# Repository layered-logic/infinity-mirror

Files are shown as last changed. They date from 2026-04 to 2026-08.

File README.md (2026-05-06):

---
title: Infinity Mirror — Project README
type: overview
status: active
tags: [readme, overview]
---

# Infinity Mirror

### A Human-Centered Design Engineering Venture by [Layered Logic](https://github.com/layered-logic)

---

> *Design a system, not just a gadget.*

An ESP32-powered infinity mirror built from the ground up — not just as a piece of hardware, but as a **complete product system**: interaction design, sustainable manufacturing, made-to-order operations, and a venture-ready business model.

This repository documents the full journey from prototype to pre-production, serving as both an engineering portfolio and a living product development case study.

---

## The Product

| | |
|---|---|
| **What** | App-connected LED infinity mirror with customizable patterns and colors |
| **How** | ESP32 microcontroller, WS2812B addressable LEDs, BLE/Wi-Fi, native mobile app |
| **Why** | Personalized ambient lighting that reflects the owner — standard designs or fully bespoke |

**Base model:** 6" x 6" — standard designs starting at $50
**Custom:** Bespoke shapes, sizes, patterns, and frame materials — designed with the customer

---

## What Makes This Different

This isn't just a build log. Every design decision is grounded in **human-centered design engineering**:

- **Stakeholder Mapping** — Understanding everyone who touches the product, from buyer to end-of-life
- **Sustainability Audit** — Full life cycle analysis. Replaceable LEDs. Recyclable frames. Documented environmental impact
- **Right-to-Repair** — A published repair guide so owners can maintain their own mirrors
- **Service Blueprint** — The complete user journey mapped from discovery to daily use to troubleshooting
- **User Research** — Real conversations with real people shaping every interface and business decision

---

## Project Structure

```
├── sprint_plan.md          # 11-week development sprint (Spring 2026), narrative
├── sprint_log.md           # Daily progress narrative
├── tasks.md                # Structured task registry (LL-NNN IDs, status, dates)
├── task_log.md             # Append-only event history
├── tools/                  # Internal business utilities
│   └── pricing/            # Streamlit COGS/pricing calculator dashboard
├── Firmware/               # ESP32 firmware (V1) + STM8 reference (Basic SKU)
├── App/                    # React Native mobile app (LLogic)
├── docs/                   # HCDE deliverables, business model, specs, case study
│   ├── task-format-v2.md   # Task ID scheme + registry format spec
│   ├── stakeholder-map
│   ├── sustainability-audit
│   ├── repair-index        # Sub-MOC for the repair docs
│   ├── service-blueprint
│   └── venture-readiness
├── Failure_Modes/          # 17 failure-mode files with user-repair paths
├── Assembly_docs/          # Production line operations
└── assets/                 # Product photography, brand identity, media
```

Tasks carry stable `LL-NNN` IDs (e.g., `LL-001`, `LL-035-2-1`). Sprint plan and log reference them inline as `[LL-NNN](tasks.md#LL-NNN)`; the registry is the structured source of truth, the narrative files are the human-readable story. Format spec at [docs/task-format-v2.md](docs/task-format-v2.md).

---

## Milestones

| Target | Milestone |
|---|---|
| Apr 18 | Business foundation — competitive analysis, pricing model, stakeholder map, sustainability goals |
| May 9 | Brand identity finalized, app UI designed, PCB hardware validated, supply chain mapped |
| May 30 | Go-to-market ready — service blueprint, repair manual, media assets, pre-production mirror built |
| Jun 12 | Portfolio case study complete. Venture readiness delivered. **Launch-ready.** |

---

## Tech Stack

| Layer | Technology |
|---|---|
| Microcontroller | ESP32 (Wi-Fi + BLE) |
| LEDs | WS2812B (Neopixel-compatible) addressable RGB |
| PCB Design | KiCad |
| Firmware | C/C++ (PlatformIO) |
| Mobile App | TBD — native (iOS/Android) |
| 3D Visualizer | React + Three.js (React Three Fiber) |
| Prototyping | Figma (app UX/UI) |

---

## Background

This project evolved from several earlier experiments:

- An **STM8 LED controller** with button-driven color cycling and animations
- A **React Three.js visualizer** for previewing mirror designs in 3D
- An **ESP32 strip tester** for validating LED configurations
- **Custom KiCad PCB designs** for a purpose-built infinity mirror controller

The independent study takes these building blocks and asks: *What would it take to turn this into a real, sellable, supportable product — and do it responsibly?*

---

## License

TBD

---

## Navigating This Repo

- [**index.md**](index.md) — Map of Content / home note (start here for any session)
- [Sprint Plan](sprint_plan.md) · [Sprint Log](sprint_log.md) — 11-week plan and daily narrative
- [Task Registry](tasks.md) · [Task Event Log](task_log.md) · [Format Spec](docs/task-format-v2.md) — structured task tracking
- [docs/](docs/) — HCDE artifacts, business, engineering, meeting logs
- [Assembly_docs/](Assembly_docs/) — production-line ops
- [assets/](assets/) — design assets (logo, color, type, photos, Figma exports)
- [tools/](tools/) — internal utilities (pricing calculator)

---

<p align="center"><em>Layered Logic — Spring 2026</em></p>

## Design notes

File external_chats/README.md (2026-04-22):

---
title: External Chats — Archive
type: asset-folder
status: active
tags: [external-chat, archive]
---

# External Chats — Archive

Exports of AI conversations (Gemini, Claude, etc.) that produced artifacts now living in `docs/` or `Assembly_docs/`. Kept for provenance and for future sessions that need to replay the reasoning.

## Convention

Each chat is stored as both the raw export (`.json` for Gemini exporter, `.md` for Claude sessions) **and** a companion `.md` file with:
- YAML frontmatter (`type: external-chat-log`, `source:`, `exported:`, `status:`, `tags:`)
- A `## Summary` section linking to the artifacts the conversation produced
- The full conversation body rendered as `### User` / `### Gemini` (or `### Claude`) headers

`status: superseded` on a chat means a later export of the same thread exists — prefer the superseding file.

## Files

| Chat | Date | Source | Produced |
|---|---|---|---|
| [Gemini-Market_Research.md](Gemini-Market_Research.md) | Apr 6 | Gemini | Stakeholder map + Market Analysis Report |
| [Gemini-Sharing GitHub Repos with Gemini.md](Gemini-Sharing%20GitHub%20Repos%20with%20Gemini.md) *(superseded)* | Apr 2 | Gemini | — earlier partial export of the same thread |
| [Gemini-Small Business Bank Account Recommendation.md](Gemini-Small%20Business%20Bank%20Account%20Recommendation.md) | Apr 9 | Gemini | Mercury/Chase/Relay evaluation → bank application |
| [LED_Mirror_Project_Brief.md](LED_Mirror_Project_Brief.md) | Apr 14 | Claude | Factory operations plan + Assembly_docs/ artifacts |

## Regenerating markdown from JSON

`convert_chats.py` in this folder converts Gemini JSON exports to markdown. Summaries are configured by hand inside the script (they require reading the thread) — add a new entry to the `configs` list before running it on a new export.

```bash
cd external_chats && python convert_chats.py
```

## Related

- [Sprint Log](../sprint_log.md) · [Sprint Plan](../sprint_plan.md)
- [docs/stakeholder-map.md](../docs/stakeholder-map.md) · [docs/Market Analysis Report.md](../docs/Market%20Analysis%20Report.md)

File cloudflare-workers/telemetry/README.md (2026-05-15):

---
title: Telemetry Worker — deploy + test
type: engineering
phase: 2
tags: [server, cloudflare, telemetry, LL-057-C]
---

# `ll-mirror-telemetry` Cloudflare Worker

Accepts opt-in telemetry beacons from Layered Logic mirrors on
`telemetry.layeredlogic.cc/v1/beacon`. Stores each beacon in a KV
namespace with a 90-day TTL plus a no-TTL "latest snapshot per device"
pointer. Firmware emission lives in [firmware-spec §4.10](../../docs/firmware-spec.md),
implementation tracked by [LL-057-C](../../tasks.md#LL-057-C).

## First-time setup

```powershell
cd cloudflare-workers/telemetry
npm install                                  # pull wrangler + workers-types
npx wrangler login                           # browser auth into Bill's CF account
npx wrangler kv namespace create LL_TELEMETRY_KV
# → copy the id into wrangler.toml's [[kv_namespaces]] block
npx wrangler deploy                          # first deploy publishes the worker
```

Then in the Cloudflare dashboard:
1. Add the route `telemetry.layeredlogic.cc/v1/*` → Worker `ll-mirror-telemetry`.
2. Add a DNS CNAME `telemetry` → `<workers-subdomain>.workers.dev` (or use Custom Domain).
3. Verify with the healthz endpoint:
   ```powershell
   curl https://telemetry.layeredlogic.cc/v1/healthz
   # → {"ok":true,"service":"ll-mirror-telemetry"}
   ```

## Beacon schema

```json
{
  "v": 1,
  "device_id": "b2332c",
  "fw_version": "651afe8-dirty",
  "uptime_s": 12345,
  "heap_free_min": 89000,
  "boot_reason": "POWERON_RESET",
  "rssi": -52,
  "led_count": 66,
  "panic": {
    "filename": "main.c",
    "line": 42,
    "task_name": "state_bus"
  }
}
```

- `device_id` is the firmware's `ll_device_id_get()` — lowercase 6-hex MAC suffix.
- `fw_version` matches `esp_app_get_description()->version`.
- `panic` is omitted when no panic happened since the last successful beacon.

The Worker validates shape strictly (rejects garbage with 400) but
tolerates extra fields silently for forward-compatibility.

## Endpoints

| Method | Path | Purpose |
|---|---|---|
| `POST` | `/v1/beacon` | Submit a beacon. Returns `{ok, stored_at}` or `{ok:false, error}`. |
| `GET` | `/v1/healthz` | Liveness probe. Always 200. |
| `GET` | `/v1/latest/<device_id>` | Return the latest beacon for one device. 404 if none yet. |

## Test with a mock beacon

```powershell
curl -X POST https://telemetry.layeredlogic.cc/v1/beacon `
  -H 'content-type: application/json' `
  --data '{"v":1,"device_id":"b2332c","fw_version":"mock-0.0.1","uptime_s":42,"heap_free_min":80000,"boot_reason":"POWERON_RESET","rssi":-55,"led_count":66}'

# Then:
curl https://telemetry.layeredlogic.cc/v1/latest/b2332c
```

## Local dev (no real KV writes)

```powershell
npx wrangler dev
# → http://127.0.0.1:8787
curl -X POST http://127.0.0.1:8787/v1/beacon -H 'content-type: application/json' --data '{...}'
```

Local KV is miniflare-backed and ephemeral. To reset: stop + restart `wrangler dev`.

## Storage model

| Key pattern | TTL | Purpose |
|---|---|---|
| `beacon:<device_id>:<unix_ms>` | 90 days | One entry per submitted beacon. Enables future "last N beacons" / time-series queries via `LL_TELEMETRY_KV.list({prefix:"beacon:<id>:"})`. |
| `latest:<device_id>` | none | Most recent beacon for O(1) "is device alive + what was its state?" lookups. |

## Privacy / data retention

- Beacons are **opt-in** via the app's Settings → Telemetry toggle (`set_state {telemetry_enabled: true/false}`).
- `device_id` is a pseudonymous 6-hex MAC suffix; not linked to user identity.
- No location data, no IP retention (CF logs hold IPs briefly but we don't persist).
- 90-day TTL on per-beacon entries; latest pointer retained until overwritten by a fresh beacon.

## Auth

None on `POST /v1/beacon` for V1. The worst an attacker with a known `device_id` can do is submit false metrics. Real authentication should land alongside [LL-057-D](../../tasks.md#LL-057-D) (paired-mode HMAC), at which point the beacon envelope can carry an HMAC computed against the device's shared secret. Until then, ship as open and trust the Cloudflare-level rate limiting.

## Not yet built (deferred)

- Dashboard UI to view recent beacons.
- Alerting on panic payloads.
- Aggregation queries (heap LWM trend across devices, etc.).
- Data export (R2 dump for long-term cold storage).

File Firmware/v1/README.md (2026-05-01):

---
title: Firmware v1 — Layered Logic Infinity Mirror
type: engineering
phase: 2
status: scaffold — blink-level only
tags: [firmware, esp32, esp-idf, scaffold]
---

# Firmware v1

Greenfield proprietary firmware for the Layered Logic Infinity Mirror. Built on ESP-IDF with C. Replaces the ESPHome YAML prototype in `../ESP32/prototype_ESPHome_Version.yaml`.

Currently **scaffold only** — directory tree + blink-level `main.c` per variant. Real implementation work begins week 5.

## Architecture

See the spec docs in [../../docs/](../../docs/):
- [firmware-architecture-scoping.md](../../docs/firmware-architecture-scoping.md) — locked decisions
- [firmware-spec.md](../../docs/firmware-spec.md) — component-level spec
- [firmware-security.md](../../docs/firmware-security.md) — signing, OTA, auth, telemetry
- [control-protocol-spec.md](../../docs/control-protocol-spec.md) — wire protocol
- [button-interface.md](../../docs/button-interface.md) — UX contract

## Layout

```
Firmware/v1/
  core/                    # 80%+ of codebase — shared across variants
    led_driver/            # WS2812 via RMT
    pattern_interp/        # pattern runtime + interpreter
    button/                # debounce, gesture state machine
    state_bus/             # unified state + pub/sub
    provisioning/          # wifi_prov_mgr wrapper (BLE + SoftAP)
    transport/             # WebSocket + HTTP + BLE
    mdns/                  # discovery
    ota/                   # signed OTA + A/B rollback
    nvs/                   # persistence
    auth/                  # HMAC envelope (paired mode)
    telemetry/             # opt-in beacon
  variants/
    standard/              # Pro — no Matter
    matter/                # Pro+ — adds esp-matter stack
  boards/                  # compile-time hardware abstraction
    board.h                # abstract interface
    c6_devkit.h            # ESP32-C6-DevKitC-1 (both demo units)
    c3_devkit.h            # ESP32-C3-DevKitM-1 (V0 reference)
    prod_v1_pro.h          # Pro shipping PCB (stub — TBD at layout)
    prod_v1_pro_plus.h     # Pro+ shipping PCB (stub — TBD at layout)
  webapp/                  # device-hosted browser UI (embedded at build)
  tests/                   # host-side unit tests for pure-C modules
```

## Build targets (planned)

- `standard-c6_devkit` — Pro firmware on C6 dev board (demo)
- `standard-c3_devkit` — Pro firmware on C3 dev board (legacy V0 hardware)
- `matter-c6_devkit` — Pro+ firmware on C6 dev board (demo)
- `standard-prod_v1_pro` — Pro shipping (pending PCB)
- `matter-prod_v1_pro_plus` — Pro+ shipping (pending PCB)

## Status

Every source file is currently a stub. This scaffold exists to:
- Lock the directory structure so spec docs have a concrete target
- Make `idf.py build` work from day one (even if all it does is print "hello")
- Let CI spin up per-variant build jobs as modules get real implementations

## Building

PowerShell only — see [reference_esp_idf_setup memory](../../.claude/projects/C--Users-bowhi-Desktop-Independent-Study/memory/reference_esp_idf_setup.md). git-bash isn't supported by the IDF Windows installer's wrapper scripts.

```powershell
$env:IDF_TOOLS_PATH = "C:\Espressif"
& "C:\Espressif\frameworks\esp-idf-v5.5.4\export.ps1"
cd Firmware\v1
```

**First build in a fresh worktree** — two prerequisites the build won't auto-handle:

```powershell
# 1. Webapp dist must exist before idf.py build runs (webapp_assets component
#    embeds the gzipped output). Skip this and CMake fails with
#    "Webapp asset missing: webapp/dist/index.html.gz".
cd webapp
npm install
npm run build
cd ..

# 2. Pick the board + chip target. CMakeLists defaults to c6_devkit / esp32c6.
#    The XIAO ESP32-C3 prototype needs c3_devkit / esp32c3 instead — and
#    set-target must be passed BOTH the board flag and the chip target;
#    skipping it means the build silently uses the previous target from
#    the local sdkconfig. Verify before assuming:
idf.py -DLL_BOARD=c3_devkit set-target esp32c3
Select-String "^CONFIG_IDF_TARGET=" sdkconfig    # should print esp32c3

# 3. Build. Pass PROJECT_VER explicitly when iterating over OTA — esp_https_ota
#    rejects images whose version string equals the running version
#    (ESP_ERR_INVALID_VERSION), and `git describe --dirty` produces the same
#    suffix when only uncommitted changes differ between iterations.
idf.py -DLL_BOARD=c3_devkit -DPROJECT_VER="iter-$(Get-Date -Format yyMMdd-HHmm)" build
```

**Subsequent builds** in the same worktree — just `idf.py build`. The board + target persist in the (gitignored) sdkconfig.

**Switching chip targets** (e.g. C3 ↔ C6) — must `Remove-Item sdkconfig` first; `set-target` doesn't reliably overwrite a sdkconfig from a previous chip.

## Flashing

USB: `idf.py -p COM<n> flash monitor`

OTA: see [docs/ota-dev-runbook.md](../../docs/ota-dev-runbook.md) — host the bin via `python -m http.server 8000` in `build/`, send `start_ota` from the app or wscat.

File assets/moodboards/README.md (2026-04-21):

---
title: Moodboards — Brand References
type: asset-folder
status: active
tags: [brand, moodboard, references, research]
---

# Moodboards — Brand References

Five external references provided by Bill (Apr 20, 2026) that informed the locked brand direction. This file is the **link + one-line summary index**; full per-reference analysis (palette, type, layout, signature devices, pulls, anti-moves) lives in [docs/brand-research-notes.md](../../docs/brand-research-notes.md).

Image captures of each reference should be added to this folder as `reference-{n}-{slug}.png` for offline reference — useful if a case-study URL changes or goes dead.

---

## The five references

### 1. Paris Electronic Week 2022 — Diplomatie Studios
[the-brandidentity.com](https://the-brandidentity.com/project/diplomatie-studios-identity-for-paris-electronic-week-2022-is-a-kaleidoscopic-collision-of-colour)

Kaleidoscopic CMYK collisions (electric magenta, acid yellow, cyan) pinned by rigid typographic frames. **Pull:** the "light bleed pinned under a hard type lockup" move. **Avoid:** multi-hue rainbow — would dilute the indigo anchor.

### 2. SPRING Performing Arts Festival — LAVA
[lava.nl](https://lava.nl/progress/spring-performing-arts-festivals-new-identity/)

Soft photographic gradient blobs ("spring bloom") used as a recurring container, paired with crisp editorial typography. **Pull:** the soft color-field shape as a recurring container (signature device #4 in the brand system). **Avoid:** pastel warmth and book-like whitespace.

### 3. Adam Ho — Personal site + Archetype interview
[adamho.com](https://www.adamho.com/) · [archetype.fund interview](https://www.archetype.fund/media/in-conversation-with-adam-ho)

Bill's reference for a disciplined solo-founder personal-brand voice. Relevant as a model for the Layered Logic parent-brand posture while the venture is still solo.

### 4. Intrinsic — Pentagram identity + Felix Faire generative system
[pentagram.com](https://www.pentagram.com/work/intrinsic) · [felixfaire.com](https://felixfaire.com/work/intrinsic)

**The primary "gradients + hard outlines" reference.** Volumetric soft gradients (fog, light fields) sitting *behind* razor-thin wireframe geometry — two layers that never blend. **Pull:** the visual logic of wireframe-over-bloom (signature device #3). **Avoid:** the heavy 3D rendering workload — adopt the grammar, don't out-render a CG studio.

### 5. IBM Quantum — Field.io brand visuals
[field.io](https://field.io/work/ibm-quantum-brand-visuals)

Scientific-instrument framing — flowing ribbon gradients "annotated" with mono labels and tick marks at the edges. The "annotated sublime." **Pull:** the annotation layer — mono labels, tick marks, thin rules (signature device #2, the mono tick-mark frame). **Avoid:** IBM blue — the anchor here is indigo (cooler, more saturated).

---

## Shared grammar extracted from these five

From [brand-research-notes.md §Synthesis](../../docs/brand-research-notes.md):

> Soft volumetric color (gradient, fog, bloom, light field) treated as the *subject*, pinned and measured by a hard, precise typographic/geometric overlay. The soft thing is ambient and emotional; the hard thing is technical and first-person. **Tension between the two is the brand.**

The five references converge on: dark-mode ground, one saturated anchor color (for this brand, Indigo Reference `#4A25FF`), disciplined grotesque + mono type pairing, and hard 1px rules framing soft gradient bloom.

---

## To add

- [ ] `reference-1-paris-electronic-week.png` — screenshot capture of case study
- [ ] `reference-2-spring-lava.png` — screenshot of festival identity
- [ ] `reference-3-adam-ho.png` — personal site hero + interview capture
- [ ] `reference-4-intrinsic-pentagram.png` + `reference-4-intrinsic-felix-faire.png` — identity + motion captures
- [ ] `reference-5-ibm-quantum.png` — Field.io case study capture

Keep captures at reasonable resolution (~1920px wide); these are for offline reference and brand-narrative documents, not production imagery.

---

## Related

- [docs/brand-research-notes.md](../../docs/brand-research-notes.md) — full per-reference analysis and five signature visual devices
- [docs/brand-positioning.md §5](../../docs/brand-positioning.md) — decisions informed by these references
- [assets/README.md](../README.md) — folder conventions across all design assets

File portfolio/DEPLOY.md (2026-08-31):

# Portfolio — "Process" (LL-061) · deploy & embed

Self-contained static page (`index.html` + `assets/`). Hosted on **Cloudflare Pages**.

- **Project:** `layered-logic-process` (account: bowhite9317@gmail.com)
- **Production URL:** https://layered-logic-process.pages.dev/
- **Intended custom domain:** `process.layeredlogic.cc` (see below)

## Redeploy (after editing the page)

From the repo root, with wrangler authenticated (`npx wrangler whoami`):

```bash
npx wrangler pages deploy portfolio --project-name=layered-logic-process --branch=main --commit-dirty=true
```

Only the `portfolio/` folder is uploaded — nothing else from the repo. Each run prints a unique
preview URL; the production URL above always serves the latest `main` deploy.

## Custom domain (process.layeredlogic.cc)

DNS for layeredlogic.cc is on Cloudflare, so this is one step:
Dashboard → Workers & Pages → `layered-logic-process` → Custom domains → **Set up a domain** →
`process.layeredlogic.cc` → Cloudflare auto-creates the CNAME and provisions the cert.

## Embed in Framer (auto-resizing)

Framer → Assets → Code → New Component. The page broadcasts its height via `postMessage`
(`{type:"ll-process-height", height}`) on load, resize, image load, and every node expand/collapse,
so the frame grows with the content (including when a visitor opens a node).

```tsx
import { useState, useEffect } from "react"

export default function ProcessEmbed() {
    const [height, setHeight] = useState(4000)
    useEffect(() => {
        function onMsg(e: MessageEvent) {
            if (e.data?.type === "ll-process-height" && typeof e.data.height === "number") {
                setHeight(e.data.height)
            }
        }
        window.addEventListener("message", onMsg)
        return () => window.removeEventListener("message", onMsg)
    }, [])
    return (
        <iframe
            src="https://layered-logic-process.pages.dev/"
            style={{ width: "100%", height, border: 0, display: "block" }}
            title="Layered Logic — Process"
            scrolling="no"
        />
    )
}
```

Set the component to full-width on the Framer page. Swap `src` to the custom domain once it's live.

### Note on sticky headers
With auto-height (frame grows to full content, parent page scrolls), the page's sticky lane/phase
headers won't pin — they scroll by like normal content. That's the right feel for an embedded story.
If you'd rather keep them pinned, give the iframe a fixed height (e.g. `height: "90vh"`) so it
scrolls internally instead.

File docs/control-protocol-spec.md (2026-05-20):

---
title: Control Protocol Spec — App ↔ Device
type: engineering
phase: 2
week: 4
date: 2026-04-22
status: draft — initial lock from firmware-architecture-scoping §5.5 decision
tags: [engineering, firmware, protocol, websocket, ble, http]
---

# Control Protocol Spec — App ↔ Device

**Prepared by:** William White
**Date:** April 22, 2026
**Status:** First draft — defines the shared wire protocol used by mobile app, webapp, and any third-party controller

---

## 1. Purpose

This spec defines the **wire protocol** between controllers (LL mobile app, webapp, HA custom integration, third-party clients) and the mirror firmware.

It is transport-agnostic: the same message envelope rides over WebSocket, HTTP, and BLE. Client implementations should target this spec — not the transports directly — so that fallback between transports (Wi-Fi → BLE) doesn't require protocol rework.

Implements [firmware-architecture-scoping §5.5](firmware-architecture-scoping.md#55-app--device-protocol). Auth model detailed in [firmware-security.md §5](firmware-security.md#5-local-authentication).

---

## 2. Transports

Three transports, same envelope across all.

| Transport | When | Endpoint | Notes |
|---|---|---|---|
| **WebSocket** | Primary runtime; controller on same LAN as device | `ws://<host>/ws` on port 80 | Bidirectional, state broadcasts to all connected clients |
| **HTTP REST** | One-shot ops; scripts, shortcuts, webapp boot | `http://<host>/api/*` on port 80 | No persistent connection; device responds synchronously |
| **BLE GATT** | Fallback when no Wi-Fi or during pairing | Custom service UUID (TBD) | Same message envelope wrapped in BLE notify/write |

### 2.1 Discovery order

Client should try in sequence:
1. **Cached last-known IP** from NVS or app storage (instant, stale-tolerant)
2. **mDNS query** for `_layeredlogic._tcp.local.` on local network
3. **BLE scan** for the device's advertised service UUID (only finds the device if it's in pairing mode OR running its BLE fallback mode due to Wi-Fi being down)

No manual IP entry in V1. If all three fail: UI surfaces a diagnostic ("device unreachable — check Wi-Fi or hold reset button to re-pair").

### 2.2 mDNS record

Published by device when Wi-Fi connected:
- Service: `_layeredlogic._tcp.local.`
- Hostname: `layered-logic-mirror-<device_id_short>.local`
- TXT record: `variant=standard|matter`, `version=<fw_version>`, `id=<device_id_short>`, `auth=open|paired`

Clients filter on service type + optional `id` to find a specific device among multiple.

---

## 3. Message Envelope

All messages — request and response, WebSocket and HTTP and BLE — use the same envelope.

### 3.1 Request envelope

```json
{
  "op": "set_state",
  "req_id": "7b3c...",
  "ts": 1745280000,
  "payload": { ... },
  "hmac": "<hex>"
}
```

| Field | Type | Required | Description |
|---|---|---|---|
| `op` | string | yes | Operation name — see §4 |
| `req_id` | string (UUIDv4) | yes | Client-generated. Device echoes in response for correlation. |
| `ts` | int | yes | Monotonic counter; epoch seconds recommended. In paired mode the device rejects a frame whose `ts` is below the highest already accepted on that connection (`stale_ts`). No absolute-time check — the device has no wall clock. See [firmware-security §5.4](firmware-security.md#54-hmac-envelope). |
| `payload` | object | varies | Op-specific data — see §4 |
| `hmac` | string (hex) | only in paired mode | HMAC-SHA256 over the frame text preceding the `,"hmac":` token (`hmac` is always the last key), keyed on the shared secret. Required in paired mode; ignored in open mode. |

### 3.2 Response envelope

```json
{
  "op": "set_state",
  "req_id": "7b3c...",
  "ok": true,
  "result": { ... },
  "error": null
}
```

| Field | Type | Description |
|---|---|---|
| `op` | string | Echoes the request op |
| `req_id` | string | Echoes the request req_id |
| `ok` | bool | Success flag |
| `result` | object \| null | Op-specific result on success |
| `error` | object \| null | `{ code, message }` on failure |

### 3.3 State broadcast envelope

When device state changes (from any controller input including physical button), device broadcasts to **all connected WebSocket clients**:

```json
{
  "op": "state",
  "ts": 1745280000,
  "state": { ... current full state ... }
}
```

No `req_id` (unsolicited). No `hmac` on broadcasts (broadcasts are authoritative device state, not commands — HMAC is for authenticating commands, not facts).

---

## 4. Operations

### 4.1 Core operations (required on all transports)

| Op | Description | Request payload | Response result |
|---|---|---|---|
| `ping` | Liveness check | `{}` | `{ "fw_version": "...", "uptime_s": 12345 }` |
| `get_state` | Fetch current full state | `{}` | State object — see §5 |
| `set_state` | Partial state update | Partial state object | Updated state object |
| `get_info` | Device metadata | `{}` | `{ device_id, variant, hw_board, fw_version, led_count, auth_mode }` |

### 4.2 Pattern operations

| Op | Description | Request payload | Response result |
|---|---|---|---|
| `list_patterns` | List stored patterns | `{}` | `{ "patterns": [{ id, name, builtin }] }` |
| `get_pattern` | Fetch one pattern definition | `{ "id": "..." }` | Pattern definition — see §6 |
| `upload_pattern` | Add or replace a pattern | Pattern definition | `{ "id": "..." }` |
| `delete_pattern` | Remove a user pattern | `{ "id": "..." }` | `{}` |

### 4.3 Auth operations

| Op | Description | Request payload | Response result |
|---|---|---|---|
| `set_auth_mode` | Change between open + paired | `{ "mode": "open"\|"paired", "secret": "..." }` | `{ "mode": "..." }` |
| `rotate_secret` | Change shared secret (paired mode only) | `{ "old_secret": "...", "new_secret": "..." }` | `{}` |

### 4.4 OTA operations

| Op | Description | Request payload | Response result |
|---|---|---|---|
| `get_update_status` | Is there an update? | `{}` | `{ available: bool, version: "...", changelog: "..." }` |
| `apply_update` | User-triggered update now | `{}` | `{}` — device reboots into new version |

### 4.5 Telemetry operations

| Op | Description | Request payload | Response result |
|---|---|---|---|
| `set_telemetry` | Enable / disable | `{ "enabled": bool }` | `{ "enabled": bool }` |
| `peek_telemetry` | View pending beacon | `{}` | The exact bytes that would be sent next |

---

## 5. State Object

The canonical state object returned by `get_state` and broadcast on change:

```json
{
  "on": true,
  "pattern_id": "color_wipe",
  "base_color": "#3214FF",
  "brightness": 80,
  "led_count": 32,
  "auth_mode": "open",
  "telemetry_enabled": false,
  "id": "b2332d",
  "name": "Living Room"
}
```

| Field | Type | Description |
|---|---|---|
| `on` | bool | Power state |
| `pattern_id` | string | Currently-running pattern ID |
| `base_color` | string | Hex `#RRGGBB` — the single-press advance color (see [button-interface §4.3](button-interface.md#43-base-color-cycle-single-press-semantics)) |
| `brightness` | int (0–100) | One of the 4 discrete steps: 25 / 50 / 75 / 100 |
| `led_count` | int | Read-only (set at provisioning or from board header) |
| `auth_mode` | string | `"open"` or `"paired"` |
| `telemetry_enabled` | bool | User opt-in status |
| `id` | string | Read-only. Lowercase 6-hex MAC suffix — same suffix the mDNS hostname and SoftAP SSID expose. Stable across factory resets. |
| `name` | string | User-set device name; empty when unnamed. Settable via `set_state`. Clients display `name` if non-empty, else fall back to `id`. |

Partial updates via `set_state` — send only the fields changing. Device broadcasts full state after every change.

`id` is read-only and cannot be set via `set_state`; setting `name` is the user-rename surface.

---

## 6. Pattern Definition Format

### 6.1 V1 — built-in patterns only

V1 ships with 7 hardcoded patterns, fully defined in [pattern-dictionary.md](pattern-dictionary.md). Their IDs (wire format):

`solid`, `rainbow`, `scanner`, `spinner`, `random`, `breathing`, `twinkle`

`list_patterns` returns these with `builtin: true`. `upload_pattern` and `delete_pattern` return `error: "unsupported_in_v1"` until V2.

### 6.2 V2 — declarative user-uploaded patterns (deferred)

Shape (illustrative, not final):

```json
{
  "id": "my_pattern",
  "name": "My Pattern",
  "uses_base_color": true,
  "frames": [
    { "duration_ms": 100, "leds": [["base", 0, 1, 2], ["off", 3, 4, 5]] },
    { "duration_ms": 100, "leds": [["off", 0, 1, 2], ["base", 3, 4, 5]] }
  ],
  "loop": true
}
```

Full grammar gets its own spec doc when the app's pattern-editor UI is designed. Deferred because no V1 client produces these — app doesn't exist yet.

**Upload size limit (when V2 ships):** 16KB per pattern (NVS budget). Larger patterns rejected with `error: "pattern_too_large"`.

---

## 7. Transport-Specific Details

### 7.1 WebSocket

- Endpoint: `ws://<host>/ws`
- Max concurrent clients: **8**. Ninth connection refused with close code 1013 ("try again later").
- Per-IP rate limit: 10 messages/sec. Exceeding results in close code 1008.
- Ping/pong: device sends ping every 30s, closes connection if no pong within 60s.
- On state change (from any source): device broadcasts `{"op":"state", ...}` to all connected clients.

### 7.2 HTTP REST

Convenience wrapper over ops. Every op reachable via HTTP for curl-friendliness:

| Method + path | Op |
|---|---|
| `GET /api/state` | `get_state` |
| `POST /api/state` | `set_state` (body = payload) |
| `GET /api/info` | `get_info` (V1: tiny discovery payload — see below) |
| `POST /api/ping` | `ping` |
| `GET /api/patterns` | `list_patterns` |
| `POST /api/patterns` | `upload_pattern` |
| `DELETE /api/patterns/:id` | `delete_pattern` |

**V1 `GET /api/info` (implemented):** lightweight HTTP-only sentinel + identity payload, used by the LL app's subnet-scan discovery to (a) confirm an IP is a Layered Logic mirror and (b) read its `id` + `name` for the multi-mirror picker without opening a WebSocket. Response shape:

```json
{ "product": "layered-logic-mirror", "id": "b2332d", "name": "Living Room", "fw_version": "1b86d5e" }
```

Returned with `Content-Type: application/json` and `Access-Control-Allow-Origin: *` (no secrets — same identity already advertised over mDNS). The full V2 `get_info` op (board variant, hardware revision, etc.) extends this shape additively.

Envelope fields (`req_id`, `ts`, `hmac` when paired) sent as HTTP headers:
- `X-LL-Req-Id: <uuid>`
- `X-LL-Ts: <epoch>`
- `X-LL-Hmac: <hex>` (paired mode only)

HTTP responses return the bare `result` object with HTTP status (200 ok, 400 bad op, 401 bad hmac, 403 rate limit, etc.).

### 7.3 BLE GATT

Minimal surface. Only used during provisioning or as fallback when Wi-Fi is unavailable.

- Service UUID: TBD (assign from 128-bit private range)
- Characteristic: `cmd` (write + notify) — client writes request envelope as JSON bytes, device notifies response on the same characteristic.
- MTU: request 185 bytes; if negotiated lower, client must chunk and send with continuation flag in `req_id`.
- No state broadcasts over BLE (would thrash battery) — client must poll `get_state` if using BLE as runtime transport.

---

## 8. Error Codes

| Code | Meaning |
|---|---|
| `unknown_op` | Op not recognized by this firmware version |
| `bad_payload` | Missing or malformed field in payload |
| `auth_required` | Paired mode enabled, no HMAC provided |
| `bad_hmac` | HMAC did not verify |
| `stale_ts` | Frame rejected by the paired-mode replay guard: `ts` below the last accepted on the connection, or a duplicate `req_id` |
| `rate_limit` | Per-IP message rate exceeded |
| `pattern_too_large` | Pattern exceeds 16KB |
| `nvs_full` | Pattern storage full |
| `unsupported_variant` | Op requires Matter variant but device is standard |
| `internal` | Unhandled firmware error (should be rare; log + telemetry if opt-in) |

---

## 9. Versioning

- Protocol version surfaced via `get_info` as `proto_version`.
- V1 is `"1.0"`.
- Breaking changes bump major; additive changes (new ops, new fields) bump minor.
- Clients must tolerate unknown fields in responses (forward compatibility).

---

## 10. Out Of Scope

- Pattern grammar (separate spec, written alongside firmware pattern interpreter)
- Matter protocol messages (handled by `esp-matter` stack, not this protocol)
- OTA binary format (see [firmware-security.md §3](firmware-security.md#3-ota-security))
- Remote-access tunneling (V2)

---

## Related

- [Firmware Architecture Scoping §5.5](firmware-architecture-scoping.md#55-app--device-protocol) — source decision
- [Firmware Security Model §5](firmware-security.md#5-local-authentication) — auth envelope details
- [Firmware Spec](firmware-spec.md) — device-side implementation
- [Pattern Dictionary](pattern-dictionary.md) — V1 pattern definitions (shared across firmwares)
- [App Spec](app-spec.md) — mobile client implementation
- [Webapp Spec](webapp-spec.md) — browser client implementation

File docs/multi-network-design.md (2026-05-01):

---
title: Multi-Network Wi-Fi Design
type: engineering
phase: 2
week: 6
date: 2026-05-01
status: spec — implementation-ready, decisions locked May 1
tags: [engineering, firmware, protocol, wifi, provisioning, app]
---

# Multi-Network Wi-Fi Design

**Prepared by:** William White
**Date:** May 1, 2026
**Status:** Locked. All §10 questions answered May 1; ready for step-1 NVS layer implementation.

---

## 1. Purpose

Today the mirror remembers exactly **one** Wi-Fi network. Re-provisioning to a new SSID erases the old one. Customers who move the mirror between locations (home ↔ office, take it to a friend's, bring it on a trip) have to re-run setup every time.

This doc specifies a multi-network design: the mirror remembers up to N saved Wi-Fi networks and joins whichever one is in range on boot or after disconnect.

Implements a feature gap discovered during [project_app_stack.md] usability work in week 5.

---

## 2. Non-Goals

- **Network roaming** (handing off between two BSSIDs of the *same* SSID): out of scope. ESP-IDF has separate APIs for that; we don't need it for the customer story.
- **Enterprise / 802.1X**: out of scope. WPA2-PSK and open networks only — same as today.
- **Hidden SSIDs**: out of scope for V1. Adds a probe-by-name code path that's annoying to test and unnecessary for the target customer.
- **Per-network preferences** (e.g. dim by default at the office): out of scope. Networks are just connection profiles, not user-config keys.

---

## 3. Current State (what we're replacing)

| Layer | Today |
|---|---|
| **Firmware storage** | One `wifi_config_t` written to `esp_wifi`'s NVS namespace via `esp_wifi_set_config(WIFI_IF_STA)` ([provisioning.c:329-355](Firmware/v1/core/provisioning/provisioning.c)). Overwrites on every `set_wifi_creds`. |
| **Boot behavior** | If `esp_wifi` reports a saved cred → start STA → connect. Otherwise stay dark, wait for provisioning. |
| **Reconnect** | Retry the *same* SSID on disconnect. After `LL_APPLY_FALLBACK_US` (15s) of failure during cred-apply, wipe and fall back to SoftAP. |
| **Wire protocol** | `set_wifi_creds {ssid, password}` — single network at a time. |
| **App UX** | One SSID/password form in setup; "Reconfigure Wi-Fi" replaces the saved network. |

---

## 4. Target UX

### 4.1 Provisioning (first run, unchanged)

User joins SoftAP, opens the app, enters one network's creds. Mirror joins that network. **No change** — the multi-network feature is about *adding* networks after the first one, not changing first-run setup.

### 4.2 Adding a second network (new flow)

From Settings → Wi-Fi:

```
Networks
┌──────────────────────────────────┐
│ ✓ HomeWiFi          (connected)  │
│   OfficeWiFi                     │
│ + Add a network                  │
└──────────────────────────────────┘
```

Tapping "Add a network" surfaces an SSID/password form. On submit, the mirror:
1. Saves the new entry to its own NVS list (does **not** overwrite the active connection).
2. Stays on the currently-connected network — adding doesn't trigger a switch.

### 4.3 Removing a network

Swipe-to-delete or row-detail "Forget" button.

If the network being removed is **not** currently connected: forget silently, no prompt.

If the network being removed **is** currently connected: surface a confirm dialog ("Forget HomeWiFi? The mirror will disconnect from this network.") before any action. On confirm, the mirror proactively disconnects and falls into the SCANNING flow. This is a deliberate departure from iOS/macOS's passive behavior — if the user says forget, we respect that immediately rather than letting them wonder why nothing happened.

### 4.4 Boot / reconnect behavior (no UI)

On boot or after STA disconnect, the mirror:
1. Runs a passive scan (2-4s).
2. Picks the highest-priority saved network whose SSID appears in scan results.
3. Connects.
4. If connect fails, marks that entry as "recently failed" (in-RAM only, cleared on reboot) and tries the next match.
5. If no saved networks are visible, retries scan with backoff (5s, 15s, 60s, 60s…) until one appears. **The mirror does not auto-fall-back to SoftAP** — the user must put it into pairing mode by holding the recessed button (existing flow). Rationale: avoid polluting the space with unnecessary RF advertisements when the device is just out of range or the user doesn't intend to use it on a new network.

---

## 5. Storage Layout

### 5.1 NVS

New namespace `ll_wifi` (separate from `ll_settings` to keep concerns isolated; separate from `esp_wifi`'s namespace because that one is owned by the IDF's prov_mgr and we shouldn't share it).

```
ll_wifi/
  count       u8        — number of valid entries (0..N_MAX)
  entry_0     blob      — packed wifi_entry_t
  entry_1     blob      — packed wifi_entry_t
  ...
  active_idx  u8        — index of last-successfully-connected entry (0xFF = none)
```

```c
typedef struct __attribute__((packed)) {
    char     ssid[33];      // 32 + null
    char     password[65];  // 64 + null; empty = open network
    int64_t  last_used_us;  // esp_timer_get_time() at last successful connect
} wifi_entry_t;
```

Storing entries as separate blobs (vs. one big blob) means add/remove only rewrites one key, not the whole list — friendlier to flash wear and to partial-write recovery.

### 5.2 Capacity

`N_MAX = 4`. Rationale: realistic personal-use ceiling (home, work, parents, one travel hotspot). Each entry is ~106 bytes packed; 4 entries = ~424 B + small NVS overhead.

If a 5th add comes in, response is `wifi_list_full` error — let the user decide what to evict rather than picking for them. Easy to bump later if real usage proves the cap is too tight; hard to lower without forcing a migration.

### 5.3 Migration from current single-cred state

On first boot of multi-network firmware, if `ll_wifi` is empty AND `esp_wifi` has a saved STA cred, copy it into `ll_wifi[0]`. Don't delete the `esp_wifi` copy — the runtime still uses `esp_wifi_set_config` to connect; `ll_wifi` is the "remembered list", and `esp_wifi`'s slot is just the *currently-loaded* cred. (See §6.2 for how these stay in sync.)

---

## 6. Firmware: Connection State Machine

### 6.1 States

```
        ┌──────────────────┐
   ┌───▶│   SCANNING       │
   │    └────────┬─────────┘
   │             │ scan complete
   │             ▼
   │    ┌──────────────────┐
   │    │   PICKING        │  pick highest-priority
   │    └────────┬─────────┘  visible saved entry
   │             │
   │       ┌─────┴──────┐
   │       │            │
   │       ▼            ▼
   │  no match     match found
   │       │            │
   │       │            ▼
   │       │    ┌──────────────────┐
   │       │    │   CONNECTING     │
   │       │    └────────┬─────────┘
   │       │             │
   │       │       ┌─────┴──────┐
   │       │       │            │
   │       │       ▼            ▼
   │       │   success      timeout/fail
   │       │       │            │
   │       │       ▼            │
   │       │  ┌──────────┐      │
   │       │  │ ONLINE   │◀─────┴── (mark entry recently_failed, try next match)
   │       │  └────┬─────┘
   │       │       │ STA disconnect
   │       │       │
   │       └───────┴────────────┐
   │                            │
   │                            ▼
   │              ┌──────────────────────┐
   │              │   BACKOFF            │  5s → 15s → 60s
   └──────────────┤   (then re-scan)     │
                  └──────────────────────┘
```

Provisioning (SoftAP) is a separate top-level mode triggered **only** by recessed-button hold. BACKOFF stays in BACKOFF indefinitely — no auto-SoftAP fallback (see §10 Q3).

### 6.2 Connection-attempt mechanics

For each candidate entry:
1. `esp_wifi_set_config(WIFI_IF_STA, …)` with that entry's ssid/password.
2. `esp_wifi_connect()`.
3. Wait up to 8s (configurable) for `IP_EVENT_STA_GOT_IP`.
4. On success: write `last_used_us = now`, `active_idx = i`, post `LL_EV_WIFI_CONNECTED`.
5. On timeout/fail: mark `recently_failed[i] = true` in RAM, return to PICKING.

The "recently failed" flag is cleared on reboot and on successful connect to *any* network — so a one-off auth blip doesn't permanently shadow a network.

### 6.3 Priority

**Last-used wins.** Pick the visible saved entry with the highest `last_used_us`. Simple, matches what every consumer device does, no UI for ordering. (If §10 Q1 lands the other way, swap to explicit user-set order — the storage layout already supports it via insertion-position semantics.)

---

## 7. Wire Protocol Changes

Net-new ops, plus a soft-deprecation of `set_wifi_creds`.

### 7.1 New: `list_wifi_networks`

Request: no payload.

Response:
```json
{
  "networks": [
    { "ssid": "HomeWiFi",   "is_active": true,  "last_used": 1745280000 },
    { "ssid": "OfficeWiFi", "is_active": false, "last_used": 1745190000 }
  ]
}
```

Passwords never leave the device. Order is by `last_used` desc.

### 7.2 New: `add_wifi_network`

Request payload: `{ ssid, password }`.

Behavior:
- If SSID already exists in the list → update the password in-place (same key replaces). Returns `ok`.
- If SSID is new and `count < N_MAX` → append. Returns `ok`.
- If `count == N_MAX` → returns `ok=false, error="wifi_list_full"`.

**Does not switch the active connection.** Adding ≠ joining. (For the provisioning-time first-network case, the existing code path that switches to STA stays in place — we just write to `ll_wifi[0]` in addition to `esp_wifi`.)

### 7.3 New: `remove_wifi_network`

Request payload: `{ ssid }`.

Behavior:
- Removes the entry. If the removed entry was the active connection, the mirror **proactively disconnects** (`esp_wifi_disconnect()`) and falls into the SCANNING flow. The app surfaces a confirmation dialog before sending this op when it knows the target is the active network — see §4.3.
- Returns `ok=false, error="not_found"` if the SSID isn't in the list.

### 7.4 Existing: `set_wifi_creds` (deprecated, kept working)

Behavior change: now equivalent to `add_wifi_network` followed by an immediate switch (the old SoftAP→STA handoff in [provisioning.c:300-375](Firmware/v1/core/provisioning/provisioning.c)). Stays on the protocol so older app builds keep working through the transition.

Mark it `deprecated: true` in the protocol spec; remove in V2.

### 7.5 `DeviceState` additions

```diff
 interface DeviceState {
   ...
-  wifi_ssid?: string | null;     // currently connected SSID
+  wifi_ssid?: string | null;     // currently connected SSID (unchanged)
+  wifi_saved_count?: number;     // entries in ll_wifi
 }
```

Full list lives behind `list_wifi_networks` to keep state broadcasts small — most clients don't need it.

---

## 8. App Changes (App/v1)

### 8.1 Settings page

Replace the single "Network: HomeWiFi  /  Reconfigure Wi-Fi" block with a list rendered from `list_wifi_networks` plus an "Add a network" button. Active row gets a checkmark.

Add/remove flows reuse the existing SSID/password form component — just wire it to the new ops.

### 8.2 First-run setup (unchanged)

Setup screen still calls `set_wifi_creds` for backward compatibility. Behind the scenes the firmware writes to `ll_wifi[0]` *and* loads it into `esp_wifi`, so the first network is automatically a saved network.

### 8.3 No mDNS dependency

Multi-network is independent of the deferred mDNS work. The Find-mirror subnet scan still works on whatever network the phone is currently on.

---

## 9. Implementation Order

Sized in rough day-units. Assumes the firmware feedback loop from `feedback_verify_each_change.md` (build → flash → boot capture → sprint_log) per step.

| Step | Scope | Days |
|---|---|---|
| 1 | NVS layer: `ll_wifi.{c,h}` with add/remove/list/get-by-ssid + the migration shim from §5.3 | 1 |
| 2 | Refactor `provisioning.c` to drive STA from `ll_wifi` instead of `esp_wifi`'s saved cred | 1.5 |
| 3 | Implement SCANNING / PICKING / BACKOFF state machine | 1.5 |
| 4 | Protocol ops: `list/add/remove_wifi_network` in `transport.c`; rewrite `set_wifi_creds` as a thin wrapper | 0.5 |
| 5 | App: Settings page list UI + add/remove flow | 1 |
| 6 | End-to-end testing across 2-3 real networks (home + phone hotspot) | 0.5 |

**Total: ~6 days.** Front-loaded firmware (steps 1-3 are the risky parts).

---

## 10. Locked Decisions (May 1)

All five questions answered. Recorded here for posterity so future readers can see what was considered, not just what was chosen.

| # | Question | Decision | Why |
|---|---|---|---|
| Q1 | Priority model | **Last-used wins** | Simplest. Matches consumer-device norms. Storage layout still supports explicit ordering if we want to revisit later. |
| Q2 | Capacity (N_MAX) | **4** | Realistic personal-use ceiling per Bill (home, work, parents, travel hotspot). ~424 B in NVS. Easy to bump if real usage proves it tight. |
| Q3 | No-network-visible behavior at boot | **Stay in BACKOFF indefinitely** — no auto-SoftAP. User must trigger pairing mode via recessed-button hold. | Avoid polluting the space with unnecessary RF when the device is just out of range or the user doesn't intend to re-provision. Aligns with the product's broader "less RF noise unless asked" stance. |
| Q4 | Removing the currently-active network | **Proactive disconnect**, gated by a confirm dialog in the app. | If the user says forget, respect it immediately rather than the iOS-style "stay connected until natural disconnect" pattern, which can read as a bug. The dialog covers the "I didn't mean to disconnect" case. |
| Q5 | `set_wifi_creds` deprecation timeline | **Remove with the next firmware major** (V2). App keeps it as the first-network setup path until then. | Lets older app builds keep working through the rollout; clean break at the next NVS schema bump. |

---

## 11. References

- [control-protocol-spec.md](control-protocol-spec.md) — wire envelope this doc extends
- [firmware-spec.md](firmware-spec.md) — overall firmware module ownership
- [Firmware/v1/core/provisioning/provisioning.c](Firmware/v1/core/provisioning/provisioning.c) — current single-cred implementation
- [Firmware/v1/core/nvs/nvs.h](Firmware/v1/core/nvs/nvs.h) — namespace ownership boundary (this doc adds `ll_wifi`, leaves `ll_settings` alone)
- [App/v1/App.tsx:566-577](App/v1/App.tsx) — current single-network Settings UI being replaced

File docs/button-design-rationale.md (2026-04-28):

---
title: Button Design Rationale
type: hcde
phase: 2
week: 5
status: draft
tags: [hcde, ux, button, interface, portfolio, design-rationale]
---

# Button Design Rationale

**Author:** William White
**Date:** April 28, 2026
**Status:** Draft — pre-user-research. Will be revised once Week 5 interviews land.

This is the HCDE portfolio companion to [button-interface.md](button-interface.md). The spec doc *defines* the interface; this doc *explains* why it ended up that way — what alternatives were considered, what tensions had to be resolved, and what the choices commit me to.

---

## 1. The question I had to answer

The Layered Logic Infinity Mirror is two products at once:

- A piece of **lighting art** that lives on a wall and runs unattended for years
- A **configurable smart device** with patterns, colors, brightness, and (eventually) automations and custom designs

These two products want different control surfaces. Art wants to disappear — touch it once, then forget it. Smart devices want a screen, an app, a settings panel. The interface I ship has to serve both modes without making either feel compromised.

The question, narrowed: *what does a user touch on the device itself, and what lives in the app?*

---

## 2. Who the interface is designed for

From [brand-positioning §3](brand-positioning.md), the audience priority is:

1. **Interior Curator** — buys for fit and feel. Doesn't want to think about the device after install.
2. **Vibe-Seeker** — wants to set a mood, change with the season, occasionally tweak.
3. **Spec-Head** — wants every parameter exposed and addressable.

I weight design decisions by the priority order. Where a tradeoff favors Curator at the cost of Spec-Head ergonomics, Curator wins. Spec-Head can use the app — they will anyway. Curator may never open it.

This single ordering does most of the work in this doc.

---

## 3. The core tension

> **The mirror is a light first, a smart device second.**

The control interface has to make this true at the hardware level. If a buyer plugs in the mirror and the first thing it does is demand a Wi-Fi password, the brand promise is already broken.

Concretely, that means:

- The device must be **fully usable with no app, no account, and no network**. Every shipped pattern, every color, every brightness level — reachable with bare-hand interaction.
- Daily controls must be **readable without documentation**. If a guest visits and wants to dim the mirror, they should figure it out in under 30 seconds.
- Configuration that *changes the device's identity* (pairing, factory reset) must require **deliberate, non-accidental effort**. Someone bumping into the wall doesn't reset the firmware.

These three constraints set the shape of everything that follows.

---

## 4. The options I considered

### 4.1 App-only (no physical buttons beyond power)

The minimalist path. The mirror has a power cord and that's it; everything else lives in a phone app.

**Rejected.** Three problems:

1. **Setup friction** — to use the mirror at all, you have to install the app, create an account or pair, and connect the device to your network. That violates the "light first" principle. A user who never plugs in their phone can never use the product.
2. **Guest access** — a houseguest, roommate, or partner who doesn't have the app paired has no way to interact with the mirror. The device becomes single-user-locked, which is a strange thing for a piece of wall art to be.
3. **Long-tail control** — five years from now the app may not run on whatever phones exist. The device should outlive its app.

### 4.2 Single button (V0 prototype's model)

The V0 prototype used a single exposed button with a four-gesture grammar (single / double / triple / hold). Inherited from the STM8 Basic SKU and proven in the field.

**Kept for daily use, supplemented for rare ops.** The single-button grammar handles the daily control surface beautifully — it's tactile, requires no documentation, and the gesture mapping (single = next color, double = next pattern, triple = brightness, hold = off) is learnable in a few minutes.

The reason it's not enough on its own: the smart-device side of the product needs *occasional* destructive operations — pairing, factory reset, recovery. Putting those on the same button as daily controls means either:

- Adding a fifth or sixth gesture (long-long-hold, quadruple-press) that no one will discover, OR
- Having daily gestures accidentally enter destructive modes

Neither is acceptable. So the single-button grammar stays for daily, and a second control surface owns the rare stuff.

### 4.3 Capacitive touch (TTP223 evaluation)

The BOM analysis (Apr 9) flagged a TTP223 capacitive touch sensor as a $0.10 add-on that senses through 1–2mm PETG. Initially attractive: invisible button, no mechanical wear, fits the brand language of "tech disappears."

**Deferred, not rejected.** Two concerns held it back:

1. **No tactile feedback.** The V0 button gives a satisfying click that doubles as an "input received" signal. Capacitive needs a separate confirmation channel (LED feedback) to feel responsive — extra firmware work, and on some patterns the LED feedback could be ambiguous.
2. **Holds are awkward on capacitive.** Holding your finger against a smooth panel for 600ms+ is fine; doing it for 10 seconds (factory reset) is uncomfortable. Hold-based gestures are ergonomically tied to mechanical buttons.

I want to revisit this in v2 once the interaction grammar has been validated by real users. For v1, mechanical wins because it's known.

### 4.4 Knob / encoder

Considered briefly — a rotary encoder for brightness with a press-to-toggle would feel premium and physical.

**Rejected on cost and assembly time.** A through-hole encoder adds $1–2 to BOM and a soldering operation; the click-only switch is a single SMT placement. For a $65 retail product, the math doesn't work.

### 4.5 Two buttons (chosen)

One **exposed** primary button for daily UI; one **recessed pinhole** button for rare/destructive operations.

The recessed button is the load-bearing decision in this design. It comes from a specific precedent.

---

## 5. The Eero precedent

The Eero router (and AirPort, and most modern network gear) uses a recessed pinhole reset button — accessible only with a paperclip. It's a convention strong enough to be universally recognized: "this is the dangerous button."

That convention does three things at once:

1. **It gates destructive actions behind a physical barrier.** You can't bump into a paperclip-only button. You can't sit on it.
2. **It signals consequence to the user before the press.** Nobody finds a pinhole and casually pokes it — finding the paperclip is itself a deliberate decision.
3. **It separates daily UI from configuration UI** so the daily UI can stay clean. The exposed button doesn't have to grow a fifth gesture for "factory reset"; that role is offloaded entirely.

I lean on this precedent intentionally. Users — even non-technical ones — already know what a pinhole button means, because they've reset their router or their phone's SIM tray or a pair of headphones. Inheriting that mental model means I don't have to teach it.

---

## 6. Why I preserved V0's gesture grammar

The primary button uses the same gesture mapping as the V0 prototype's single-button STM8 firmware:

- **Single press** — toggle on (when off) or advance base color (when on)
- **Double press** — change pattern
- **Triple press** — advance brightness
- **Hold** — turn off

Three reasons:

1. **It works.** V0 has been in the field on the prototype unit for months. The grammar is intuitive after a few minutes; once learned, it's muscle memory.
2. **Continuity across SKUs.** The Basic STM8 product (already in production) and the Pro/Pro+ ESP32 product share an interaction grammar. A user who upgrades from Basic to Pro doesn't have to relearn the device.
3. **Cost of redesign is unjustified.** I considered alternatives — adding a long-press for pattern, separating "next color" from "previous color" with double-press direction, etc. None of them were obviously better. Changing for the sake of changing isn't a design decision, it's churn.

The one place I pushed back on continuity: the parked clarification in [button-interface §6](button-interface.md#parked-clarification) about self-palette patterns swallowing single-press feedback. This is the kind of edge case user testing is meant to surface. Documented but not solved — Week 5 interviews are the test.

---

## 7. What I gave up

Honest accounting of the trade-offs this design accepts:

- **Spec-Head users get a sparse hardware UI.** Want to reorder patterns? Set a brightness ceiling? Bind a custom gesture? Use the app. Hardware is for daily essentials only.
- **No multi-button combos.** I'm not adding "press primary while holding recessed = enter dev mode." Combos are unguessable, undocumented, and create accidental triggers. Whatever a power user wants, the app handles it.
- **Discoverability is bounded by the grammar.** A user who never tries triple-press won't find brightness control on the device. The unboxing card has to teach the gestures explicitly. (See: packaging QR code concept — laser-etched into cardboard, gestures listed alongside.)
- **Five-year app survival is a real risk.** If I rely on the app for any non-trivial functionality and the app stops working, that functionality is gone. Mitigation: keep the device's standalone capability honest, don't put basic features behind app-only flows. (See: [right-to-repair §3](right-to-repair-philosophy.md#3-what-i-commit-to) — every device-level feature must be reachable without an app.)

---

## 8. What I want to learn from user research

This rationale is principle-driven. The Week 5 interviews ([user-interview-outline.md](user-interview-outline.md)) are the first chance to pressure-test the assumptions.

Specifically, I want to know:

| Hypothesis | Question that tests it |
|---|---|
| Curators don't open apps for wall art | "When was the last time you opened an app for a piece of decor?" |
| Single-press color advance is intuitive | Watch them try it. Don't pre-explain. |
| Hold-to-off is intuitive | Same — watch the first attempt. |
| Recessed button is recognized as "the reset" | Show photos of the back; ask what they'd assume the pinhole does. |
| Brightness needs more than 4 steps | Ask if 4 brightness levels feels like enough. |
| App-vs-button preference correlates with audience type | Compare answers across interview subjects. |

If the interviews refute any of the strong claims here, this doc gets revised. The point of writing it before user research is to make the hypothesis legible — so the research can falsify it cleanly, rather than just confirming what I already wanted to hear.

---

## 9. Open questions and parked items

Pulled forward from [button-interface.md](button-interface.md) and the firmware architecture work:

- **Recessed button discoverability.** A first-time user shouldn't *need* the recessed button — out-of-box the device runs without it. But they need to find it when something goes wrong. The unboxing flow and Repair Guide both have to surface it.
- **Self-palette pattern feedback.** Single-press on Rainbow advances base color in firmware state but produces no visual change. Possible refinement: ~200ms acknowledgement flash. Defer until user testing.
- **Capacitive touch revisit for v2.** Once the gesture grammar is validated and the visible-button interaction model is locked, capacitive becomes interesting again as a "tech disappears" upgrade.
- **Matter commissioning gesture.** If the Pro+ SKU ships, the recessed button needs a third gesture (tentative: 6s hold) for Matter commissioning. Doesn't affect Pro or Basic.

---

## 10. The one-sentence summary

> *Two buttons because the mirror is a light first and a smart device second — and the difference between those two roles deserves a physical seam.*

---

## Related

- [Button Interface Design](button-interface.md) — the spec this rationale explains
- [Firmware Architecture Scoping §4](firmware-architecture-scoping.md#4-design-principles-locked-apr-20) — the design principles this inherits
- [Brand Positioning §3](brand-positioning.md) — audience priority that drives the trade-offs
- [Right-to-Repair Philosophy §3](right-to-repair-philosophy.md#3-what-i-commit-to) — the standalone-capability commitment
- [User Interview Outlines](user-interview-outline.md) — Week 5 research that will pressure-test this
- [Pattern Dictionary](pattern-dictionary.md) — the visual contract the gestures advance through

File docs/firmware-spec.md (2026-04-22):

---
title: Firmware Spec — ESP32 Infinity Mirror
type: engineering
phase: 2
week: 4
date: 2026-04-22
status: draft — initial component spec after Apr 22 architecture lock
tags: [engineering, firmware, esp32, spec]
---

# Firmware Spec — ESP32 Infinity Mirror

**Prepared by:** William White
**Date:** April 22, 2026
**Status:** First draft — authoritative component-level spec for the two firmware variants

---

## 1. Purpose

Defines what the ESP32 firmware *is* at the component level: what modules exist, what they own, how they communicate, what ESP-IDF components they depend on.

Pairs with:
- [Firmware Architecture Scoping](firmware-architecture-scoping.md) — the decisions this spec implements
- [Firmware Security Model](firmware-security.md) — signing, OTA, auth details
- [Control Protocol Spec](control-protocol-spec.md) — wire protocol this firmware serves
- [Button Interface Design](button-interface.md) — UX this firmware implements

Out of scope: line-level implementation, test strategy, CI. Those follow the repo scaffold.

---

## 2. Top-Level Architecture

```
            ┌───────────────────────────────────────────────┐
            │                  variants/                    │
            │   ┌───────────────┐      ┌───────────────┐    │
            │   │  standard/    │      │   matter/     │    │
            │   │   main.c      │      │   main.c      │    │
            │   │               │      │   matter_     │    │
            │   │               │      │   bridge.c    │    │
            │   └───────┬───────┘      └───────┬───────┘    │
            └───────────┼──────────────────────┼────────────┘
                        │                      │
                        ▼                      ▼
            ┌───────────────────────────────────────────────┐
            │                    core/                      │
            │                                               │
            │    ┌─────────────────────────────────────┐    │
            │    │            state_bus                │    │
            │    │  (single source of truth, pub/sub)  │    │
            │    └────┬────────────────────────────┬───┘    │
            │         │                            │        │
            │    ┌────▼─────┐  ┌────────┐   ┌──────▼─────┐  │
            │    │ button   │  │  ota   │   │ transport  │  │
            │    │ handler  │  │ client │   │ (WS/HTTP/  │  │
            │    │          │  │        │   │   BLE)     │  │
            │    └────┬─────┘  └────────┘   └──────┬─────┘  │
            │         │                            │        │
            │         ▼                            │        │
            │    ┌─────────────────────┐           │        │
            │    │ pattern_interp      │◄──────────┘        │
            │    │ (runs current       │                    │
            │    │  pattern at frame   │                    │
            │    │  rate)              │                    │
            │    └────┬────────────────┘                    │
            │         ▼                                     │
            │    ┌──────────────┐     ┌──────────────┐      │
            │    │ led_driver   │     │ provisioning │      │
            │    │ (RMT→WS2812) │     │ (wifi_prov)  │      │
            │    └──────────────┘     └──────────────┘      │
            │                                               │
            │    ┌──────────────┐     ┌──────────────┐      │
            │    │ nvs          │     │ mdns + auth  │      │
            │    └──────────────┘     └──────────────┘      │
            └───────────────────────────────────────────────┘
                        │                      │
                        ▼                      ▼
            ┌───────────────────────────────────────────────┐
            │                   boards/                     │
            │  c6_devkit.h  c3_devkit.h  prod_v1_pro.h ...  │
            └───────────────────────────────────────────────┘
```

Variant-specific code (Matter bridge, standard main) is thin. All behavior lives in `core/`.

---

## 3. State Bus

The one thing every module touches. Single in-memory struct representing current device state:

```c
typedef struct {
    bool on;
    char pattern_id[32];
    uint32_t base_color_rgb;       // 0xRRGGBB
    uint8_t brightness;            // 0-100, actual values: 25/50/75/100
    uint16_t led_count;
    ll_auth_mode_t auth_mode;      // OPEN / PAIRED
    bool telemetry_enabled;
} ll_state_t;
```

### 3.1 Access rules

- **Single writer pattern via event-loop task.** Any module that wants to change state posts an event to the state-bus event loop (ESP-IDF `esp_event`).
- The state-bus task applies the change, then notifies subscribers.
- No module mutates `ll_state_t` directly.

### 3.2 Subscribers

Who listens for state changes:
- `pattern_interp` — re-selects pattern, picks up new base color / brightness
- `transport` — broadcasts the new state to all connected WebSocket clients
- `nvs` — persists changed fields (debounced — commits at most once per 500ms)
- `matter_bridge` (Pro+ only) — updates Matter attributes + triggers fabric subscription notifications

### 3.3 Event types

| Event | Emitted by | Payload |
|---|---|---|
| `LL_EV_POWER_TOGGLE` | button, transport, matter | `{ on: bool }` |
| `LL_EV_BASE_COLOR` | button, transport, matter | `{ rgb: uint32 }` |
| `LL_EV_PATTERN_CHANGE` | button, transport | `{ id: const char* }` |
| `LL_EV_BRIGHTNESS` | button, transport, matter | `{ value: uint8 }` |
| `LL_EV_AUTH_MODE` | transport | `{ mode: ll_auth_mode_t, secret?: const char* }` |
| `LL_EV_TELEMETRY` | transport | `{ enabled: bool }` |
| `LL_EV_PROVISION_START` | button (recessed 3s) | — |
| `LL_EV_FACTORY_RESET` | button (recessed 10s), transport | — |

---

## 4. Core Modules

### 4.1 `led_driver/`

- **Responsibility:** drive WS2812B LEDs via ESP32 RMT peripheral.
- **Inputs:** frame buffer (RGB8 array of length `led_count`), write call.
- **Outputs:** GPIO signal out `LL_PIN_LED_DATA`.
- **Dependencies:** `driver/rmt_tx` (ESP-IDF).
- **Frame rate:** target 60 fps. Actual cap = min(60, RMT bandwidth / led_count).
- **Brightness application:** uniform multiply applied here, not at pattern layer. Patterns produce 0–255 RGB; driver scales by `brightness/100` before RMT encode.

### 4.2 `pattern_interp/`

- **Responsibility:** execute the currently-selected pattern, produce a frame buffer per tick.
- **Tick rate:** 20 Hz logical pattern state (see [pattern-dictionary §2.4](pattern-dictionary.md#24-tick-rate)). LED redraw may run higher.
- **Pattern table:** 7 hardcoded C functions for V1, keyed by `pattern_id`. User-uploaded declarative patterns deferred to V2.
- **Base color integration:** patterns reference `base_color_rgb` from state bus. Single-press advances this value; self-palette patterns ignore it visually but state still updates.
- **Built-in patterns (V1):** see [pattern-dictionary §3](pattern-dictionary.md#3-patterns) — `solid`, `rainbow`, `scanner`, `spinner`, `random`, `breathing`, `twinkle`. Port 1:1 from [stm8_150mm.ino](../Firmware/STM8/stm8_150mm.ino).
- **Internal-only patterns (not user-selectable):** `indigo_pulse` (pairing mode cue), `red_flash` (factory-reset cue). See [button-interface §7](button-interface.md#7-led-feedback-conventions).
- **White-dimming rule:** apply WHITE_DIM_FACTOR = 217/255 when pattern=solid AND base color = white. See [pattern-dictionary §2.2](pattern-dictionary.md#22-white-only-dimming-rule).

### 4.3 `button/`

- **Responsibility:** debounce + gesture recognition for both buttons.
- **Inputs:** GPIO interrupts on `LL_PIN_BUTTON_PRIMARY` and `LL_PIN_BUTTON_RESET`.
- **Outputs:** state-bus events.
- **Gestures (primary):** single, double, triple, hold (600ms). Window for multi-press: 200ms after release. Debounce: 20ms. Values inherited from the canonical STM8 implementation ([stm8_150mm.ino:18-21](../Firmware/STM8/stm8_150mm.ino)) — proven on shipping units, don't change without user testing.
- **Gestures (recessed):** short-hold (3s) → `LL_EV_PROVISION_START`; long-hold (10s) → `LL_EV_FACTORY_RESET`. Release between thresholds fires the shorter action.
- **LED feedback during recessed hold:** pattern_interp shifts to a "threshold cue" pattern (color shift at 3s mark, red flash at 10s) — see [button-interface §7](button-interface.md#7-led-feedback-conventions).

### 4.4 `provisioning/`

- **Responsibility:** handle Wi-Fi provisioning via `wifi_prov_mgr`.
- **State machine:**
  - On boot: check NVS for creds. Present → connect Wi-Fi. Absent → do nothing, radios dark.
  - On `LL_EV_PROVISION_START`: start `wifi_prov_mgr` with BLE + SoftAP transports. Advertise for 5 minutes. On success: save creds, reboot into provisioned state. On timeout: stop advertising, return to previous state.
- **Dependencies:** `wifi_provisioning` (ESP-IDF component).

### 4.5 `transport/`

Subdivided into three transport submodules that share one dispatcher.

#### 4.5.1 `transport/ws/`
- WebSocket server on port 80, path `/ws`.
- Max 8 concurrent clients.
- Subscribes to state-bus events → broadcasts JSON state to all clients on change.
- Dependencies: `esp_http_server` (supports WS via extension).

#### 4.5.2 `transport/http/`
- REST handlers for `/api/*`. Same `esp_http_server` instance as WS.
- Maps HTTP requests to state-bus events or direct state reads.

#### 4.5.3 `transport/ble/`
- GATT service with a single `cmd` characteristic.
- Used during `wifi_prov_mgr` pairing and as fallback when Wi-Fi down.
- Not active during normal operation.

#### 4.5.4 Shared dispatcher
- Parses message envelope (JSON, see [control-protocol §3](control-protocol-spec.md#3-message-envelope))
- Verifies HMAC if device is in paired mode
- Validates `op`, dispatches to handler
- Handlers either read state, or post a state-bus event

### 4.6 `mdns/`

- Advertises `_layeredlogic._tcp.local.` on Wi-Fi connect.
- Hostname: `layered-logic-mirror-<device_id_short>.local`.
- TXT records include variant, version, auth mode (kept fresh by subscribing to state-bus).

### 4.7 `ota/`

Full behavior in [firmware-security §3](firmware-security.md#3-ota-security). Module responsibilities:
- Polls `ota.layeredlogic.cc/v1/check` on jittered schedule.
- Downloads signed binary to standby partition.
- Verifies signature + version counter before marking boot candidate.
- On boot of new version: validate critical services (Wi-Fi, LEDs, WebSocket) within 60s window, then `esp_ota_mark_app_valid_cancel_rollback()`.

### 4.8 `nvs/`

- Wrapper over `nvs_flash` for structured state persistence.
- Namespaces: `ll_state` (power, pattern, color, brightness, auth_mode, telemetry_enabled), `ll_auth` (shared_secret), `ll_patterns` (uploaded patterns, indexed by ID), `wifi_creds` (owned by `wifi_prov_mgr`).
- Debounced writes: state-bus triggers NVS commit at most once per 500ms.

### 4.9 `auth/`

- HMAC-SHA256 over message envelope (less the `hmac` field).
- Invoked by transport dispatcher when device is in paired mode.
- Dependency: `mbedtls/md.h`.

### 4.10 `telemetry/`

- Builds beacon payload from runtime metrics (heap low-watermark, boot reason, uptime, RSSI).
- POST to `telemetry.layeredlogic.cc/v1/beacon` on jittered 24h schedule — only if user opted in.
- On panic: captures `filename:line:task_name` to NVS, flushed on next successful beacon.

---

## 5. Variant-Specific Modules

### 5.1 `variants/standard/main.c`

- Minimal. Initializes core modules, sets up board via `board.h`, enters idle loop.
- Does not reference Matter at all.

### 5.2 `variants/matter/main.c` + `matter_bridge.c`

- Initializes core modules (same as standard).
- Additionally initializes `esp-matter` stack (Matter-over-Wi-Fi; Thread on C6 optional).
- Registers Matter On/Off + Level Control + Color Control clusters.
- `matter_bridge.c` translates Matter cluster callbacks → `ll_state_t` events on the state bus.
- Matter commissioning uses test VID `0xFFF1` + a Layered Logic test PID (see [firmware-security §6](firmware-security.md#6-secrets--keys-inventory)).
- Matter commissioning gesture: recessed button 6s hold (between `LL_EV_PROVISION_START` and `LL_EV_FACTORY_RESET` thresholds). Final timing confirmed when variant is built.

---

## 6. Board Headers

See [firmware-architecture-scoping §7](firmware-architecture-scoping.md#7-board-parameterization) for the full interface.

Each board header defines the hardware constants the core uses:
- Pin assignments
- Radio capability flags
- Flash layout selector
- Default LED count

Picked at compile time via `idf.py set-target esp32c6 -D LL_BOARD=c6_devkit` (approximate CMake passthrough).

---

## 7. ESP-IDF Components Required

### 7.1 Always required (both variants)

- `nvs_flash`
- `driver` (for RMT)
- `esp_wifi`
- `esp_event`
- `esp_timer`
- `esp_http_server`
- `wifi_provisioning`
- `mdns`
- `app_update` (OTA)
- `esp_https_ota`
- `bootloader_support`
- `mbedtls`
- `bt` (for BLE GATT + Unified Provisioning BLE transport)
- `nvs_sec_provider` (for encrypted NVS — optional, evaluated V2)

### 7.2 Additional on Pro+ (matter variant)

- `esp-matter` (external component)
- `connectedhomeip` (brought in by esp-matter)
- `openthread` (C6 only, for Thread)
- `ieee802154` (C6 only)

Matter component brings a large transitive closure; flash budget reserved for this is why Pro+ uses 8MB C6.

---

## 8. Boot Sequence

1. Bootloader verifies app signature (from §3.2 of firmware-security).
2. App starts. Initializes NVS, loads `ll_state_t` from `ll_state` namespace.
3. Initialize `state_bus` (event loop task pinned to core 0).
4. Initialize `led_driver`, `pattern_interp`. Render first frame (default color if hard-off, restored state if soft-off per [button-interface §4.1](button-interface.md#41-persistence)).
5. Initialize `button` module. Buttons live.
6. Check Wi-Fi credentials in NVS.
   - Present → connect Wi-Fi. On connect: start `mdns`, `transport/ws`, `transport/http`, `ota` (jittered check scheduled).
   - Absent → stay dark on radios. Device is fully usable offline.
7. (Matter variant only) Initialize `esp-matter` stack. Check for saved Matter fabric; if present, rejoin.
8. Enter idle loop. All work runs in tasks (button task, state-bus task, pattern tick timer, HTTP server task, OTA task).
9. ~30s after Wi-Fi connect + every 24h thereafter: OTA check.
10. ~60s after new-version boot: validation window runs `esp_ota_mark_app_valid_cancel_rollback()` if everything is healthy.

---

## 9. Flash + Memory Budget

| Resource | Pro (C3, 4MB) | Pro+ (C6, 8MB) |
|---|---|---|
| Application size (each slot) | ≤ 1.2MB | ≤ 3.0MB |
| NVS partition | 64KB | 128KB |
| Pattern storage (subset of NVS) | ~48KB (3 slots × 16KB) | ~96KB |
| Free heap target (min) | ≥ 80KB | ≥ 120KB |
| Matter fabric data | n/a | ~40KB |

Build budget is tracked in CI per commit. Going over triggers build fail.

---

## 10. Open Questions

| Question | Answer by |
|---|---|
| Final GPIO for recessed button on dev boards | First hardware bring-up |
| Final Matter commissioning gesture timing | When matter variant gets implemented |
| Whether encrypted NVS is worth the eFuse cost | V2 if a concrete threat emerges |
| Pattern grammar full spec | When pattern_interp implementation starts |

---

## Related

- [Firmware Architecture Scoping](firmware-architecture-scoping.md) — parent
- [Firmware Security Model](firmware-security.md) — security-facing internals
- [Control Protocol Spec](control-protocol-spec.md) — wire protocol this firmware serves
- [Button Interface Design](button-interface.md) — UX contract
- [App Spec](app-spec.md) — primary client
- [Webapp Spec](webapp-spec.md) — secondary client (device-hosted in V1)

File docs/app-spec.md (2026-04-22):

---
title: App Spec — Layered Logic Mobile App
type: engineering
phase: 2
week: 4
date: 2026-04-22
status: draft — initial spec drafted alongside firmware/webapp for gap detection
tags: [engineering, app, mobile, ios, android, ux]
---

# App Spec — Layered Logic Mobile App

**Prepared by:** William White
**Date:** April 22, 2026
**Status:** First draft — scopes what the LL mobile app is responsible for. UI wireframing is Week 5 (distinct task).

---

## 1. Purpose

The LL app is the **primary user interface** for the Layered Logic infinity mirror. It is where users:

- Pair a new mirror with their Wi-Fi
- Create and edit custom patterns
- Adjust color / brightness / on-off in real-time
- Manage multiple mirrors in one household
- Approve and monitor firmware updates
- Choose their security + privacy posture (open vs paired auth, telemetry opt-in)

It is **not**:
- Required for basic operation (see [firmware-architecture-scoping §4.1](firmware-architecture-scoping.md#4-design-principles-locked-apr-20) "standalone out-of-box")
- An account or social layer — no login, no cloud profile
- A remote-access tool in V1 — controls the mirror only when app + mirror are on the same network

Pairs with:
- [Firmware Spec](firmware-spec.md) — the device side
- [Control Protocol Spec](control-protocol-spec.md) — the wire protocol
- [Firmware Security Model](firmware-security.md) — auth modes the app surfaces to users
- [Webapp Spec](webapp-spec.md) — the alternate control surface

---

## 2. Principles

1. **Local-first.** No account. No cloud. App stores everything it needs on-device. Multiple phones with the LL app can each independently connect to the same mirror; state stays in sync via WebSocket broadcasts from the device.
2. **Fast to first light.** Unboxing → mirror lit with a user-selected color should take under 2 minutes. Provisioning screens prioritize speed over exhaustive options.
3. **The mirror is the authority.** App reads state from the device on connect. Never assumes local cache is correct after a round-trip gap. State broadcasts from the device overwrite app-local view.
4. **User-chosen security.** Expose the open-vs-paired decision clearly at provisioning; do not default to paired (see [firmware-security §5.1](firmware-security.md#51-two-modes-user-selected)).
5. **Transparency over clever.** Telemetry opt-in screen shows the exact fields collected, not a generic "help improve our product" toggle. Firmware updates show the changelog and the OTA check schedule. The user should always be able to know what their device is doing.

---

## 3. Platform + Stack

**Targets:** iOS 16+ (SE 3rd gen and newer), Android 12+.

**Stack decision: open question (to be resolved Week 5 wireframing block).**

| Option | Pros | Cons |
|---|---|---|
| **React Native + Expo** | Fast iteration, one codebase, good BLE libraries (`react-native-ble-plx`), Expo dev build handles native builds | BLE + ESPProvision SDK integration requires ejecting or custom modules |
| **Flutter** | Beautiful UI out of the box, strong BLE support (`flutter_blue_plus`), fast hot reload | Ecosystem smaller for ESP provisioning specifically |
| **Native (Swift + Kotlin)** | First-class ESPProvision SDK support (Espressif ships both), tightest BLE behavior | Two codebases to maintain solo |

**Leaning:** React Native + Expo for dev velocity, native if the ESPProvision SDK integration proves painful. Decision logged here; the architecture in this spec is stack-agnostic.

---

## 4. Architecture

```
┌───────────────────────────────────────────────┐
│                  UI Layer                     │
│  screens (pair, home, pattern editor, device  │
│  manager, settings, update, telemetry)        │
└──────────────────┬────────────────────────────┘
                   │
                   ▼
┌───────────────────────────────────────────────┐
│               State Layer                     │
│  - device list (local storage)                │
│  - active device connection state             │
│  - pattern library (local)                    │
└──────────┬────────────────────┬───────────────┘
           │                    │
           ▼                    ▼
┌────────────────────┐ ┌──────────────────────┐
│  Transport Layer   │ │  Local Storage       │
│  - BLE (provision) │ │  - known devices     │
│  - WebSocket       │ │  - user patterns     │
│  - HTTP REST       │ │  - prefs (telemetry, │
│  - mDNS discovery  │ │     theme, etc.)     │
└────────────────────┘ └──────────────────────┘
```

---

## 5. Key User Flows

### 5.1 First-run: pair a new mirror

1. User opens app. App shows "Add a mirror" CTA.
2. User taps it. App shows instruction: "Use a paperclip to press the recessed button on the back of your mirror for 3 seconds. The mirror will pulse indigo when it's ready."
3. User follows instruction; mirror enters pairing mode.
4. App starts BLE scan + SoftAP probe in parallel.
5. App finds mirror → shows "Found 'Layered Logic Mirror (abc123)'".
6. User taps to select. App shows Wi-Fi network list (scanned via ESPProvision).
7. User picks their Wi-Fi, enters password.
8. App sends creds via BLE to mirror. Mirror connects; app sees mirror on Wi-Fi via mDNS.
9. App prompts: **"How should your mirror be controlled?"**
   - **Open (default, recommended):** Anyone on your Wi-Fi can control this mirror
   - **Password-protected:** Only people with the password can control it
10. User picks mode. If paired: app prompts for password.
11. App shows telemetry opt-in screen — see §5.6.
12. Pairing complete. User drops to home screen with the mirror live.

### 5.2 Daily use: open app, control mirror

1. App opens. Shows list of known mirrors.
2. App attempts reconnect in priority order:
   - Cached IP → try WebSocket upgrade
   - If fail: mDNS query on local network
   - If fail: show "can't find mirror" with troubleshooting link
3. On connect: device broadcasts full state → app renders home screen.
4. User taps color → app sends `set_state { base_color: ... }` over WebSocket → mirror changes → device broadcasts back → all connected clients refresh.

### 5.3 Create a custom pattern

Full pattern editor UX is Week 5 wireframing; protocol surface is:

1. User builds pattern in editor (client-side only).
2. User taps "Save to mirror".
3. App sends `upload_pattern { definition }` over WebSocket.
4. Mirror stores to NVS, adds to pattern list, confirms.
5. User can now trigger the pattern via `set_state { pattern_id }`.

### 5.4 Firmware update

1. App polls device state periodically; `get_update_status` returns whether an update is available.
2. If available: banner appears in app with version + changelog.
3. User taps "Update now" → app sends `apply_update` → mirror reboots → app shows "Updating..." spinner with timeout.
4. Mirror comes back on new version → app reconnects → banner disappears.

App does not download firmware itself. App only triggers the device to pull its own update from `ota.layeredlogic.cc`.

### 5.5 Switch auth mode post-provisioning

1. User goes to device settings.
2. Taps "Who can control this mirror?"
3. Picks new mode. If switching to paired: enter password.
4. App sends `set_auth_mode { mode, secret }`.
5. Device confirms. All currently-connected clients must re-auth with the new secret (or disconnect if open→paired).

### 5.6 Telemetry opt-in

Separate screen (not buried in settings). Shows:

- **Bold question:** "Help us make Layered Logic more reliable?"
- **What we collect:** list of the exact fields (uptime, free heap, crash info with filename/line, Wi-Fi signal strength, firmware version, device ID, board type) — lifted straight from [firmware-security §4.2](firmware-security.md#42-what-telemetry-collects-when-opted-in).
- **What we don't collect:** list including pattern content, colors, schedule, Wi-Fi SSID, IP addresses.
- **How it's used:** "Opt-in devices get new firmware first. Opt-out devices wait for the build to be proven stable."
- **Toggle:** Enable / disable (default **disabled**).
- **Footer:** "You can view any telemetry payload before it's sent, in Settings → Advanced."

---

## 6. Screens (V1)

Roughly — final count + names settle in Week 5 wireframing.

| Screen | Purpose |
|---|---|
| Onboarding | First-launch welcome; handoff to pair flow |
| Pair device | BLE scan + Wi-Fi handoff flow |
| Home | List of known mirrors + connection status |
| Mirror detail (live) | Current pattern, color, brightness; picker for all three |
| Pattern library | List of built-in + custom patterns |
| Pattern editor | Create / edit custom patterns (Week 5 design) |
| Device settings | Rename, auth mode, telemetry, factory-reset warning |
| Update | Changelog + update-now button |
| Advanced | Peek pending telemetry, view connection diagnostics |
| About | Version, license notices, support link |

---

## 7. Local Data Model

Nothing in the cloud. Everything on-device.

| Entity | Fields | Storage |
|---|---|---|
| KnownDevice | `device_id`, `name`, `last_ip`, `auth_mode`, `secret_ref`, `variant` | Encrypted app storage (iOS Keychain, Android Keystore for secret) |
| Pattern | `id`, `name`, `definition`, `source` (built-in/user/from-device) | App storage (plain) |
| Prefs | theme, default brightness step, last-used pattern, telemetry reminder state | App storage (plain) |

---

## 8. Multi-Client Behavior

- Multiple phones running LL app can all be connected to the same mirror simultaneously.
- Each phone maintains its own WebSocket.
- State changes from any phone are broadcast back to all phones (and to the webapp if open).
- **No ownership model.** No "primary" phone. Anyone with network access (and optional shared secret) is equal.
- Follows from [firmware-security §5.1](firmware-security.md#51-two-modes-user-selected) user-agency framing.

---

## 9. Error States

| State | UX |
|---|---|
| Can't find mirror (all transports) | "Check that mirror is powered on and on your Wi-Fi. If issue persists, try holding the reset button for 3 seconds to re-pair." |
| WebSocket disconnected mid-session | Silent auto-reconnect with 1s→30s backoff. Badge shows "reconnecting..." |
| Paired mode, wrong secret | "Incorrect password." — no clue about what's correct. |
| Update failed / timed out | "Update didn't complete. Your mirror rolled back to the previous version. Try again later or check for network issues." |
| Mirror unreachable after auth mode change | Surface "Your phone is no longer authorized to control this mirror" + CTA to re-enter password. |

---

## 10. Accessibility

- Color picker must work for users with color-vision deficiency (not yet designed; flag for Week 5).
- Screen reader support at all screens.
- Minimum tap target 44×44 pt.
- Respect system font scaling.

---

## 11. Out Of Scope (V1)

- User accounts / cloud profile
- Remote access (control from outside the home)
- Home-automation integration in-app (HA integration runs on the HA server-side; Matter runs on Pro+ firmware independently)
- Widget / Siri / Google Assistant shortcuts (V2)
- Apple Watch / Wear OS app
- Group control (one action across multiple mirrors) — V2

---

## 12. Open Questions

| Question | Answer by |
|---|---|
| React Native vs Flutter vs native | Week 5 wireframing block |
| App-internal theming (dark mode, brand surface) | Week 5 — driven by brand cascade |
| How much of pattern editor fits on phone screen vs only in webapp | Week 5 wireframing |
| App onboarding for users who opened the app before buying a mirror | Week 5 — low priority |

---

## Related

- [Firmware Architecture Scoping](firmware-architecture-scoping.md) — design constraints this app obeys
- [Firmware Spec](firmware-spec.md) — device behavior this app consumes
- [Control Protocol Spec](control-protocol-spec.md) — wire protocol
- [Firmware Security Model](firmware-security.md) — auth + telemetry posture surfaced to users
- [Webapp Spec](webapp-spec.md) — alternate control surface (same protocol)
- [Button Interface Design](button-interface.md) — physical UX the app mirrors + co-exists with

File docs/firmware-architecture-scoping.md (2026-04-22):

---
title: Firmware Architecture Scoping
type: engineering
phase: 2
week: 4
date: 2026-04-22
status: locked — all 5 architecture decisions resolved in Wed Apr 22 block
tags: [engineering, firmware, esp32, architecture, scoping]
---

# Firmware Architecture Scoping — ESP32 Greenfield Build

**Prepared by:** William White
**Date:** April 20, 2026 (drafted), April 22, 2026 (locked)
**Status:** All 5 §5 decisions locked. Serves as the authoritative architecture reference; downstream specs ([firmware-spec.md](firmware-spec.md), [app-spec.md](app-spec.md), [webapp-spec.md](webapp-spec.md), [control-protocol-spec.md](control-protocol-spec.md), [firmware-security.md](firmware-security.md)) implement decisions from this doc.

---

## 1. Purpose

This document scopes the Week 4 firmware architecture decisions. As of Apr 22 it captures the locked decisions from the Wednesday focus block, with the original options + tradeoffs preserved in-line for traceability.

It is **not** a spec. The downstream specs ([firmware-spec.md](firmware-spec.md), [app-spec.md](app-spec.md), [webapp-spec.md](webapp-spec.md), [control-protocol-spec.md](control-protocol-spec.md), [firmware-security.md](firmware-security.md)) implement the decisions from §5.

---

## 2. Context

The V0 infinity mirror prototype runs an ESPHome YAML config on an ESP32-C3 (see [`Firmware/ESP32/prototype_ESPHome_Version.yaml`](../../Firmware/ESP32/prototype_ESPHome_Version.yaml), outside this worktree). ESPHome was a fast path to a working prototype as a hobbyist, but it isn't a product-grade foundation:

- It ties the product to Home Assistant defaults and the ESPHome toolchain.
- Consumers can't reasonably be asked to flash ESPHome, use HACS, or operate inside the HA ecosystem.
- The right-to-repair philosophy's commitment to a closed-binary proprietary firmware with self-hosted OTA + reflash service (see [philosophy §3](right-to-repair-philosophy.md#3-what-i-commit-to), [§4](right-to-repair-philosophy.md#4-the-honest-limits)) only makes sense if I own the firmware stack outright.

So: **greenfield rewrite**, not a port. The prototype board will be fully reflashed once the new firmware boots. The ESPHome YAML is kept as a **feature-parity checklist** — what the new firmware must at least match — and nothing more.

---

## 3. Components In Scope

The Phase 2 engineering deliverable is three distinct components, not one:

| Component | Role |
|---|---|
| **Firmware** | Runs on ESP32. Drives LEDs, handles button input, runs pattern interpreter, handles provisioning + OTA + app protocol. |
| **Mobile app** | Primary user interface. Pattern editor, color picker, schedules, device pairing. |
| **Webapp** | Secondary interface / control panel. Same control surface as the mobile app, browser-reachable on local network. Also hosts account management and firmware update distribution. |

All three ship together as a system. The mobile app is the main user-facing surface; the webapp is the "any-device" fallback and the surface for features that don't fit on a phone.

---

## 4. Design Principles (Locked Apr 20)

1. **Standalone out-of-box.** The product must work fully without any smart-home connection. Smart-home integration is opt-in polish, never a gate on basic function. A buyer who never opens the app and never touches their Wi-Fi should still get a working mirror with sensible defaults.
2. **App is the pattern editor.** The firmware ships with a handful of default patterns and runs a generic pattern interpreter. Users create and modify their own patterns through the app; the app pushes pattern definitions to the device. This matches the "Living" adjective from [brand positioning §3](brand-positioning.md#3-brand-personality--five-adjectives) — the product is dynamic, adaptive, user-shaped.
3. **Configurable LED count.** The shipping product is the 6×6 (32 LEDs). The 12×12 unit (66 LEDs) is a firmware test prototype — used for development and scale testing, not for sale. Firmware must accept the count as a config value, not a hardcoded constant.
4. **Brand-palette default state.** The prototype's default-on color `(0.6, 0.0, 1.0)` = `#9900FF` is close to brand but not exact. New default: **Indigo Signal `#3214FF`** at 80% brightness (palette shifted to indigo Apr 21; confirmed). Every power-on returns the unit to this state.
5. **Closed-binary firmware, self-hosted OTA, reflash-service backstop.** Per right-to-repair philosophy §3 and §4. The firmware source is not public; the hardware (schematic, BOM, versioned PCBs) is. An owner with a dead board sends it to me for reflash; an owner with a bricked firmware pulls an OTA update. I'll revisit source escrow if the business EOLs.

---

## 5. Locked Decisions (Apr 22)

All five decisions resolved in the Wed Apr 22 focus block. Each section below captures the locked decision, rationale, and links to downstream spec docs where the decision is implemented. Original options + tradeoffs retained for traceability.

### 5.1 Language + Framework

Options:

| Option | Pros | Cons |
|---|---|---|
| **ESP-IDF (C/C++)** | Native Espressif. Best OTA + BLE + Wi-Fi support. Matches the `type: esp-idf` already in the ESPHome config. Most documented path for ESP32-C3. | C/C++ ergonomics. Steeper learning if unfamiliar. |
| **Arduino / PlatformIO** | Fastest to first blink. Huge ecosystem. Good for prototyping. | Less runtime control. OTA and secure-boot stories are weaker. Abstraction layers can leak under load. |
| **esp-rs (Rust on Espressif)** | Memory safety, modern tooling, fun to work in. Async story is good. | Ecosystem younger than ESP-IDF. More hunting for working examples of LED + BLE + OTA together. Higher risk for a week-4 commitment. |
| **NuttX / Zephyr / other RTOS** | Real OS semantics. | Overkill for this scope, adds scheduling complexity that doesn't buy much on a single-product firmware. |

**My recommendation going in:** ESP-IDF C++. Proven, matches the prototype framework, strongest OTA + BLE + Wi-Fi coverage, best docs. Rust is interesting but the time cost of learning-while-building is real. Arduino is a trap at product scale — great for prototyping, bad for long-term ownership. Willing to be talked out of ESP-IDF if there's a strong reason to go Rust.

### 🔒 Decision: **ESP-IDF with C as the default language**

C, not C++. ESP-IDF examples and docs are ~95% C; C++ support exists but creates friction with `extern "C"` boundaries and mixed compilation units. Small C++ islands acceptable where RAII genuinely helps (e.g., pattern object lifecycle) but not as the default idiom.

**What this means day-to-day:** paste-and-go from ESP-IDF examples, idiomatic `CMakeLists.txt`, explicit resource lifecycle (`_create` + `_delete` pairs). No RAII penalty at this scope — one person, product-scale firmware.

### 5.2 Provisioning UX

How does the user get the device onto their Wi-Fi the first time?

| Option | How it works | Pros | Cons |
|---|---|---|---|
| **BLE-to-Wi-Fi handoff via app** | Device advertises over BLE. User opens app, app discovers + pairs, user enters Wi-Fi creds in app, app pushes to device over BLE, device connects. | Clean UX. App-first flow aligns with brand. BLE is always available on ESP32-C3. | Requires the mobile app exists and works. Web fallback is awkward (browser BLE is spotty). |
| **SoftAP captive portal** | Device boots as its own Wi-Fi access point. User connects phone to "LayeredLogic-XXXX" network, browser redirects to a config page, user enters their home Wi-Fi creds. | Works with no app. Browser-only. | Breaks the "stay connected to your Wi-Fi" model. Some phones warn about "no internet on this network." |
| **Direct Wi-Fi + hardcoded creds** | User never configures Wi-Fi; device connects to something pre-set (dev-only). | Trivial for testing. | Obviously not shippable. |
| **Zigbee / Thread broadcast** | If ESP32-C6: device advertises as a Matter/Thread device; any Matter controller adopts it. | Zero-config for Matter users. | Requires ESP32-C6, requires the buyer has a Matter hub, doesn't help non-smart-home buyers. See §5.3. |

**Leading candidate:** BLE-to-Wi-Fi handoff via app, with SoftAP captive portal as a fallback for browser-only users and for when the app isn't installed. Both are already common patterns in commercial smart devices.

### 🔒 Decision: **BLE primary + SoftAP fallback, both via `wifi_prov_mgr`, user-initiated only**

- **Transport:** Espressif's Unified Provisioning library (`wifi_prov_mgr`) handles both BLE and SoftAP transports via the same firmware state machine. Official Android + iOS SDK components (ESPProvision) talk to it out of the box — saves ~2 weeks of custom BLE provisioning work.
- **Default posture:** **radios dark at rest.** No passive advertising. Device boots into normal running state (default color, button works) regardless of whether it's been provisioned.
- **User-initiated pairing:** triggered by a **3-second hold on the recessed button** (see [button-interface.md §5](button-interface.md#5-recessed-button--rare-operations)). Device enters pairing mode, advertises via BLE + SoftAP simultaneously, times out after 5 minutes.
- **No auto-pairing on first boot.** Consistent with principle §4.1 — the mirror is a light first; smart-device pairing is explicit opt-in.
- **Provisioned state:** device silently joins stored Wi-Fi, listens for app connections via WebSocket. BLE remains off unless user re-triggers pairing (for adding a second phone, etc.) OR Wi-Fi drops (minimal BLE advertising comes up as a discovery fallback per [control-protocol-spec.md](control-protocol-spec.md)).

### 5.3 Smart-Home Integration Path

Not being solved Wednesday — but flagged now so the framework choice doesn't box us out.

| Path | Module | Integration cost | Reach |
|---|---|---|---|
| **ESP32-C6 + Matter/Thread** | Swap module | Low — Matter gets us HA, Google Home, Apple Home, Alexa "for free" via the standard protocols. | Broad. The Matter promise. |
| **ESP32-C3 + individual integrations** | Stay on current module | High — write a HA integration, a Google Home action, an Apple HomeKit accessory, an Alexa skill, each separately. | Same endpoints, far more work. |

**Posture:** Decision deferred to customer research per index/open-questions. Wednesday's firmware architecture should not hardcode assumptions that would break a future C3→C6 swap. Specifically: keep the LED-driving + pattern-interpreter + provisioning layers **module-agnostic** so moving from C3 to C6 is a pin-mapping + radio-config change, not a rewrite.
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

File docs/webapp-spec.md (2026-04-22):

---
title: Webapp Spec — Layered Logic Mirror Control Surface
type: engineering
phase: 2
week: 4
date: 2026-04-22
status: draft — initial spec alongside firmware/app for gap detection
tags: [engineering, webapp, cloudflare, device-hosted, control]
---

# Webapp Spec — Layered Logic Mirror Control Surface

**Prepared by:** William White
**Date:** April 22, 2026
**Status:** First draft — captures V1 device-hosted scope + V2 hosted deferral

---

## 1. Purpose

The webapp is the **"any device, no install" fallback** for controlling the mirror. Whatever the LL mobile app can do, a browser should be able to do too — for users who:

- Don't want to install an app
- Are using a desktop / laptop (where no native LL app exists)
- Are on a guest's phone and just want to turn the mirror off
- Prefer keyboards + mice for pattern editing (likely a real use case — pattern design on a phone screen is cramped)

V1 webapp is **device-hosted**: the ESP32 serves the webapp's static files itself, reachable at `http://layered-logic-mirror-<id>.local/`. V2 plan is a **hosted variant** at `layeredlogic.cc/controlmydevice` — deferred because of a specific browser security constraint (§5).

Pairs with:
- [Firmware Spec](firmware-spec.md) — the device side
- [Control Protocol Spec](control-protocol-spec.md) — wire protocol shared with the mobile app
- [App Spec](app-spec.md) — the primary client; webapp should match its capabilities

---

## 2. Principles

1. **Same protocol, same features.** The webapp uses the same WebSocket + HTTP + JSON envelope as the mobile app. Anything the app can do, the webapp can do, unless an underlying web platform limit blocks it (e.g., BLE in Safari).
2. **Zero install, zero account.** Open the URL, control the mirror. No login, no signup.
3. **Device-hosted in V1.** Webapp files served by the ESP32's HTTP server. Small HTML + CSS + a single JS bundle. No build-time server dependency — a browser on the same LAN reaches the device's IP directly.
4. **Keyboard-friendly.** Desktop is a first-class target for the webapp. Keyboard shortcuts for common actions (space = on/off, arrow keys = next pattern, number keys = brightness step).
5. **Future hosted variant stays open.** Code is written so that swapping `fetch(device_ip + '/api/...')` for `fetch('https://layeredlogic.cc/relay/...')` doesn't require rewriting the client.

---

## 3. V1 — Device-Hosted

### 3.1 Where it lives

Files bundled into the firmware image (compressed) and mounted into the ESP32 HTTP server's static file handler at the root path.

**URL:** `http://layered-logic-mirror-<id>.local/` (via mDNS) or `http://<mirror_lan_ip>/` (direct).

### 3.2 Bundle constraints

- Must fit in firmware flash budget: target **≤ 80KB gzipped**
- No dependencies that require a build pipeline hosted elsewhere
- Single-page app; routing via hash (`#/`, `#/patterns`, `#/settings`) to avoid server-side routing
- No web fonts fetched from a CDN (device is local-network, no guaranteed internet)
- No analytics, no telemetry inside the webapp (diagnostics come from firmware telemetry module)

### 3.3 Stack

**Recommendation:** vanilla TypeScript + Preact + Vite. Small bundle, familiar, easy to inline. Avoids React (too big) and Svelte (would love, but slightly more friction embedding into the firmware build).

Flagged as open: may re-evaluate once bundle size is actually measured.
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

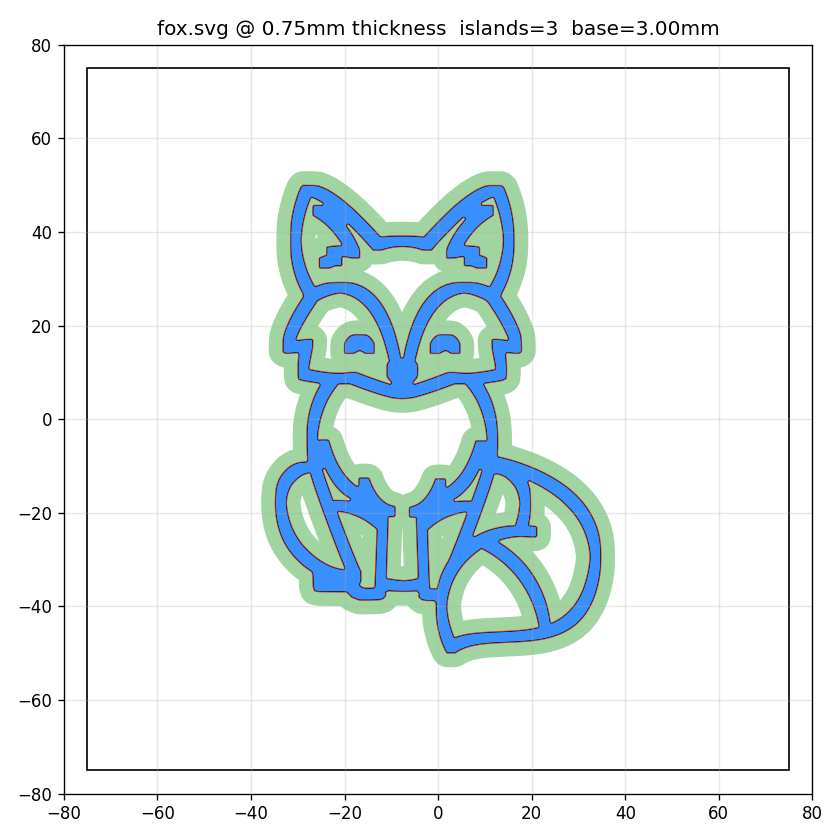
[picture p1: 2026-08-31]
portfolio/assets/fox.png

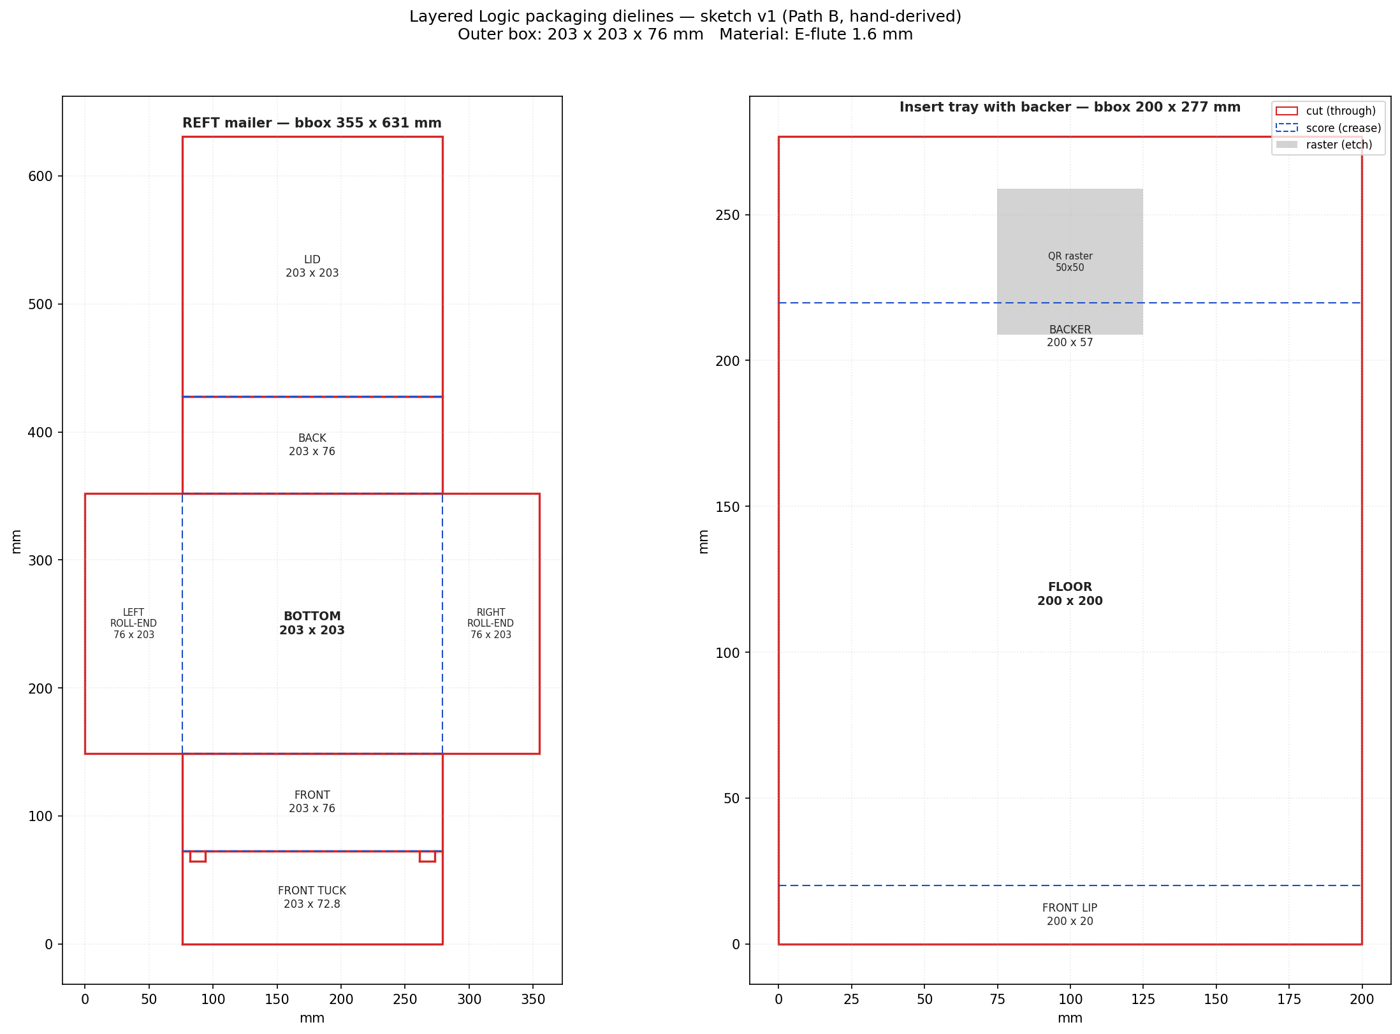
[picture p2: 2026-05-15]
portfolio/assets/dielines.png

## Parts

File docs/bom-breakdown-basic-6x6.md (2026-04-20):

---
title: BOM Breakdown — Basic 6×6 Infinity Mirror
type: business
phase: 1
week: 2
date: 2026-04-09
status: complete
tags: [bom, cost, pricing, finance]
---

# BOM Breakdown — Basic 6×6 Infinity Mirror
**Layered Logic — Spring 2026 | Week 2 Deliverable**
*Volume tiers: 1 / 50 / 100 / 1,000 units*

---

## Product Configuration

| Spec | Value |
|---|---|
| Model | Basic 6"×6" |
| Mirror panels | 150mm×150mm×3.1mm acrylic (1-way + 2-way reflective) |
| LED strip | WS2812B, 32 LEDs per unit (60 LEDs/m strip) |
| Controller | Basic LED controller |
| PSU | 5V brick (basic) |
| Frame | 3-sided, cut from 2×4 lumber |
| Printed parts | 44g PETG (LED spacer + electronics enclosure) |
| Packaging | Laser-cut folded cardboard, 8"×8"×3", <2 lbs |

---

## Fixed Capital Equipment

Capital required before first unit ships. Dominated by the laser cutter.

| Item | Cost | Notes |
|---|---|---|
| Laser cutter (300×600mm) | $4,795.83 | Primary cutting tool for acrylic + back panel |
| 3D printer (300³mm) | $1,500.00 | PETG parts |
| Mini PC (laser control) | $314.00 | |
| Laser table + stabilizer | $200.96 | |
| LightBurn (lifetime license) | $189.21 | Laser CAM software |
| Soldering iron | $60.36 | |
| Raspberry Pi | $50.00 | Flashing/testing |
| Fume extractor | $33.33 | |
| ST-Link v2 | $9.42 | |
| **Total** | **$7,153.11** | |

> **Note:** This equipment serves the full product line and general fabrication — not exclusively infinity mirrors. True per-product amortization would be lower if other products share the tooling.

---

## Material BOM — Per Unit at Each Volume

*Prices based on current sourcing (retail → wholesale → bulk direct as volume increases).*
*LED count: 32 confirmed measured (model computes 37 from perimeter; actual frame geometry uses 32).*

| Component | Qty | Unit | 1 unit | 50 units | 100 units | 1,000 units | Source notes |
|---|---|---|---|---|---|---|---|
| LED strip (WS2812B) | 32 | LED | $1.63 | $1.63 | $1.28 | $0.80 | 1–50: Amazon reel ($0.051/LED); 100: AliExpress ~$12/reel; 1k: bulk ~$7.50/reel |
| 1-way mirror acrylic | 1 | panel | $2.49 | $2.24 | $2.12 | $1.87 | Makerstock $9.95/12×12 sheet → bulk discount at volume; 4 panels/sheet |
| 2-way mirror acrylic | 1 | panel | $5.00 | $4.50 | $4.25 | $3.75 | TT Plastic Land $20/12×12 sheet (best current price); 4 panels/sheet |
| Back panel (birch ply) | 1 | panel | $1.25 | $1.13 | $1.06 | $0.94 | Makerstock $5/12×12 sheet; 4 panels/sheet |
| Frame sides (3× basic) | 1 | set | $2.00 | $1.75 | $1.50 | $1.25 | Cut from 2×4 lumber |
| LED controller (basic) | 1 | unit | $5.00 | $4.00 | $3.50 | $2.50 | |
| PSU (basic, 5V) | 1 | unit | $5.00 | $3.50 | $3.00 | $2.00 | AliExpress bulk at 50+ |
| PETG parts (44g total) | 1 | set | $1.50 | $1.50 | $1.25 | $1.00 | Material + print wear; $14.75/kg filament |
| LED holders | 1 | set | $0.50 | $0.50 | $0.50 | $0.40 | |
| Back reflector | 1 | piece | $0.50 | $0.50 | $0.40 | $0.30 | |
| Hardware (screws, wire) | 1 | set | $0.75 | $0.60 | $0.55 | $0.40 | |
| Packaging (cardboard) | 1 | unit | $2.00 | $1.25 | $1.00 | $0.60 | ⚠️ Estimate — actual cost TBD pending box design |
| **Materials subtotal** | | | **$27.62** | **$23.10** | **$20.41** | **$15.80** | |

---

## Full COGS Breakdown

*Labor model: assembly 10 min + laser cutting 30 min (3 panels × 10 min) + 3D printer setup 10 min = 50 min at 1 unit. Efficiency gains modeled at scale (batching). Rate: $60/hr.*

| Cost element | 1 unit | 50 units | 100 units | 1,000 units |
|---|---|---|---|---|
| Materials | $27.62 | $23.10 | $20.41 | $15.80 |
| Labor (active time) | $50.00 (50 min) | $40.00 (40 min) | $35.00 (35 min) | $30.00 (30 min) |
| Energy | $1.00 | $1.00 | $1.00 | $1.00 |
| Overhead | $3.00 | $3.00 | $3.00 | $3.00 |
| **Variable COGS** | **$81.62** | **$67.10** | **$59.41** | **$49.80** |
| Fixed cost amortized | $7,153.11 | $143.06 | $71.53 | $7.15 |
| **Total COGS (inc. fixed)** | **$7,234.73** | **$210.16** | **$130.94** | **$56.96** |

---

## Margin Analysis

Two ways to read this, both valid depending on context:

**View A — Labor as owner earnings** (recommended for sole-owner maker business)
True cash cost = materials + energy + overhead. Labor is what you earn.

| Retail price | 1 unit | 50 units | 100 units | 1,000 units |
|---|---|---|---|---|
| True cash cost | $31.62 | $27.10 | $24.41 | $19.80 |
| **$50 retail** | $18.38/unit → **$22/hr** | $22.90/unit → **$34/hr** | $25.59/unit → **$44/hr** | $30.20/unit → **$60/hr** |
| **$65 retail** | $33.38/unit → **$40/hr** | $37.90/unit → **$57/hr** | $40.59/unit → **$70/hr** | $45.20/unit → **$90/hr** |
| **$80 retail** | $48.38/unit → **$58/hr** | $52.90/unit → **$79/hr** | $55.59/unit → **$95/hr** | $60.20/unit → **$120/hr** |

**View B — Full COGS margin** (labor counted as a cost)

| Retail price | 1 unit | 50 units | 100 units | 1,000 units |
|---|---|---|---|---|
| $50 | -$31.62 | -$17.10 | -$9.41 | **+$0.20** |
| $65 | -$16.62 | -$2.10 | **+$5.59** | **+$15.20** |
| $80 | -$1.62 | **+$12.90** | **+$20.59** | **+$30.20** |

*(Fixed amortization excluded from View B — treated as sunk cost / shared infrastructure)*

---

## Key Findings

### 1. Labor is the dominant cost driver
At all volume tiers, labor exceeds material cost. Even at 1,000 units (30 min/unit × $60/hr = $30 labor vs. $15.80 materials), labor is nearly 2× materials. Any investment in reducing active assembly time — jigs, fixtures, better workflow — has an outsized impact on effective hourly rate.

### 2. The $50 retail price is tight
At $50, the effective hourly rate ranges from **$22/hr (1 unit)** to **$60/hr (1,000 units)**. The $50 price point only reaches your $60/hr target at very high volume. Consider:
- **$65 as the base price** — reaches $57–90/hr across realistic early volumes (50–100 units)
- **$50 as a promotional/Etsy entry price only** if driving initial reviews, understanding the margin compression

### 3. The 2-way mirror is the highest-cost material
At $5.00/panel at 1 unit, it's the single most expensive material line item. Supplier negotiation or bulk ordering has the most leverage here. At 1,000 units it drops to $3.75 — worth pursuing a direct quote from Canal Plastic or TT Plastic Land at ~100+ sheet volume.

### 4. Fixed equipment is not the pricing constraint
At 100 units the laser + equipment is only $71.53/unit amortized — significant but not prohibitive. At 1,000 units it's $7.15. These tools serve the full product line; pricing should not be held hostage to 100% equipment cost recovery from this SKU alone.

### 5. Material cost reduction path is clear
Materials drop from $27.62 → $15.80 (43%) from 1 to 1,000 units. The biggest levers in order:
1. PSU: $5.00 → $2.00 (-$3.00)
2. LED controller: $5.00 → $2.50 (-$2.50)
3. 2-way mirror: $5.00 → $3.75 (-$1.25)
4. LED strip: $1.63 → $0.80 (-$0.83)

---

## PCB Cost Analysis — JLCPCB (Basic STM8 Board)

*BOM: `Claude_PCB_Files/jlcpcb/production_files/BOM-Infinity_Mirror_basic.csv`*
*7 component lines | 9 total parts | 40 solder joints | 2 extended parts (STM8, USB-C)*

| Component | LCSC # | Qty | Unit price | Subtotal |
|---|---|---|---|---|
| 0.1uF 0603 cap | C14663 | 2 | $0.010 | $0.020 |
| 10k 0603 resistor | C25804 | 1 | $0.008 | $0.008 |
| 1uF 0603 cap | C15849 | 2 | $0.010 | $0.020 |
| 330R 0603 resistor | C23138 | 1 | $0.008 | $0.008 |
| 47uF 0805 cap | C16780 | 1 | $0.015 | $0.015 |
| STM8S003F3P TSSOP-20 | C52717 | 1 | $0.217 | $0.217 |
| USB-C receptacle 6P | C456012 | 1 | $0.020 | $0.020 |
| **Parts total/board** | | | | **$0.308** |

| Order qty | PCB fab | Setup + ext. | Joints | Parts (+10%) | **Per board** |
|---|---|---|---|---|---|
| 5 | $2.00 | $14.00 | $0.34 | $1.69 | **$3.61** |
| 10 | $4.00 | $14.00 | $0.68 | $3.39 | **$2.21** |
| 50 | $17.50 | $14.00 | $3.40 | $16.94 | **$1.04** |
| 100 | $35.00 | $14.00 | $6.80 | $33.88 | **$0.90** |

> **Implication:** The $5.00 basic controller placeholder in `pricing_config.yaml` is overstated by ~5×. At production volume (50–100 units), the assembled PCB is ~$1/board. The `pricing_config.yaml` has been updated to reflect $1.00 at volume with a note.

### TTP223 Touch Sensor Add-On (evaluated Apr 9)

Adding a TTP223 capacitive touch IC to the basic PCB adds approximately **$0.10/board** all-in:
- IC (C42422127, SOT-23-6): ~$0.08
- 1× sensitivity cap (0603): ~$0.01
- Assembly (8 extra joints): ~$0.014
- **No extended part fee** — TTP223 is a JLCPCB basic part

Touch pad is a copper pour on the PCB (no additional component). Senses through PETG enclosure at 1–2mm thickness without issue. Decision pending on whether basic model needs touch vs. physical button.

---

## Assumptions & Caveats

| Item | Assumption | Flag |
|---|---|---|
| Packaging | $2.00 estimate at 1 unit | ⚠️ TBD — get actual quote for laser-cut cardboard box |
| LED count | 32 (measured) | Model computes 37 from perimeter math — verify frame geometry |
| Labor | 50 min at 1 unit, 30 min at 1,000 | Based on: 3 panels × 10 min laser + 10 min assembly + 10 min 3D setup |
| Volume discounts | Estimated 10–25% for acrylic | No formal quotes obtained yet |
| Basic controller | ~$1.00 at 50–100 units (JLCPCB) | Updated from $5 placeholder; ESP32 PCB BOM pending |
| Platform fees | Not included | Etsy adds ~9.5% + $0.20 listing; Shopify ~2.9% + $0.30 |
| Shipping | Not included | ~$8–12 domestic; typically passed to customer |

---

*Last updated: 2026-04-09*
*Source data: `Business/pricing_config.yaml`, `Business/infinity mirror pricing - Spent(as of 2_22).csv`, `Business/infinity mirror pricing - cost estimates.csv`, direct hardware measurements, JLCPCB/LCSC pricing (Apr 2026).*

---

## Related

- [Index / MOC](../index.md)
- [Market Analysis Report](Market%20Analysis%20Report.md) — pricing tier rationale and saturation risk
- [Sustainability Audit](sustainability-audit.md) — material hotspots that drive variable cost
- [Stakeholder Map](stakeholder-map.md) — Self-Buyer archetype purchasing context
- [Pricing Calculator](../tools/pricing/) — Streamlit dashboard operationalizing this analysis
- [Sprint Plan](../sprint_plan.md)

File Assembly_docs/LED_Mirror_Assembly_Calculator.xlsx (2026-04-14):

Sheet: Time Standards
LED MIRROR — ASSEMBLY TIME STANDARDS
Blue cells are editable inputs. All times in minutes.
STEP # | OPERATION | STD TIME (min) | BEST CASE (min) | WORST CASE (min) | NOTES
 | LANE 1 — FRAME
F1 | Cut 2x4s to rough length | 3.0 | 2.0 | 5.0 | Per frame; batch cutting saves setup time
F2 | Mill profiles — standard segments | 5.0 | 4.0 | 8.0 | Router table; all identical segments
F3 | Mill electronics pocket segment | 7.0 | 5.0 | 10.0 | Dedicated fixture; one per frame
F4 | Miter & glue assembly | 8.0 | 6.0 | 14.0 | Jig essential — do not freehand
F5 | Clamp & cure wait | 0.5 | 0.5 | 0.5 | Active time only; glue cures passively
F6 | Sand & finish pass | 4.0 | 3.0 | 6.0 | Light pass before final assembly
F7 | Frame QC — square & joints | 2.0 | 1.0 | 3.0 | Check square, pocket dims, joint tightness
 | ↳ LANE 1 — FRAME SUBTOTAL
 | LANE 2 — MIRRORS
M1 | Batch cut 12x12 sheet → 4x 6x6 | 4.0 | 3.0 | 6.0 | Wet saw; amortized per sheet (÷4 for per unit)
M2 | Edge inspection & clean | 1.5 | 1.0 | 3.0 | Check for chips; wipe clean
M3 | Custom design cut (if applicable) | 6.0 | 4.0 | 12.0 | Laser or CNC; skip for blank units
M4 | Mirror QC — clarity & edges | 1.5 | 1.0 | 2.0 | Inspect both panels before assembly
 | ↳ LANE 2 — MIRRORS SUBTOTAL
 | LANE 3A — LED STRIP PREP
E1 | Incoming test (full strip pre-cut) | 2.0 | 1.5 | 3.0 | Bench PSU + test harness; reject bad strips
E2 | Cut strip to spec length | 1.5 | 1.0 | 2.0 | Score and snap on cut line
E3 | Solder connector — VIN pad | 3.0 | 2.0 | 5.0 | Hakko iron; fine tip; flux first
E4 | Solder connector — GND pad | 3.0 | 2.0 | 5.0 | Inspect joint under loupe
E5 | Solder connector — DATA pad | 3.0 | 2.0 | 5.0 | Most critical joint — verify continuity
E6 | Post-solder power-on test | 2.0 | 1.5 | 3.0 | All LEDs must fire before proceeding
E7 | Seat strip into 3D printed spacer | 2.0 | 1.5 | 3.0 | Press fit; check alignment
 | ↳ LANE 3A — LED STRIP PREP SUBTOTAL
 | LANE 3B — CONTROLLER PREP
C1 | Receive & inspect controller | 1.5 | 1.0 | 3.0 | Check for physical damage; ESD precautions
C2 | Flash firmware (per unit, batched) | 3.0 | 2.0 | 5.0 | Pi jig; batch 5-10 at once to amortize setup
C3 | Solder required pads/through-hole | 5.0 | 3.5 | 8.0 | Per controller BOM; inspect all joints
C4 | Controller function test | 2.0 | 1.5 | 3.0 | Power on, verify comms & output
C5 | Seat controller into 3D housing | 1.5 | 1.0 | 2.0 | Press fit; secure if needed
 | ↳ LANE 3B — CONTROLLER PREP SUBTOTAL
 | FINAL ASSEMBLY
A1 | Kit check — all sub-assemblies present | 1.5 | 1.0 | 2.0 | Traveler card sign-off before starting
A2 | Install controller housing into pocket | 3.0 | 2.0 | 4.0 | Secure; verify cable routing path
A3 | Lay mirror #1 into milled channels | 2.0 | 1.5 | 3.0 | Handle with suction cups; no fingerprints
A4 | Seat LED strip assembly | 2.0 | 1.5 | 3.0 | Align to mirror edge; route cable
A5 | Lay mirror #2 | 2.0 | 1.5 | 3.0 | Verify alignment and spacing
A6 | Install backing | 3.0 | 2.0 | 4.0 | Fasten; check no rattles
A7 | Cable management & connector routing | 3.0 | 2.0 | 5.0 | All cables secured; connector accessible
A8 | Final power-on QC | 3.0 | 2.0 | 5.0 | Full function test; LED uniformity check
A9 | Visual inspection | 2.0 | 1.5 | 3.0 | Mirror alignment; no scratches or marks
A10 | Box & pack | 3.0 | 2.0 | 5.0 | Protective packaging; label; ready to ship
 | ↳ FINAL ASSEMBLY SUBTOTAL
 | TOTAL — PER UNIT (STD / BEST / WORST)
 | TOTAL — PER UNIT (hours)

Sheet: Unit Calculator
LED MIRROR — UNIT TIME CALCULATOR & DASHBOARD
Adjust batch size and custom mirror flag. All times pull live from Time Standards sheet.
 | INPUTS
 | Batch Size (units per run) | 10 | Number of units built per production batch
 | Orders per Day | 1 | Target daily output
 | Include Custom Mirror Cut? | 1 | 1 = Yes (custom design), 0 = No (blank unit)
 | Operator Efficiency Factor | 85% | 1.0 = perfect; 0.85 = realistic for trained operator
 | Hourly Labor Rate ($/hr) | $25.00 | Fully-loaded operator cost
 | PER-UNIT TIME SUMMARY
 | LANE / OPERATION | STD (min) | BEST (min) | WORST (min) | STD (hrs) | LABOR COST ($)
 | Frame
 | Mirrors
 | LED Strip Prep
 | Controller Prep
 | Final Assembly
 | SUBTOTAL (raw)
 | ADJUSTED (÷ efficiency factor)
 | BATCH & THROUGHPUT METRICS
 | Total Batch Time — STD (hrs)
 | Total Batch Time — BEST (hrs)
 | Total Batch Time — WORST (hrs)
 | Units per 8-hr Day (STD)
 | Labor Cost per Unit (STD)
 | Labor Cost per Batch (STD)
 | Custom Mirror Upcharge (min)
 | BOTTLENECK IDENTIFIER
 | Frame
 | Mirrors
 | LED Strip
 | Controller
 | Final Assembly

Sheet: Batch Planner
LED MIRROR — WEEKLY BATCH PLANNER
Plan your weekly production sessions by operation. Inputs pull from Unit Calculator.
 | WEEKLY DEMAND INPUTS
 | Orders per Week | 7 | Standard week at 1/day
 | Working Days per Week | 5 | Available production days
 | Hours Available/Day | 6 | Net productive hours (not 8 — be realistic)
 | RECOMMENDED BATCH SCHEDULE
 | OPERATION | UNITS/BATCH | SESSIONS/WK | HRS/SESSION | TOTAL HRS/WK | NOTES
 | Frame Build |  |  |  |  | Cut & mill all frame segments in one pass per batch
 | Mirror Cutting |  |  |  |  | Cut full sheets; store 6x6 blanks; custom cut per order
 | LED Strip Prep |  |  |  |  | Solder station; batch for efficiency — do full week at once
 | Controller Prep |  |  |  |  | Flash in trays; solder same session
 | Final Assembly |  |  |  |  | Pull from sub-assembly bins; daily or every 2 days
 | TOTAL PRODUCTION HRS / WEEK
 | CAPACITY CHECK
 | Available Hrs/Week |  |  |  |  | Working days × hrs/day
 | Required Hrs/Week |  |  |  |  | From batch schedule above
 | Utilization Rate |  |  |  |  | Target 70–85% for sustainable pace
 | Headroom (hrs/week) |  |  |  |  | Positive = capacity available

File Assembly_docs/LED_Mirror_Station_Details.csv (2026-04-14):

Station ID | Station Name | Zone | Lane | Actions Performed | Tools Required | Fixtures & Jigs | Consumables | Input Materials | Output Materials / WIP State | QC Check | Notes
S01 | Lumber Receiving & Staging | Wood Zone | Frame | Inspect 2x4s for warps/knots/defects; mark reject pieces; cut to rough oversized length for batch | Tape measure; pencil; speed square | None | None | Raw 2x4 lumber (8ft or 10ft boards) | Rough-cut 2x4 segments (oversized by ~1in); rejected lumber set aside | Visual inspection for warps, splits, large knots in critical areas | Batch-cut a full week of frames at once; mark each piece with chalk for easy identification
S02 | Miter Saw — Precision Cut | Wood Zone | Frame | Cut all frame segments to final length using dead-stop fence jig; cut all miter angles; identify and mark electronics pocket segment | 12in sliding miter saw (Dewalt); push stick; hearing protection; safety glasses | Dead-stop fence jig (one stop per unique cut length); clamp blocks | Sandpaper (120 grit) for any tearout cleanup | Rough-cut 2x4 segments from S01 | Precision-cut mitered frame segments; segments sorted by type (standard vs pocket piece) | Verify miter angle with digital angle gauge; check cut length against spec | Never change fence stop mid-batch; run all of one cut length before moving stop; pocket segment should be clearly marked before leaving this station
S03 | Router Table — Profile & Channel Mill | Wood Zone | Frame | Mill mirror channel profiles into all frame segments; mill any decorative or functional edge profiles; run all standard pieces first then switch to pocket setup | Router table (Kreg or Bosch benchtop); router bit set (straight & profile bits); push blocks; featherboards; hearing protection; safety glasses; dust mask | Featherboard clamps; router table fence with stops; depth-setting gauge | None | Precision-cut mitered frame segments from S02 | Fully profiled frame segments with mirror channels milled; segments ready for pocket routing or glue-up | Check channel depth and width with calipers against mirror glass thickness spec; verify channel runs full length | Set and lock bit depth before batch; use featherboards to maintain consistent fence pressure; do NOT change bit height mid-batch
S04 | Handheld Router — Electronics Pocket | Wood Zone | Frame | Rout electronics bay pocket into designated frame segment; set pocket to correct depth for PCB housing; verify fit with housing before proceeding | Handheld router (Dewalt 1-3/4hp); straight router bit; router speed control; safety glasses; hearing protection | Router sled jig (controls X/Y travel and pocket dimensions); depth stop collar; sacrificial backer board | None | Profiled frame segments from S03 (pocket segment only) | Frame segment with electronics pocket routed to correct depth and position; pocket verified to accept controller housing | Test fit 3D printed controller housing into pocket — must seat flush; check pocket depth with depth gauge | This is the only non-repeatable step in the frame lane; jig eliminates variability; always do a test pass on scrap before running production pieces
S05 | Frame Glue-Up & Assembly | Wood Zone | Frame | Apply wood glue to all miter joints; assemble frame using square jig; clamp and set aside to cure; label each frame with batch ID | Paintbrush or glue spreader; rubber mallet; bar clamps (x4 minimum per frame); F-clamps | 90-degree corner square jig (L-shaped clamping fixture on bench); wax paper to protect bench surface | Wood glue (Titebond II or III); painter's tape (for squeeze-out cleanup) | All profiled and routed frame segments from S03 and S04 | Assembled glued frame (curing); frames labeled with batch ID and date | Check frame is square (diagonal measurement must match); verify all joints are tight with no gaps | Do not move clamped frames for minimum 45 minutes; glue cure time is passive — stack clamp sets so you can run multiple frames without blocking the station
S06 | Frame Sanding & Finish | Wood Zone | Frame | Sand all exterior faces; break sharp edges; remove glue squeeze-out; apply finish coat if required; final visual inspection of frame | Random orbital sander; sanding block; shop vac with auto-on | None | Sandpaper (120 grit, 180 grit, 220 grit); finish/stain/sealant (per product spec); tack cloth; latex gloves | Cured glued frame from S05 | Finished sanded frame — ready for final assembly; electronics pocket clean and unobstructed | Visual check: no tearout, no glue residue, pocket walls clean and smooth; verify frame is still square after clamps removed | Do not finish inside the mirror channel or the electronics pocket — finish can affect fit tolerances; mask these areas if using spray
S07 | Mirror Sheet Receiving & Storage | Mirror Zone | Mirrors | Receive mirror sheets; inspect for cracks or chips; label sheets with received date; store vertically in A-frame rack with foam separators | Suction cup handles (x2); permanent marker; tape measure | Padded A-frame vertical storage rack | Foam sheet separators; edge protector tape | Raw 12x12in mirror sheets | Received and inspected 12x12in sheets stored vertically in rack; damaged sheets marked and quarantined | Inspect all four edges and faces for chips, cracks, silver bleed; reject any with delamination | NEVER store flat in stacks — vertical storage with foam separators prevents edge chipping and breakage; keep away from sawdust and vibration
S08 | Wet Saw — Mirror Batch Cut | Mirror Zone | Mirrors | Cut each 12x12in sheet into 4x 6x6in blanks; clean cut edges; sort into blank inventory bin; log sheet count consumed | Benchtop tile/glass wet saw (7in diamond blade); safety glasses; waterproof gloves; suction cup handles | Wet saw fence set to 6in (lock before batch); push block | Diamond blade cutting fluid (in saw reservoir); shop towels for drying | Inspected 12x12in mirror sheets from S07 | 4x clean-cut 6x6in mirror blanks per sheet; blanks dried and placed in labeled inventory bin | Check each cut edge for chips or micro-cracks; reject any piece with visible edge damage | Always wet-cut mirror — dry cutting causes microfractures; cut all sheets in one batch session; do NOT change fence setting mid-batch
S09 | Custom Design Cut (Per-Order) | Mirror Zone | Mirrors | Pull blank 6x6in panels from inventory; cut custom pattern per order spec; clean and dry cut pieces; inspect edges | Laser cutter or CNC (per shop setup); suction cup handles; safety glasses; appropriate PPE for cutting method | Per-order design file (loaded from order system); fixture to hold mirror blank flat during cut | Coolant or cutting fluid per machine spec; shop towels | 6x6in blank mirror panels from S08 inventory; per-order design file | 2x custom-cut 6x6in mirror panels per unit; panels labeled with order ID | Verify cut pattern against order spec; inspect all cut edges; check for silver layer damage near cut lines | SKIP THIS STATION for standard/blank units; custom cuts are a per-order operation not a batch operation; pull blanks from inventory bin, never cut to order from raw sheet
S10 | LED Strip Receiving & Pre-Test | Electronics Bench | LED Strip Prep | Receive LED strip rolls; inspect for physical damage; power on full roll using bench PSU and test harness; flag and quarantine any dead segments; log roll lot number | Bench power supply (0-30V 5A); test harness with alligator clips; multimeter; magnifying loupe | None | None | Raw LED strip rolls (full length) | Tested and approved LED strip rolls in stock; rejected rolls quarantined and logged | Every LED must illuminate on full roll test; check for dead zones, flickering, or abnormal color; measure strip voltage and current draw | Do this at receiving — NOT at assembly; discovering a dead strip mid-build is a major disruption; log roll lot numbers for traceability
S11 | LED Strip Cut & Solder | Electronics Bench | LED Strip Prep | Cut strip to spec length at correct cut line; flux VIN/GND/DATA pads; solder connector plug to all three pads; inspect joints under loupe; post-solder power-on test | Hakko FX-888D soldering iron; fine tip; wire cutters/scissors; magnifying loupe or USB microscope; bench PSU for post-solder test; fume extractor; anti-static wrist strap | LED strip solder jig (holds strip flat, positions connector at correct angle) | 63/37 rosin-core solder (thin gauge); flux pen; solder wick; isopropyl alcohol (IPA) and cotton swabs for cleanup | Tested LED strip rolls from S10; connector plugs | Cut and soldered LED strip assembly with connector attached; tested and verified; placed in labeled ESD-safe staging bin | Post-solder: power on with bench PSU — ALL LEDs must fire; inspect each joint under loupe (no cold joints, no bridges, no lifted pads) | Always flux before soldering; clean joints with IPA after; never skip post-solder power test; use solder jig every time — freehand soldering on flex strips causes inconsistent results
S12 | LED Spacer Sub-Assembly | Electronics Bench | LED Strip Prep | Press LED strip assembly into 3D printed spacer; verify fit and alignment; route connector cable through spacer exit port; place completed sub-assembly in staging bin | Plastic spudger or press tool; anti-static mat | None | None | Soldered LED strip assembly from S11; 3D printed LED spacer | LED + spacer sub-assembly; connector cable routed and accessible; placed in staging bin labeled READY FOR FINAL ASSEMBLY | Verify strip is fully seated with no lifting; connector exits through correct port; no stress on solder joints from cable routing | 3D printed spacers must be pre-inventoried — print a full week batch; inspect each spacer for layer delamination or warping before use
S13 | Controller Receiving & Inspection | Electronics Bench | Controller Prep | Receive controllers from China shipment; inspect each for physical damage; check component count; sort into ESD-safe trays; log lot and quantity | Anti-static wrist strap; ESD-safe tweezers; magnifying loupe | ESD-safe tray (5-10 unit capacity) | None | Inbound controller PCBs (from China, ~5-day lead time) | Inspected controllers sorted into ESD-safe flash trays; damaged units quarantined and noted | Check for bent pins, damaged SMD components, missing components, PCB cracks or burn marks | Always handle with ESD precautions; never place controllers on bare bench surface; maintain a minimum 2-week buffer stock to cover lead time
S14 | Firmware Flash Station | Electronics Bench | Controller Prep | Load tray of controllers into flashing jig; run batch flash script on Raspberry Pi; verify each unit flashes successfully; mark flashed units; place in FLASHED tray | Raspberry Pi flashing rig (wall or shelf mounted); pogo pin batch fixture (5-10 seats); USB hub if needed | Pogo pin fixture aligned to controller programming pads; TO FLASH and FLASHED labeled trays | None | Inspected controllers from S13 (in ESD tray, TO FLASH) | Flashed controllers in FLASHED tray; firmware version logged against lot number | Pi script must confirm successful flash for each unit; any failed flash goes back to start of queue; never mix flashed and unflashed units | NEVER mix FLASHED and TO FLASH trays; label trays clearly; log firmware version per batch; always flash in groups not one at a time — setup overhead is significant
S15 | Controller Solder & Function Test | Electronics Bench | Controller Prep | Solder all required through-hole components and pad connections per controller BOM; inspect all joints; power-on function test; verify communication and LED data output | Hakko FX-888D soldering iron; chisel tip; multimeter; bench PSU; USB microscope or loupe; fume extractor; anti-static wrist strap | PCB vise or helping hands; anti-static mat | 63/37 rosin-core solder; flux pen; solder wick; IPA + swabs for cleanup | Flashed controllers from S14 | Fully soldered and tested controllers; function verified; placed in ESD staging bin | Inspect all joints under loupe; power-on test must confirm correct output on data line; check voltage rails with multimeter | Chisel tip for any larger pads/through-hole; fine tip for SMD work; clean all flux residue before housing install
S16 | Controller Housing Assembly | Electronics Bench | Controller Prep | Seat soldered controller PCB into 3D printed housing; secure if required; route any connector cables; place completed sub-assembly in staging bin | Plastic spudger; ESD-safe tweezers | None | None | Tested controller from S15; 3D printed controller housing | Controller + housing sub-assembly; cables routed; placed in staging bin labeled READY FOR FINAL ASSEMBLY | PCB must be fully seated; no rocking or play in housing; all connectors accessible and unobstructed | Inspect housing for warping or delamination before use; print a full week buffer; do not force PCB into housing — if resistance is high the print needs to be re-toleranced
S17 | Kitting Station | Assembly Bench | Final Assembly | Pull all sub-assemblies and hardware for one unit; check against kit checklist; place into labeled order tray; sign traveler card before proceeding to final assembly | None (organizational only) | Kitting shelf with labeled bins for each component type; order tray per unit | None | Finished frame (S06); 2x mirror panels (S08 or S09); LED+spacer sub-assembly (S12); controller+housing sub-assembly (S16); backing panel; fasteners/hardware per BOM; traveler card | Fully kitted order tray with traveler card; all components verified present before assembly begins | Check every line item on the kit checklist before releasing tray to assembly; any missing component sends the tray back — do not begin partial assembly | This station prevents mid-build stops; traveler card travels with the unit through final assembly and QC; never start final assembly without a complete kit
S18 | Final Assembly | Assembly Bench | Final Assembly | Install controller housing into electronics pocket; lay mirror #1 into milled channels; seat LED strip assembly against mirror; lay mirror #2; install backing; route and manage all cables; secure connector for external access | Screwdrivers; rubber mallet; suction cup handles (for mirror handling); pick tool; cable tie tool | Rubber bench mat (protects mirrors); assembly jig or positioning guides if developed | Fasteners per BOM; cable ties; foam gasket material if spec requires | Complete kitted order tray from S17 | Fully assembled LED mirror unit; all components installed; backing secured; connector accessible; ready for final QC | Visual check at each sub-step: controller seated correctly; mirrors seated fully in channels; no visible gaps; no loose cables internally | Handle mirrors with suction cups only — no bare hands on mirror faces; route cables before installing backing; ensure connector is fully accessible and strain-relieved
S19 | Final Quality Control | QC / Finish Zone | Final Assembly | Full power-on test; LED uniformity check across all zones; visual inspection of mirror alignment and clarity; structural check for rattles or loose components; verify connector engagement; sign off traveler card | Bench PSU or standard power connector; multimeter; flashlight or high-CRI inspection light | QC checklist (laminated per-step); inspection light stand | None | Assembled LED mirror unit from S18 | QC-passed unit with signed traveler card; or unit flagged for rework with defect noted on traveler card | Power-on: all LEDs fire, no dead zones, no flickering; mirror: no scratches, chips, fingerprints, misalignment; structure: no rattle, backing flush, joints tight; connector: engages and disengages cleanly | Zero tolerance for dead LEDs or cracked mirrors — these are automatic reworks; mark rework reason clearly on traveler card; do not box any unit without a signed-off traveler card
S20 | Pack & Ship | Pack & Ship Zone | Final Assembly | Wrap unit in protective material; place in box with appropriate void fill; seal box; print and apply shipping label; log shipment; place in outbound area | Tape gun; label printer (Dymo or Rollo); scissors | None | Shipping box (sized to unit); bubble wrap or foam inserts; void fill; packing tape; shipping labels | QC-passed unit with signed traveler card from S19 | Boxed and labeled unit in outbound staging area; shipment logged with tracking number | Verify shipping label matches order; check box integrity before sealing; confirm traveler card is complete and inside or filed | Keep this station completely separate from assembly and sanding areas — dust and loose hardware contaminate packed units; never box a unit without a completed traveler card

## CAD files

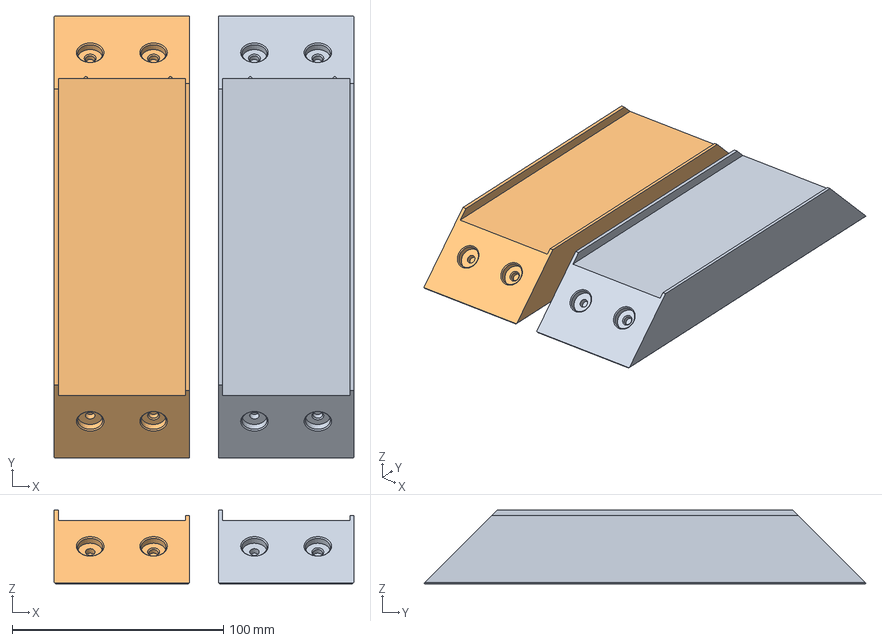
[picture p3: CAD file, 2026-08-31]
Assembly_docs/basic_housing/mirror Fits Fin.3mf
141.7 x 209.2 x 35.0 mm
mirror Fits Fin.stl x 2

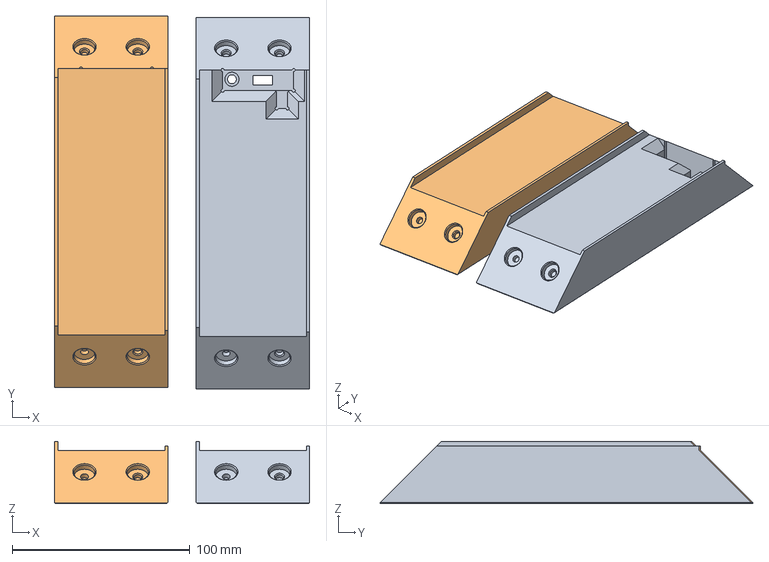
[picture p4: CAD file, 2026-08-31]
Assembly_docs/basic_housing/housing_electronics.3mf
143.8 x 210.0 x 35.0 mm
mirror_edge_magnets.stl x 2

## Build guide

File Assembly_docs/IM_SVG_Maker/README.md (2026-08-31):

# IM_SVG_Maker

Generate the fabrication files for a Kintsugi-style infinity mirror from a single black SVG (or a raster line-art image).

A black SVG of a logo or drawing goes in. Four files come out, ready to fabricate:

- `laser.svg` + `laser.dxf` — vector cut paths for a 150 × 150 mm acrylic mirror tile. Hairline-red strokes, mirror outline + interior cutout.
- `plug.3mf` + `plug.stl` — 3D-printable clear-PETG plug. Two layers: a 3 mm **inset** that drops into the laser-cut hole flush with the mirror's front face, and a 1 mm **base** behind the mirror that overlaps each mirror fragment to hold it in place (the "kintsugi glue").

For the design rationale, geometry math, and every decision made along the way, see [PLAN.md](PLAN.md).

## Quick start

Requires Python 3.11+.

```bash
pip install -e .            # editable install from pyproject.toml
python -m im_svg_maker demo_W_black.svg
```

Outputs land in `out/<svg_stem>/` alongside a `run.log` that records island count, chosen base offset, and the active config.

### From a raster image (JPG/PNG line art)

```bash
python scripts/raster_to_black_svg.py fox.jpg       # writes fox.svg
python -m im_svg_maker fox.svg                       # runs the main pipeline
```

The raster preprocessor binarizes, dilates the line work, and traces with potrace. All knobs are pulled from `variables.json` (`raster_thickness_mm`, `raster_threshold`, `raster_turdsize`, plus the size-floor pair below) and overridable with CLI flags. See [scripts/raster_to_black_svg.py](scripts/raster_to_black_svg.py) for options.

Two optional post-trace size floors (default 0 = disabled):

- `--min-island-area-mm2 N` — drop traced islands smaller than N mm². Catches dust/specks that survive the pixel-units `turdsize` filter, in resolution-independent mm units.
- `--min-feature-width-mm N` — drop islands whose narrowest cross-section is below N mm. Implemented as an erosion test (`island.buffer(-N/2)`); if the erosion empties the island, it gets dropped. Keep-or-drop semantics — does not reshape surviving islands or fracture them at thin necks.

### From a colored / multi-fill SVG

If your art is multi-color, pick which fill is the cut region before running the main pipeline:

```bash
python scripts/color_svg_to_black.py Washington_Huskies_logo.svg
# -> lists distinct fills with element count + summed bbox area

python scripts/color_svg_to_black.py Washington_Huskies_logo.svg --color "#E8D3A2" -o gold.svg
python -m im_svg_maker gold.svg                                          # main pipeline
```

Colors accept hex (`#RGB`, `#RRGGBB`), named CSS colors (`gold`, `red`), or `rgb(r,g,b)`. `--color` is repeatable for a union of multiple fills. `--tolerance N` widens the match by N units of L-infinity distance over r/g/b (0-255 units; default 0 = exact). `--invert` keeps everything that *doesn't* match — useful when the simplest description is "drop the background." Output is a flat black SVG with one `<path fill="#000000" fill-rule="evenodd"/>` per kept element, ready for `python -m im_svg_maker`.

## Configuration

Everything is in [variables.json](variables.json). The most useful knobs:

| Variable | Default | Purpose |
| --- | --- | --- |
| `mirror_size_mm` | `[150, 150]` | Acrylic sheet dimensions. Logo is centered on this. |
| `max_logo_dim_mm` | `100` | Longest side of the logo, in mm. Both axes scale proportionally. |
| `nozzle_diameter_mm` | `0.6` | 3D printer nozzle. All cut polygon corners are pre-rounded to `nozzle/2` so nothing is sharper than the printer can produce. |
| `laser_kerf_mm` | `0.1` | Uniform outward offset of the laser cut. Compensates for material the laser vaporises. |
| `inset_clearance_mm` | `0.15` | Plug inset is shrunk by this for slide-in fit. |
| `inset_height_mm` / `base_height_mm` | `3.0` / `1.0` | Layer thicknesses. Inset = acrylic thickness, base = arbitrary support. |
| `base_offset_min_mm` | `2.0` | Minimum overlap between the base and each mirror fragment. |
| `base_offset_per_island_mm` | `0.5` | Extra offset per island beyond the first (small bonus; the bridge term does the heavy lifting). |
| `base_bridge_factor` | `1.0` | 0–1 scale on the auto-computed bridge requirement (`gap/2`). |
| `raster_thickness_mm` | `0.75` | Preprocessor only: dilate raster lines by this before tracing. |
| `raster_min_island_area_mm2` | `0` | Preprocessor only: drop traced islands below this area floor (0 = off). |
| `raster_min_feature_width_mm` | `0` | Preprocessor only: drop islands whose narrowest cross-section is below this (0 = off). |

Base offset formula: `max(base_offset_min_mm + (N-1)*base_offset_per_island_mm, base_bridge_factor * nearest_island_gap_mm / 2)`. Logged at run time.

## Project layout

```
IM_SVG_Maker/
  im_svg_maker/             # main package
    cli.py                  # entrypoint (python -m im_svg_maker)
    config.py               # pydantic loader for variables.json
    svg_parse.py            # SVG -> normalized shapely MultiPolygon
    geometry.py             # nozzle rounding, kerf/inset/base offsets, island formula
    extrude.py              # shapely -> trimesh, 3MF/STL export
    laser_export.py         # SVG + DXF writers (red hairline laser convention)
    raster.py               # raster -> black SVG via potracer + shell/hole assembly + size floors
    color_select.py         # colored SVG -> black SVG by fill-color selection
  scripts/
    raster_to_black_svg.py  # CLI wrapper around im_svg_maker.raster
    color_svg_to_black.py   # CLI wrapper around im_svg_maker.color_select
    preview_cutlines.py     # filled-band 2D preview (cut/laser/inset/base layers)
    preview_zoom.py         # zoomed kerf-band view for visual debugging
    diag.py                 # polygon topology / area / winding diagnostic
  Washington_Huskies_logo.svg  # original colored reference (not consumed)
  demo_W_black.svg          # the W example used throughout planning
  fox.jpg                   # raster line-art example
  variables.json            # all tunable knobs
  pyproject.toml
  out/                      # generated per-input subdirs
  PLAN.md                   # full design doc & decision log
```

## Verifying a run

Open `out/<svg_stem>/`:

- `laser.svg` — view in a browser or Inkscape. Should show the 150 × 150 mm outer rectangle and the interior cut, both as red hairlines.
- `plug.3mf` / `plug.stl` — open in a slicer (PrusaSlicer, Bambu, Cura). Confirm: total height = `base_height_mm + inset_height_mm`, base layer wider than inset, mesh reports as manifold/watertight.
- `run.log` — quick-read summary of params, island count, computed base offset.

For visual debugging of the 2D geometry, the `scripts/preview_*.py` tools render filled-band overlays on the mirror sheet — handy for sanity-checking new SVGs before printing.

## Notes for next hands

- **Color-SVG → black-SVG** is now handled by `scripts/color_svg_to_black.py` (a list-fills + pick-one(or-more) flow). It's intentionally minimal: solid fills only, no gradient/pattern handling, overlap-handling is whatever the main pipeline's evenodd XOR does to nested subpaths. The fox preprocessor still handles raster line-art.
- **Tracing topology**: potracer returns evenodd subpaths. `raster.py` rebuilds proper shell+hole nesting by sorting polygons by area and counting containment depth — required so the main pipeline's XOR-based SVG parser reads holes correctly.
- **Round joins everywhere**: every `shapely.buffer()` in this codebase uses `join_style="round"`. Mitre joins extend wildly at sharp inner corners and aren't physically meaningful for either laser kerf or printable curvature. Don't switch.
- **STRtree gotcha**: shapely's STRtree.nearest can return `numpy.int64` and may include self in results. `_nearest_island_gap` does a straight O(N²) pairwise instead. Fine for typical island counts (<50).
- See **Learnings** section of [PLAN.md](PLAN.md) for the full list of things we figured out while building this.

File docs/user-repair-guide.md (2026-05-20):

---
title: User Repair Guide
type: hcde-artifact
phase: 3
week: 8
date: 2026-05-20
status: draft — repair times pending golden-sample measurement
tags: [repair, hcde, user-guide, troubleshooting, portfolio]
---

# User Repair Guide — Infinity Mirror v1.0

**From Layered Logic**

---

I design products to be opened, repaired, and kept. This guide is the practical side of that promise: if something on your mirror stops working, this is how you fix it.

Most problems here are small, and most have a fix you can do yourself in under half an hour with a screwdriver. A few need a soldering iron. A couple need me — and where that's true, I say so plainly and tell you what to do instead. Nothing on this mirror is a dead end.

If you ever get stuck, or you'd rather not do a repair yourself, email me. The address that sold you the mirror is the same one that helps you fix it.

---

## 1. Before You Start

**Always unplug the mirror from the wall before opening it.** Then give yourself a clean, soft surface to work on so you don't scratch the mirror face.

### Tools

| Tool | Needed for |
|---|---|
| Phillips-head screwdriver | Opening the mirror — every repair starts here |
| A paperclip or SIM-eject pin | The recessed button (pairing / factory reset) |
| Suction-cup handle | Lifting mirror panels without touching the faces |
| Soldering iron + solder | A few repairs only — strip, button, and barrel-jack work |
| Multimeter | Optional — helps diagnose power problems |

If a repair needs a tool you don't have, that's a fine moment to email me instead. You won't be turned away.

### How this guide is organized

- **Section 3** is a symptom finder — start there if you're not sure what's wrong.
- **Section 4** has the step-by-step repair for each part.
- **Section 5** explains the recessed button, which recovers most software problems with no tools at all.
- **Section 6** lists every replacement part and where to buy it.

---

## 2. Opening Your Mirror

Every internal repair starts by removing the back panel. The full step-by-step is in the [Assembly & Teardown Guide §7](assembly-guide.md#7-teardown--access-procedure). In short:

1. Unplug the mirror. Lay it face-down on a towel.
2. Remove the Phillips screws around the back panel. Keep them — they go back in.
3. Lift off the back panel and the back reflector.
4. The components are now reachable: front and back mirror panels, the LED strip on its spacer, and the controller in its small printed housing.

The mirror opens with a screwdriver and nothing else — no glue, no special bits. The wood frame itself is one solid glued piece and never needs to come apart; everything you service is reached through the back.

**Two panels, and which is which:** the **front panel** is the one you look at — it's the see-through half-mirror that lets the light out while still reflecting. The **back panel** behind the LEDs is the full mirror. Light bounces between them, and that's the infinity tunnel. When a panel needs replacing, identifying it by position (front vs. back) is the reliable way.

---

## 3. Troubleshooting by Symptom

Find your symptom, then go to the linked repair section.

### The mirror is completely dark — no lights at all

1. **Check the power first.** Is the power supply plugged into both the wall and the mirror? Unplug and firmly replug the barrel connector at the mirror. The power brick is normally slightly warm in use — if it's stone cold, suspect the power supply → **§4.2**.
2. **Wiggle test.** If the mirror flickers or briefly lights when you move the power cable, the barrel-jack connector is loose → **§4.2**.
3. **Power is good but still dark?** The issue is the LED strip connection or the controller → **§4.1**, then **§4.3**.

### One LED is dark, stuck, or flickering — or everything past a point is dark

The LED strip is a daisy chain, so one failed LED can black out everything after it → **§4.1**.

### The lights flicker, dim on their own, or the mirror reboots itself

Usually power. Reseat the barrel connector, try another wall outlet, remove any extension cords. If it persists → **§4.2**. If it only flickers when you touch the cable → **§4.2** (barrel jack).

### The mirror lights up but behaves strangely — random flashing, frozen color, reboot loop

A software problem. Try a **factory reset** (Section 5) — it fixes most of these with no tools → **§4.3**.

### The app can't find the mirror / it shows offline

The mirror still works from the button — only the network link is down. Almost always a changed Wi-Fi password or router → **§4.3** (Wi-Fi).

### The mirror forgot my settings after a power cut

Harmless. Just set your color, pattern, and brightness again — they'll save → **§4.3** (NVS).

### A button stopped working

Try a power cycle first. If the button is still dead → **§4.8**.

### A mirror panel is cracked, scratched, or hazy

→ **§4.4**.

### The wood frame is chipped, cracked, or warped

→ **§4.5**.

### Something inside is cracked — a printed part, the LED holder

→ **§4.6**.

---

## 4. Repair Procedures

Repair-time estimates below are working figures and will be refined once the first production "golden sample" units are measured.

### 4.1 LED Strip — Dead Pixel, Total Failure, or Fading

All three LED problems share one fix: the strip is a single continuous part, so you replace the whole strip rather than one light.

- **Dead or stuck pixel(s):** one LED is dark, wrong-colored, or flickering. Because the strip is a chain, a failed LED also blacks out everything downstream of it.
- **Total failure:** the whole strip is dark even though the controller has power. *Check this first* — it's usually just a loose connection, not a dead strip. Reseat the strip's connector at the controller before replacing anything.
- **Color degradation:** after many years the strip dims or shifts color as the LEDs age. Normal — and a long way off (the LEDs are rated past a decade of daily use).

**Replacement steps:**

1. Unplug the mirror and open the back (§2).
2. Disconnect the LED strip from the controller — a 3-pin connector, or three solder joints on some builds.
3. Lift the strip out of its printed spacer channel.
4. Seat the new strip in the channel, matching the data-direction arrow.
5. Reconnect to the controller (5V, GND, Data) and reassemble.

**Difficulty:** Easy if the strip is connectorized; moderate if it's soldered. **Time:** 15–25 minutes.
**Part:** WS2812B strip, 60 LEDs/m — see §6.

If a brand-new strip *also* shows dead pixels, the problem is likely the controller's data pin, not the strip → §4.3.

### 4.2 Power — Power Supply and Barrel Jack

**Power supply, no output (mirror totally dark):** the simplest repair on the whole product. The power brick is external — just unplug the dead one and plug in a replacement. No tools, no opening the mirror. Match a 5V supply with a 5.5×2.1mm barrel plug, rated 2A or more.

**Power supply, unstable (flicker, dimming, spontaneous reboots):** first reseat the barrel connector, try a different outlet, and remove any extension cords. If it still misbehaves, swap the power brick as above.

**Barrel jack, intermittent (flicker only when the cable is moved):** the give-away is that the trouble follows cable movement.
1. First, rule out the power supply — try a different 5V brick with a matching plug. If the trouble goes away, replace the power supply.
2. If the supply is fine, the socket on the mirror is worn. Open the back, inspect the socket's solder joints, and reflow or replace the socket (a standard 5.5×2.1mm barrel-jack socket). This step needs a soldering iron.

**Difficulty:** Trivial (power-brick swap) to moderate (socket replacement). **Time:** under a minute to ~20 minutes.

### 4.3 Controller — Hardware, Firmware, Wi-Fi, and Settings

The controller is a small board in a printed housing. It has four distinct problems, and three of the four you can handle yourself.

**Firmware acting up (random flashing, frozen color, reboot loop) — try this first, no tools:**
Do a **factory reset** (Section 5): hold the recessed button for 10 seconds. This clears the controller's stored data and returns it to factory defaults. It resolves the large majority of "the mirror is behaving strangely" problems. If the mirror works normally afterward, re-pair it through the app.

**Lost settings after a power cut (mirror came back on the default indigo color):**
Nothing is broken. Set your color, pattern, and brightness again with the primary button — single press for color, double for pattern, triple for brightness. They save automatically. If Wi-Fi was also forgotten, re-pair (Section 5). If settings vanish *repeatedly*, tell me — it's worth investigating and may be fixable with a software update.

**Wi-Fi dropped / app says offline:**
The mirror still works from the button — only the network link is down. The usual cause is a changed Wi-Fi password or a new router.
1. Hold the recessed button 3 seconds to enter pairing mode (slow indigo pulse).
2. Open the Layered Logic app and follow the setup flow to enter your Wi-Fi details.
3. If the network hasn't changed: restart the mirror and the router, and confirm your router still has a **2.4GHz** network — the mirror can't use 5GHz-only Wi-Fi.

**Hardware failure (power confirmed, but the board is unresponsive):**
This is the one controller problem that needs me. The controller runs a closed firmware, so a replacement board has to be flashed before it works. **Contact me** — I'll send a pre-flashed replacement board (cost of the board plus shipping), or you can send your board in and I'll reflash it for the cost of shipping. The physical swap itself is straightforward: disconnect the LED strip and power wiring, lift the old board out of its housing, seat the new one, reconnect. The board's revision letter is printed on it, and the matching schematic is public on GitHub.

**Difficulty:** Easy (factory reset, re-provision) to moderate (board swap). **Time:** under a minute to ~30 minutes.

### 4.4 Mirror Panels — Cracks, Scratches, and Haze

The acrylic panels sit in milled channels in the frame — not glued. They slide out and back in.

- **Crack or deep scratch:** from an impact or drop. Replace the affected panel.
- **Coating degradation (haze, cloudiness, dark spots):** from years of UV or from cleaning with the wrong product. Same fix — panel replacement. *Prevention:* keep the mirror out of direct sun, and clean the face only with a soft microfiber cloth and water. Never use glass cleaner, ammonia, alcohol, or paper towels — they strip the coating.

**Replacement steps:**

1. Unplug and open the back (§2).
2. Lift out the back reflector and the LED-strip-and-spacer assembly to reach the panels.
3. Slide the damaged panel out of its frame channel.
4. Slide the replacement in. The reflective side faces *inward*, toward the LED cavity.
5. Reassemble: LED assembly, back reflector, back panel.

Replacement panels need to be cut to 150×150mm. If you have a laser cutter I can send the cut file; otherwise email me and I'll send a pre-cut panel.

**Difficulty:** Moderate — handle the panels carefully. **Time:** 20–30 minutes.

### 4.5 Wood Frame — Physical Damage

**Cosmetic damage (nicks, dings, surface scratches):** sand the spot lightly with 220-grit, re-apply matching stain or finish, done. No disassembly.

**Structural damage (a crack, a warp, a loosened panel channel):** this is the most involved repair in the guide, because the panel channel has to be re-cut. Fully disassemble the mirror, replace the damaged frame piece with matching 2×4 lumber, and route the panel channel to match. If you don't have woodworking tools, email me — I can send a pre-cut replacement frame set.

**Difficulty:** Easy (cosmetic) to advanced (structural). **Time:** 10 minutes to a couple of hours.

### 4.6 Printed Parts — Breakage

The mirror has two printed PETG parts: the **LED spacer** that holds the strip, and the **controller housing**. If one cracks:

1. Unplug and open the back (§2).
2. Lift out the broken part (the spacer lifts from the frame; the housing is friction-fit).
3. Drop in the replacement and reassemble.

**Getting the part:** if you have a 3D printer, email me your order number and which part broke, and I'll send the STL file — any standard PETG filament prints it, about 44g for the full set. No 3D printer? I'll send a pre-printed part, or a local library/makerspace print service can do it. **Difficulty:** Easy. **Time:** 5–10 minutes to swap.

### 4.7 Wiring — Solder Joint Failure

The tell-tale sign of a bad solder joint is **intermittent behavior**: the mirror works, then cuts out when it's touched, moved, or bumped; or pressing on the back panel temporarily restores it.

1. Unplug and open the back (§2).
2. Under good light, inspect the solder joints — there are only two soldered areas: the LED strip connection and the controller board connections, plus the barrel-jack socket. Look for dull, grainy, or cracked solder, or a wire loose in its pad.
3. Reflow the suspect joint: heat it with a soldering iron (~350°C), add a little fresh solder, let it cool undisturbed. A good joint looks shiny and smooth.
4. Test before reassembling.

**Difficulty:** Moderate — basic soldering. If you've never soldered, this is learnable, but emailing me is a perfectly good choice. **Time:** 10–20 minutes.

### 4.8 Buttons — Primary and Recessed

**Primary button (the main one) unresponsive:**
1. First, power-cycle the mirror — unplug, wait 5 seconds, replug. This restarts the button software and fixes a glitch.
2. Still dead? Open the back and check the button: press it by hand for a tactile click, and inspect its solder joints.
3. If the switch itself is dead, desolder it and solder in a replacement — a generic 6×6mm tactile momentary switch. On Wi-Fi models, the app does everything the button does, so a dead button is an inconvenience, not a breakdown.

**Recessed button (the pinhole) unresponsive:**
1. Shine a light into the pinhole — can you see the button? Try a thinner pin, and press firmly; the recessed mount needs a bit more force.
2. If you recently reassembled the mirror, the printed housing may have shifted out of line with the pinhole. Open the back and nudge it back into alignment.
3. If the switch is genuinely dead, replace it — same 6×6mm tactile switch as the primary button.

**Difficulty:** Easy (power cycle, alignment) to moderate (switch replacement). **Time:** 1 minute to ~20 minutes.

---

## 5. The Recessed Button — Your Recovery Tool

The small pinhole button is the recovery lever for almost every software problem. It needs no tools but a paperclip, and you never have to open the mirror to use it.

| Hold the recessed button for… | What happens | Use it when |
|---|---|---|
| **3 seconds** | Slow indigo pulse — the mirror enters **pairing mode** | Connecting to Wi-Fi, or moving to a new network / new password |
| **10 seconds** | Red flash, then a green hold — **factory reset** | The mirror is misbehaving, stuck, or you want to wipe it back to out-of-box state |

The light feedback is also a test: if you see the indigo pulse at 3 seconds, the recessed button is working. A factory reset returns the mirror to its defaults — Indigo Signal color, no saved Wi-Fi — and clears most software trouble. It's safe to use any time.

---

## 6. Replacement Parts & Where to Buy Them

Almost every part is a commodity you can buy from many suppliers — your repair doesn't depend on Layered Logic staying in business. The few exceptions are noted.

| Part | Spec | Where | Approx. cost |
|---|---|---|---|
| LED strip | WS2812B, 60 LEDs/m (32 LEDs per mirror) | Amazon, AliExpress, Adafruit | $1.50–$5.00 |
| Power supply | 5V DC, barrel plug 5.5×2.1mm, 2A+ | Amazon, AliExpress, Adafruit | $3–$8 |
| Barrel-jack socket | 5.5×2.1mm DC socket | Amazon, DigiKey, Mouser, AliExpress | under $1 |
| Front panel (half-mirror acrylic) | 150×150×3.1mm | TT Plastic Land, or pre-cut from me | ~$5 |
| Back panel (full-mirror acrylic) | 150×150×3.1mm | Makerstock, or pre-cut from me | ~$2.50 |
| Tactile switch (either button) | 6×6mm through-hole momentary | Amazon, Adafruit, DigiKey, Mouser | pennies |
| Hookup wire | ~22 AWG silicone | any electronics supplier | minimal |
| Frame lumber | standard 2×4 | any hardware store | $3–$5/board |
| Printed parts (spacer, housing) | PETG, ~44g total | print from STL (I'll send it), or pre-printed from me | under $1 in filament |
| Controller board | per published schematic — **pre-flashed, from Layered Logic** | contact me | board cost + shipping |

I commit to keeping replacement controller boards available for **at least 7 years** from your mirror's ship date. The commodity parts above will outlast that on their own.

---

## 7. When to Contact Me

Email me — with your order number if you have it — for any of these:

- You'd rather not do a repair yourself. That's always a valid choice.
- A repair needs soldering and you're not comfortable with it.
- You need a **pre-flashed controller board**, or want to use the **reflash service** (send your board in, I reflash it, you pay only shipping).
- You need a pre-cut acrylic panel, a pre-printed part, or an STL file.
- A repair didn't fix the problem, or you can't tell what's wrong. Send photos — most things can be diagnosed by email.

I'd always rather help you fix the mirror than see you replace it. Before anything else: just ask.

---

## Open Items

- **Repair-time estimates** in Section 4 are working figures, to be confirmed against the first production golden-sample builds (Weeks 9–11).
- ~~**Panel labeling:** the failure-mode reference [acrylic-crack-scratch.md](../Failure_Modes/acrylic-crack-scratch.md) inverted the front/back panels.~~ Reconciled 2026-05-20: the failure-mode doc's "Which panel?" table now matches the assembly guide and this guide — 2-way mirror = front (viewer-facing half-mirror), 1-way mirror = back (full mirror).

---

## Related

- [Right-to-Repair Philosophy](right-to-repair-philosophy.md) — the values behind this guide
- [Assembly & Teardown Guide](assembly-guide.md) — §7 is the teardown procedure every repair here builds on
- [Failure Mode Inventory](../Failure_Modes/README.md) — the full technical analysis of all 17 failure modes
- [Repair Index](repair-index.md) — the entry point to the whole repair-doc set
- [Terms of Service & Warranty Policy](terms-of-service-and-warranty.md) — warranty coverage and the RMA process
- [Sprint Plan](../sprint_plan.md) — Week 8 deliverable [LL-042](../tasks.md#LL-042)

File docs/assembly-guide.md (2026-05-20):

---
title: Mirror Assembly & Teardown Guide
type: operations
phase: 3
week: 8
date: 2026-05-20
status: draft — assembly times pending golden-sample measurement
tags: [operations, assembly, teardown, manufacturing, repair]
---

# Mirror Assembly & Teardown Guide — Basic 6×6 Infinity Mirror

**Prepared by:** William White, Layered Logic LLC
**Date:** May 20, 2026
**Applies to:** Basic 6"×6" Infinity Mirror v1.0

---

> **Why this document exists.** It is the canonical reference for how a unit goes together — and, read in reverse, how it comes apart. The manufacturing sequence (Sections 4–6) is the operations-track build process. The teardown procedure (Section 7) is the access path the customer-facing [User Repair Guide](user-repair-guide.md) depends on: every repair in that guide starts by getting into the unit, and this is the document that says how.

---

## 1. Scope & Audiences

This guide serves two readers:

- **The builder** — assembling units. Sections 2–6 are the build process: sub-assembly prep, station-by-station manufacturing, and final assembly.
- **The repairer** — a customer or Layered Logic opening a finished unit to service it. Section 7 is the teardown/access procedure, written as the reverse of final assembly.

The full manufacturing process is captured at station granularity in `Assembly_docs/LED_Mirror_Station_Details.csv` (20 stations, S01–S20). This guide is the narrative companion to that table.

---

## 2. Tools & Workspace

### Tools

- **Phillips-head screwdriver** — the only tool required to open or close a finished unit. No proprietary bits.
- Suction-cup handles (×2) — for handling mirror panels without touching the faces.
- Plastic spudger / pick tool — for the snap-fit controller housing and seating sub-assemblies.
- For manufacturing only: miter saw, router table + handheld router, wet saw, soldering iron, 3D printer, bench PSU. See the station CSV for the full per-station tool list.

### Workspace

- A rubber bench mat protects mirror faces during assembly.
- Pack-and-ship is kept physically separate from cutting and sanding — sawdust and loose hardware contaminate finished units.

---

## 3. Parts Inventory (Per Unit)

From the [BOM Breakdown](bom-breakdown-basic-6x6.md):

| Part | Qty | Notes |
|---|---|---|
| Wood frame, 3-sided | 1 set | Cut from 2×4 lumber; mitered + glued; mirror channels + electronics pocket milled in |
| 1-way mirror acrylic panel | 1 | 150×150×3.1 mm — the back panel |
| 2-way mirror acrylic panel | 1 | 150×150×3.1 mm — the front (viewing) panel |
| WS2812B LED strip | 1 | 32 LEDs, soldered to a connector |
| LED spacer (PETG, printed) | 1 | Holds the strip; part of the LED sub-assembly |
| Controller PCB (ESP32-C3 module) | 1 | Replaceable module on its own board |
| Controller housing (PETG, printed) | 1 set | Snap-fit tray + lid |
| 5 V power supply | 1 | Barrel-jack brick — commodity, replaceable |
| Back panel (birch plywood) | 1 | 150×150 mm |
| Back reflector | 1 | Behind the LED plane |
| LED holders | 1 set | |
| Hardware | 1 set | Screws, wire |

Printed parts total ≈ 44 g PETG (LED spacer + controller housing).

---

## 4. Sub-Assemblies

Three sub-assemblies are built ahead of final assembly and staged.

### 4.1 Frame (stations S01–S06)

2×4 lumber is inspected and rough-cut (S01), precision-mitered to length (S02), then run through the router table to mill the **mirror channels** that the acrylic panels seat into (S03). One designated segment gets the **electronics pocket** routed into it for the controller housing (S04) — this is the only non-repeatable frame step, jig-controlled and test-fit against a printed housing before production. The frame is glued at the miter joints and clamped square (S05), then sanded and finished (S06). Finish is kept out of the mirror channels and the electronics pocket — it changes fit tolerances.

> The frame is a **permanent glued assembly.** It is not taken apart for repair. All internal access happens through the back panel (Section 7).

### 4.2 LED sub-assembly (stations S10–S12)

LED strip rolls are pre-tested at receiving (S10) — every LED must light. The strip is cut to length and a connector soldered to the VIN/GND/DATA pads using a solder jig, then power-tested again (S11). The tested strip is pressed into the printed PETG **LED spacer**, with the connector cable routed out the spacer's exit port (S12). Result: a `LED + spacer` sub-assembly staged for final assembly.

### 4.3 Controller sub-assembly (stations S13–S16)

Controller PCBs are inspected on receipt (S13), batch-flashed with firmware on the Raspberry Pi rig (S14 — flashed and unflashed trays are never mixed), soldered and function-tested (S15), then seated into the printed PETG **controller housing** (S16). The housing is a two-piece snap-fit design — see Section 8. Result: a `controller + housing` sub-assembly staged for final assembly.

---

## 5. Mirror Panels (stations S07–S09)

Acrylic mirror sheets are received and stored **vertically** with foam separators — never stacked flat, which chips edges (S07). Sheets are wet-cut into 6×6" blanks on the tile saw (S08); dry cutting micro-fractures the acrylic. For **custom orders only**, blank panels are pulled from inventory and cut to the per-order design on the laser/CNC (S09) — standard units skip this station.

Each unit uses one 1-way panel (back) and one 2-way panel (front).

---

## 6. Final Assembly (stations S17–S20)

### 6.1 Kitting (S17)

All sub-assemblies and hardware for one unit are pulled and checked against the kit checklist into a labeled order tray with a traveler card. A missing component sends the tray back — partial assembly never starts.

### 6.2 Assembly (S18)

Build order, into the finished frame:

1. **Controller housing** into the electronics pocket — seats flush.
2. **Mirror #1 (1-way / back panel)** laid into the milled channels.
3. **LED + spacer sub-assembly** seated against mirror #1.
4. **Mirror #2 (2-way / front panel)** laid into the channels — the infinity effect lives between the two panels.
5. **Back panel** installed and secured with screws.
6. **Cables** routed and managed before the back panel closes; the power connector is left accessible and strain-relieved.

Mirrors are handled with suction cups only — no bare hands on the faces.

### 6.3 QC (S19)

Full power-on test (all LEDs fire, no dead zones, no flicker), mirror inspection (no scratches/chips/misalignment), structural check (no rattles, backing flush), connector engagement check. Zero tolerance for dead LEDs or cracked mirrors — automatic rework. The traveler card is signed off.

### 6.4 Pack & Ship (S20)

The unit is wrapped, boxed with void fill, labeled, and logged. No unit is boxed without a completed traveler card.

---

## 7. Teardown / Access Procedure

This is final assembly (Section 6.2) run in reverse. It is the access path the [User Repair Guide](user-repair-guide.md) builds on — every component repair begins here.

**Before you start:** unplug the power supply. Work on a soft, clean surface. Have a Phillips screwdriver and suction-cup handles ready.

1. **Unplug the unit** and lay it face-down on a rubber mat or towel.
2. **Remove the back panel.** Back out the Phillips screws securing the birch-plywood back panel and set them aside (they are reused). Lift the panel off.
3. **Note the cable routing** before disturbing anything — a quick photo helps on reassembly. Free any cable ties as needed.
4. **Lift out the back reflector.**
5. **Lift out mirror #2 (front 2-way panel)** from its channels using suction cups. Set it face-up on a clean cloth.
6. **Lift out the LED + spacer sub-assembly.** The connector cable unplugs from the controller.
7. **Lift out mirror #1 (back 1-way panel)** the same way.
8. **Remove the controller housing** from the electronics pocket. To reach the PCB itself, open the snap-fit housing — see Section 8.

To reassemble, reverse the steps: controller housing → mirror #1 → LED sub-assembly → mirror #2 → back reflector → back panel. Re-route cables before the back panel goes on, and confirm the power connector is accessible.

> The wood frame is never disassembled — it is a glued structural unit. Every serviceable part is reached through the back panel.

---

## 8. The Controller Housing (Snap-Fit)

The controller PCB lives in a two-piece printed PETG enclosure: a **tray** (floor + walls, with compression snap pegs that retain the PCB through its mounting holes) and a **lid** with snap tabs that engage through-slots in the tray walls.

- **To open:** push each lid barb inward through its wall slot from the outside, then lift the lid free.
- **The PCB** is held by Y-split compression snap pegs through its mounting holes — flex the prongs to release.
- **No glue, no screws** in the housing itself; it is designed to open and reclose indefinitely.

The parametric housing model and its design history are in `Assembly_docs/basic_housing/` (`basic_housing.py`, Fusion 360 script; `sketch_housing_layout.py`, the layout sign-off).

> **Open item:** the housing model in `Assembly_docs/basic_housing/` is dimensioned for the earlier STM8 test board (25.83 × 21.7 mm). The shipping product uses the ESP32-C3 controller module — the housing footprint needs re-confirming against the production controller PCB before this section is final.

---

## 9. Open Items

- **Assembly times.** Per-station and per-unit assembly times are not yet measured. The [BOM Breakdown](bom-breakdown-basic-6x6.md) models ~50 min active labor at single-unit volume (10 min assembly + 30 min cutting + 10 min print setup), dropping toward 30 min at scale — these are estimates pending the golden-sample build (Weeks 9–11).
- **Controller housing footprint** — STM8 vs. ESP32-C3, see Section 8.
- **Back-panel fastener count and type** — to be confirmed against the production frame.

---

## Related

- `Assembly_docs/LED_Mirror_Station_Details.csv` — the full 20-station manufacturing process
- [User Repair Guide](user-repair-guide.md) — the customer-facing repair doc that consumes Section 7
- [BOM Breakdown — Basic 6×6](bom-breakdown-basic-6x6.md) — the parts inventory
- [Repair-Driven Design Decisions](repair-design-decisions.md) — why the unit is reopenable (Phillips-only, no bonded panels)
- [Failure Mode Inventory](../Failure_Modes/README.md) — what can break, and which teardown steps reach it
- [Sprint Plan](../sprint_plan.md) — Week 8 deliverable [LL-077](../tasks.md#LL-077)

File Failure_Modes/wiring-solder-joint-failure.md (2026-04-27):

---
title: "Wiring — Solder Joint Failure"
type: failure-mode
component: wiring
severity: medium
probability: low
user-repairable: partial
tags: [failure-mode, wiring, solder, connection]
---

# Wiring — Solder Joint Failure

A solder connection inside the mirror has failed — either a cold joint from manufacturing, a cracked joint from vibration/thermal cycling, or a broken wire at a solder point.

---

## Symptoms

- **Intermittent behavior** — the mirror works sometimes but cuts out when touched, moved, or bumped. The hallmark of a bad solder joint.
- LEDs flicker when the mirror is gently tapped or repositioned.
- The mirror works in one orientation but not another (gravity shifts a wire with a marginal connection).
- Complete LED failure that can be temporarily resolved by pressing on the back panel (applying pressure to the internal connections).

## Likely Causes

- **Cold solder joint from manufacturing** — insufficient heat during soldering leaves a crystalline, high-resistance joint that appears connected but fails under stress. Assembly QC at Stations S11 and S15 (visual inspection under loupe + power-on test) catches most of these.
- **Vibration fatigue** — repeated small vibrations (shipping, wall-mounted mirror near a door that slams) can crack a marginal joint over time.
- **Thermal cycling** — the LED strip heats up during operation and cools when off. Over thousands of cycles, solder joints at the strip connection can fatigue.
- **Mechanical stress** — pulling on a wire during a previous repair, or a wire routed under tension.

## Probability

**Low.** There are exactly two solder operations per unit: the LED strip connection and the controller PCB connection. Both are inspected under loupe and power-tested before final assembly. Solder joint failure is flagged in the production plan as the first bottleneck at scale and the first outsource candidate — the soldering operations get disproportionate QC attention.

## Repair Path

### Diagnosing which joint

1. Unplug the mirror.
2. Open the back panel (Phillips-head screws).
3. Visually inspect all solder joints under good light:
   - **LED strip connection** (3 joints: 5V, GND, Data) — where the strip connects to the controller or extension wire.
   - **Controller board** — the header pins or pads where wires attach.
   - **Barrel jack input** — where the power input wires meet the board.
4. Look for: dull/grainy solder (cold joint), cracked solder, a wire that's loose in its pad, or discoloration around a joint.

### Repairing the joint

1. Heat the suspect joint with a soldering iron (~350°C).
2. Add a small amount of fresh solder (leaded 60/40 or lead-free — match what's there).
3. Let it cool naturally (don't blow on it).
4. The repaired joint should be shiny and smooth (leaded) or slightly matte but uniform (lead-free).
5. Power on and test before reassembling.

### Tools Required

- Phillips-head screwdriver
- Soldering iron (any temperature-controlled iron — a Hakko FX-888D is the production reference, but any iron works)
- Solder (60/40 or lead-free)
- (Optional) Loupe or magnifying glass for inspection
- (Optional) Multimeter for continuity testing

### Parts Required

- None, unless the wire itself is broken (in which case: a few inches of silicone-insulated hookup wire, ~22 AWG).

### Estimated Difficulty

Moderate — requires basic soldering skills. If you've never soldered before, this is learnable (plenty of tutorials for through-hole rework), but contact support if you'd rather not.

### Estimated Time

10–20 minutes (diagnosis + reflow).

## When to Contact Support

- If you're not comfortable soldering.
- If you can't identify which joint is bad — support can walk you through diagnosis over email/photos.
- If reflowing the joint doesn't fix the issue — the problem may be a PCB trace crack or controller failure rather than the solder joint.

## Design Mitigations

- **Minimal solder operations** — only 2 solder points per unit (LED strip + controller board). Fewer joints = fewer potential failure points.
- **Loupe inspection at production** — every joint is visually inspected under magnification at Stations S11 and S15.
- **Power-on test after every solder operation** — no joint ships untested.
- **Connectorized connections preferred** — where possible, JST connectors are used instead of direct solder, making joints unnecessary.
- **Solder flagged as first outsource** — at volume, this is the first operation to be handled by a specialist, not a generalist. The production plan recognizes this as the highest-skill operation.

---

## Related

- [LED Strip — Total Failure](led-strip-total-failure.md) — if the strip appears dead, check the connection first
- [PSU — Voltage Instability](psu-voltage-instability.md) — intermittent power can look like a bad joint
- [Barrel Jack — Intermittent Connection](barrel-jack-intermittent.md) — the mechanical power connector, not the solder joint
- [Controller — Hardware Failure](controller-hardware-failure.md) — if the board itself is the issue

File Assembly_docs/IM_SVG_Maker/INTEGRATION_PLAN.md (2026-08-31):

# Visualizer Integration Plan

Scope for porting the IM_SVG_Maker preprocessing into the
[infinity_mirror_visualizer](https://github.com/bowbikes/infinity_mirror_visualizer)
React/Three.js app, so users can upload a JPG or a colored SVG and the 3D preview
shows the *actually-manufacturable* art (post-binarize, post-trace, post-size-floor,
post-nozzle-round).

## Goal

Today the visualizer accepts an already-prepped SVG. JPG is the format most users
actually have (photos, screenshots, marker drawings, downloaded logos). The
preview also doesn't currently reflect what manufacturing will do to the art —
the corner-rounding, the speckle removal, the dropping of unprintably thin
features. After the port:

1. Drop a JPG → see it binarized/dilated/traced live, with the size-floor and
   nozzle-rounding filters applied → 3D preview matches what Bill will fabricate.
2. Drop a colored SVG → click the fill that's "the cut" → same downstream
   preview.
3. The IM_SVG_Maker Python tool stays canonical and stays the engine for actual
   fab files at order time. The JS port is the **preview-time** layer.

## Boundary: what ports, what stays Python

| Module | Stays Python | Ports to JS | Why |
| --- | :---: | :---: | --- |
| `raster.py` (binarize, dilate, trace, size-floors) |  | ✅ | Browser needs JPG handling at upload time |
| `color_select.py` (fill listing + selection) |  | ✅ | Color-pick UX is inherently interactive |
| `svg_parse.py` (SVG → normalized polygons) |  | ✅ | Needed to drive the visualizer's 3D mesh |
| `geometry.py` nozzle rounding only |  | ✅ | The user-visible "cut shape" after manufacturing |
| `geometry.py` kerf/inset/base, `extrude.py`, `laser_export.py` | ✅ |  | Fab-only; runs once per order on Bill's machine |

The JS port stops at "manufacturable black silhouette." The 2D → 3D mesh step
already lives in the visualizer's `SvgIcon.jsx` (Three.js `SVGLoader`); the port
feeds the preprocessed black SVG into it unchanged.

## JS module layout (target)

```
infinity_mirror_visualizer/src/
  preprocess/
    index.js                # public API: preprocess({input, kind, opts}) → { svg, stats, warnings }
    raster.js               # JPG/PNG → black SVG (potrace.js + Canvas)
    colorSelect.js          # colored SVG → black SVG (DOM-walk + fill-match)
    sizeFloors.js           # min-island-area + min-feature-width filters (Clipper.js erosion test)
    nozzleRound.js          # opening-then-closing manufacturability rounding
    fixtures/               # synced from IM_SVG_Maker/tests/fixtures/
  components/
    UploadPanel.jsx         # new: dropzone accepting jpg/png/svg, replaces current SVG-only upload
    ColorPicker.jsx         # new: appears when uploaded SVG has multiple fills
    ManufacturabilityHints.jsx  # new: "feature X dropped — increase resolution or thicken stroke"
    SvgIcon.jsx             # unchanged downstream consumer
    ControlsPanel.jsx       # +1 section: "Manufacturability" with the two threshold sliders
```

Public API mirrors the Python tool's two CLI entry points so reasoning stays
consistent across implementations:

```js
// equivalent to `python scripts/raster_to_black_svg.py`
preprocessRaster(File | Blob, { thicknessMm, threshold, turdsize,
                                minIslandAreaMm2, minFeatureWidthMm,
                                maxLogoDimMm }) → { svgString, stats }

// equivalent to `python scripts/color_svg_to_black.py`
listColors(svgString) → ColorStat[]
selectByColor(svgString, { colors, tolerance, invert }) → { svgString, kept }

// after either of the above:
applyManufacturability(svgString, { minIslandAreaMm2, minFeatureWidthMm,
                                    nozzleDiameterMm }) → { svgString, droppedWarnings[] }
```

The visualizer's existing upload affordance becomes a thin shell over these.

## Library choices

| Need | Pick | Alternative considered | Why this one |
| --- | --- | --- | --- |
| Raster → vector trace | `potrace.js` (kilobtye port) | `imagetracerjs`, WASM potrace | Same algorithm family as the Python `potracer` → easiest parity. ~30 KB. No WASM. |
| Binarize + dilate | Canvas `ImageData` + 3×3 max-filter convolution | OpenCV.js | Self-written ~50 lines vs. a 10 MB WASM bundle. Same math. |
| Polygon offset / erosion (size floors + nozzle round) | `clipper-lib` (js-clipper) | `polygon-clipping`, `jsts` | Has `ClipperOffset` with round joins — exact `shapely.buffer(d, join_style='round')` equivalent. polygon-clipping has no offset. jsts is faithful but ~600 KB. |
| SVG path sampling | Three.js `SVGLoader` (already a dep) | `svg-path-parser`, hand-rolled | Already loaded; gives `ShapePath` objects we can flatten to polylines. |
| SVG fill resolution (color picker) | DOM + `getComputedStyle(el).fill` | `svgelements` port | Browser does CSS/inheritance resolution natively. No library. |
| Float-safe polygon comparison (parity tests) | `vitest` + `clipper-lib` symmetric-difference + area check | hand-rolled | Tooling Bill already uses in JS land. |

## Parity-test plan

Drift between the Python and JS pipelines is the central risk. Mitigation is a
small golden-input suite both pipelines must pass.

**Fixtures** (live in `IM_SVG_Maker/tests/fixtures/`, mirrored into the
visualizer at `src/preprocess/fixtures/` via a small `npm run sync-fixtures`
script — no submodule, just a copy):

| Fixture | Stresses |
| --- | --- |
| `demo_W_black.svg` | The locked baseline (single island, halo + interior). |
| `fox.jpg` | Raster trace, multi-island, dilation. |
| `Washington_Huskies_logo.svg` | Color picker (two fills). |
| `tiny_specks.jpg` | Speckle filtering — `raster_min_island_area_mm2`. |
| `hairline.svg` | Width-floor enforcement — `raster_min_feature_width_mm`. |
| `nested_holes.svg` | XOR / evenodd hole handling. |

**For each fixture, the Python tool emits the canonical black SVG** (committed
alongside the input as `<stem>.canonical.svg`). The JS port emits its own black
SVG at test time.

**Comparison metrics** (in `src/preprocess/__tests__/parity.test.js`):
1. **Island count** — must match exactly.
2. **Total polygon area** — within 2 % (tolerance for Bézier-sampling differences).
3. **Union bbox** — within 0.5 mm on each side.
4. **Symmetric difference area** — < 5 % of either input's area (catches shifted/rotated drift that area-match alone would miss).

A `python tools/regenerate_canonicals.py` script regenerates the `.canonical.svg`
files when the Python tool's behavior intentionally changes. Bill runs that and
commits; CI on the visualizer runs the JS-side parity tests.

## Order of work

Rough chunks, each independently shippable:

1. **JS module skeleton + parity harness.** Write the `preprocess/` directory
   with stub implementations that just pass through input → input. Wire the
   Vitest parity tests so they all fail loudly with clear diff output. Sync the
   golden fixtures from IM_SVG_Maker. (~½ day)

2. **Port `color_select.py`.** DOM walk + computed-fill matching + invert/tolerance.
   Easiest module, no math-library question. Gets the parity harness green on
   the Huskies fixture. (~½ day)

3. **Port `svg_parse.py` flatten.** Use Three.js SVGLoader to sample paths;
   normalize Y-flip + center + scale to `maxLogoDimMm`. Drives the rest.
   (~½ day)

4. **Port `raster.py` (binarize/dilate/trace).** Canvas pipeline + potrace.js +
   shell/hole assembly. Should get the fox parity test passing without the size
   floors. (~1 day)

5. **Port size-floor filters + nozzle rounding via Clipper.js.** Erosion-as-predicate
   for width floor (matches the May-26 decision), straight area filter, opening-
   then-closing for nozzle rounding. The last parity test goes green here. (~½ day)

6. **UI wire-up** — `UploadPanel`, `ColorPicker`, `ManufacturabilityHints`, the
   threshold sliders in `ControlsPanel`. Replaces the existing SVG-only upload
   with the new flow. (~1 day)

Total rough estimate: 3–4 working days. Sequential per chunk; each chunk leaves
the repo in a shippable state.

## Post-port follow-ups (notes only, not in scope of this port)

### Migrate hosting Netlify → Vercel

Trigger: Bill's preference; no technical blocker on Netlify.

Concrete steps when we get to it:
1. Add `vercel.json` with a Vite SPA preset (rewrite all to `/index.html` for
   client-side routing if any; Vite defaults otherwise).
2. Strip Netlify-specific config (`netlify.toml`, `_redirects`, build-image
   pins) — verify what's actually there first.
3. Connect the GitHub repo at vercel.com with framework preset "Vite", build
   command `npm run build`, output `dist/`.
4. Move custom domain. If the visualizer lives at `billwhite.me/infinity` or
   `layeredlogic.cc/infinity`, that's a Cloudflare DNS change to a Vercel CNAME
   ([reference_domain_layeredlogic](.claude/projects/C--Users-bowhi-Desktop-Independent-Study/memory/reference_domain_layeredlogic.md)
   covers the Cloudflare setup).
5. Test the preview deployments + the production deployment side-by-side
   against Netlify before flipping DNS. Decommission Netlify after a week of
   parallel operation.

### New UX modes

Bill flagged additional UX modes as a post-port follow-up but has not yet
specified them. Things this port should leave room for without locking in:

- The `preprocess/` module is *side-effect-free* and pure-function-shaped, so
  any mode (gallery, side-by-side compare, before/after slider, batch upload,
  saved-design library) plugs in without touching the algorithms.
- `UploadPanel`, `ColorPicker`, `ManufacturabilityHints` are siblings of
  `ControlsPanel`, not nested inside it — easy to hide/show per mode.
- The 3D scene takes a black-SVG string regardless of how it was produced —
  so swapping the upload-and-preprocess flow for, e.g., a "browse designs"
  flow doesn't touch the renderer.

**Action item for Bill:** enumerate the UX modes you have in mind so we can
sanity-check the module boundaries above and add concrete component sketches
before the port ships. Right now this is "design with optionality but no
concrete commitments."

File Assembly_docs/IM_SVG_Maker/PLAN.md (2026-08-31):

# Infinity Mirror SVG Processor — Plan

## Context

We're building a Python CLI that takes a **monochrome (black) SVG** — every path in the file represents the cut region — and emits the fabrication files for a Kintsugi-style infinity mirror:

1. **Laser-cut files** (SVG + DXF) for a 150×150 mm acrylic mirror tile — outer mirror outline plus an interior cutout matching the SVG.
2. **3D-printed plug** (3MF + STL) in clear PETG that fills the laser cutout. The plug has two stacked layers:
   - **Inset** (3 mm tall, matches acrylic thickness) — drops into the laser-cut hole, flush with the mirror's front face.
   - **Base** (1 mm tall) — sits behind the mirror, offset wider than the inset, overlapping each mirror fragment to hold them in place.

For multi-island logos, the base needs to grow wide enough to bridge islands into a single supporting piece while preferring to conserve filament.

**Out of scope for this project**: turning a multi-color SVG into the black input SVG. That's a separate future tool (it needs more user input — which color is the cut, how to handle overlaps, etc.). This program's contract is intentionally narrow: black in, fab files out.

**Demo input**: `demo_W_black.svg` (created during planning by extracting the gold halo path from `Washington_Huskies_logo.svg` and recoloring to black). The original colored SVG stays in the repo as reference but isn't consumed by the tool.

## Learnings from the prep / preview phase

- **Kerf must be a mm-offset, not a scale.** The original `scale: 1.05` was a multiplicative scale about the origin, which produces zero offset at the centroid and grows with distance — wrong physical model for a laser kerf (which is a fixed-width material gap). Replaced with `laser_kerf_mm` (uniform outward offset via `shapely.Polygon.buffer(dist)`).
- **All `buffer()` calls use `join_style="round"`.** Mitre joins extend wildly at sharp inner corners (the W's V notches are 30–45°, which would push a mitre out by 4–8× the offset distance). Round joins give a true uniform offset everywhere.
- **Nozzle rounding is applied to the cut polygon *before* deriving any output.** Both inside and outside corners are rounded to `nozzle_diameter_mm / 2` via opening-then-closing: `cut.buffer(-r).buffer(+r).buffer(+r).buffer(-r)`. Ensures no feature is sharper than the printer can reproduce, and the laser cut matches what gets printed (so the plug fits).
- **SVG → polygon topology** for the W: one outer subpath + one inner W-silhouette subpath, combined via `symmetric_difference` to produce a single polygon with one hole. Works for typical halo-style logos. For SVGs with many nested subpaths we'll need shell/hole sorting by area + containment.
- **SVG path sampling** uses `svgelements.Path.npoint(np.linspace(0, 1, 400))` — npoint requires a numpy array (passing a Python list raises `TypeError`).
- **Visual verification trick**: render the *difference* polygons (`laser - cut` for kerf band, `cut - inset` for clearance, `base - cut` for support overlap) as filled regions. Comparing two thin outlines produces misleading perception of width at concave corners; filled bands make uniformity obvious. Worth keeping for any visual debugging.
- **Base support engulfs small features.** When `base_offset_min_mm >= half-width-of-feature`, that interior mirror fragment is fully covered by the base — no glass shows, just plastic. Acceptable for v1; future option to detect and skip tiny fragments noted in Alternatives.
- **Matplotlib polygon-with-holes rendering** must use a single compound `PathPatch` with `MOVETO`/`LINETO`/`CLOSEPOLY` codes — naïvely "punching holes" by overdrawing white wipes out anything underneath.
- **Preview scripts to keep** as part of the repo (under `scripts/`) for future visual debugging: `preview_cutlines.py`, `preview_zoom.py`, `diag.py`. They drive the same pipeline functions as the CLI.
- **Raster preprocessor** lives in the package as `im_svg_maker.raster.trace_raster_to_svg(image, out_svg, cfg)`. `scripts/raster_to_black_svg.py` is a thin CLI wrapper around it. Takes raster_thickness_mm / raster_threshold / raster_turdsize from `variables.json` (overridable via CLI flags). Uses potracer for trace + a shell/hole assembly pass (sort by area desc, depth parity from `representative_point` containment) so the resulting SVG has proper topology for the main pipeline's XOR parser.
- **STRtree.nearest returns numpy.int64**, not a Python int, and doesn't reliably skip self. Replaced with a straight O(N²) pairwise `distance()` in `_nearest_island_gap` — fine for the island counts we'll see (typically <50).
- **`base_offset_per_island_mm` default lowered to 0.5** (from 3.0). With more than a couple islands, 3.0 produced runaway offsets (fox at 3 islands → 8 mm base, swallowing the whole logo as a blob). 0.5 keeps the base hugging the contour; the bridge-factor term still picks up the slack when islands are genuinely far apart.
- **Width-floor: erosion-as-test, not morphological opening.** First implementation of `raster_min_feature_width_mm` did `island.buffer(-w/2).buffer(+w/2)` (open) intending to prune thin parts in-place. On the fox at width=2.5mm this *fractured* the islands at every thin neck and the count went from 5 to 34 — the opposite of "filter out thin junk." Switched to using erosion only as a keep-or-drop predicate: if `island.buffer(-w/2)` is empty the whole island is too thin and gets dropped, otherwise the original (unmodified) island is kept. No reshaping, no fracturing, predictable behavior. Thin appendages on otherwise-thick islands still ride through — that's the main pipeline's nozzle-rounding job to clean up.
- **`color_select.py` matches on resolved fill via svgelements `reify=True`.** SVG fill resolution has to follow CSS/inheritance/transform paths (e.g. the Huskies SVG has its colors on `<path fill=...>` directly but real-world exports often inherit from a `<g style="fill:..."/>`). Doing this from raw XML is hand-rolled CSS; doing it via svgelements is one call. The emitted black SVG uses the `.d()` of the *transformed* path so the output coordinates are in viewport space, ready for the main pipeline's existing parser to re-XOR via evenodd.

## Inputs

- A monochrome SVG path file (e.g. `demo_W_black.svg`). All `<path>` elements are treated as the cut region; fill color is ignored. Convention is black fill so source files are visually obvious.
- `variables.json` — configuration. Will be expanded from the current `scale: 1.05` to:

```jsonc
{
  "mirror_size_mm": [150, 150],      // acrylic sheet size (centered)
  "max_logo_dim_mm": 100,            // longest side of logo fits within this
  "nozzle_diameter_mm": 0.6,         // 3D printer nozzle; all corners pre-rounded to radius = this/2
  "laser_kerf_mm": 0.1,              // uniform outward offset of the laser cut (mm, NOT a scale)
  "inset_clearance_mm": 0.15,        // plug inset perimeter shrinks by this for slide-in fit
  "inset_height_mm": 3.0,            // matches acrylic thickness
  "base_height_mm": 1.0,             // support layer thickness
  "base_offset_min_mm": 2.0,         // floor overlap each fragment must get
  "base_offset_per_island_mm": 0.5,  // extra offset per island beyond the first (small bonus; bridge handles the heavy lifting)
  "base_bridge_factor": 1.0,         // 0..1 — scales the auto-bridge requirement
  "raster_thickness_mm": 0.75,       // (preprocessor) dilate traced raster lines by this thickness
  "raster_threshold": 128,           // (preprocessor) grayscale threshold (0-255) for foreground detection
  "raster_turdsize": 8               // (preprocessor) ignore speckles smaller than this many pixels
}
```

Final base offset formula: `max(base_offset_min_mm + (N-1)*base_offset_per_island_mm, base_bridge_factor * (nearest_island_gap_mm / 2))`. Logged at run time so the user can see why a given offset was chosen.

## Outputs (written to `out/<svg-stem>/`)

- `laser.svg` — 150×150 mm outer rectangle + kerf-scaled gold cut as an interior hole. Strokes set to hairline red (`#FF0000`, 0.01 mm) — common laser convention.
- `laser.dxf` — same geometry as DXF (via `ezdxf`).
- `plug.3mf` — primary 3D file (carries mm units, more modern).
- `plug.stl` — STL fallback for slicers that prefer it.
- `run.log` — chosen parameters, island count, computed base offset, bounding boxes.

## Pipeline

1. **Parse SVG** — `svgelements` to load all `<path>` elements with their resolved cumulative transforms applied (matrix, scale, translate). Color/fill is ignored.
2. **Flatten paths to polygons** — segmentize Béziers via `svgelements`, build shapely `Polygon`/`MultiPolygon` honoring the SVG fill-rule so subpath holes become real holes.
3. **Normalize coordinates** — flip Y to standard math orientation, translate so logo bbox is centered at origin, scale uniformly so `max(width, height) == max_logo_dim_mm`.
4. **Build polygon set** — convert each closed path (with holes) into a `shapely.MultiPolygon`. Resolve fill-rule (likely evenodd for the halo — its interior W counts as a hole).
5. **Round to nozzle limit** — apply opening then closing with `r = nozzle_diameter_mm / 2` to the cut polygon. All subsequent geometry derives from this rounded cut.
6. **Compute geometries** (all `shapely` ops use `join_style="round"`):
   - `inset_poly` = `cut.buffer(-inset_clearance_mm)`.
   - `laser_poly` = `cut.buffer(+laser_kerf_mm)` (uniform mm offset, NOT a scale).
   - Detect **islands**: number of polygons in the `MultiPolygon` (top-level, holes don't count).
   - Auto-bridge gap = min nearest-neighbor distance between island bounds (use `shapely.STRtree`).
   - `base_offset` per formula above.
   - `base_poly` = `cut.buffer(+base_offset)` (expands outward AND shrinks holes inward — exactly the support overlap we want for both the inner W mirror fragment and the surrounding mirror).
7. **Extrude to 3D**:
   - `trimesh.creation.extrude_polygon(inset_poly, inset_height_mm)` → translate up by `base_height_mm`.
   - `trimesh.creation.extrude_polygon(base_poly, base_height_mm)` → sits at z=0.
   - Union with `trimesh.boolean.union` (manifold3d backend) to make one watertight mesh.
8. **Emit files** — `mesh.export('plug.3mf')`, `mesh.export('plug.stl')`. Laser SVG built by hand (small XML) so we control stroke styling; DXF via `ezdxf` polylines.

## Key files & libraries

New project layout (all new — no existing code to reuse):

```
IM_SVG_Maker/
  pyproject.toml              # uv/pip deps
  im_svg_maker/
    __init__.py
    cli.py                    # argparse entrypoint: `python -m im_svg_maker <svg>`
    config.py                 # load+validate variables.json (pydantic)
    svg_parse.py              # SVG → shapely MultiPolygon (all paths, color ignored)
    geometry.py               # nozzle rounding, kerf/inset/base offsets, islands, base formula
    extrude.py                # shapely → trimesh meshes, union, export
    laser_export.py           # SVG + DXF writers
    raster.py                 # raster image -> black SVG (potracer + shell/hole assembly)
  scripts/
    preview_cutlines.py       # filled-band 2D preview of cut/laser/inset/base
    preview_zoom.py           # zoomed kerf-band view for visual debugging
    diag.py                   # polygon topology / area / winding diagnostic
    raster_to_black_svg.py    # CLI wrapper around im_svg_maker.raster.trace_raster_to_svg
  Washington_Huskies_logo.svg # original colored reference, not consumed
  demo_W_black.svg            # demo input (already created)
  variables.json              # extended config
  out/                        # generated
```

Dependencies: `svgelements`, `shapely>=2`, `trimesh`, `manifold3d`, `ezdxf`, `pydantic`, `numpy`.

## Alternatives logged (not implemented)

Per the question round, these alternatives for the base shape were considered and rejected for v1 but worth recording:

- **Convex hull of islands** — always bridges, but loses the organic outline. Could be a future `base_strategy: "hull"` option.
- **Bounding rectangle** — simplest, ugliest, ruled out.
- **Per-island independent plugs** — would make the kintsugi look fragmented but break the "single plug" assumption.
- **Skip-tiny-fragment base** — detect interior mirror fragments smaller than `2 * base_offset` and stop the base from closing over them (so even tiny features keep a sliver of mirror visible). Adds complexity; defer until we see a logo where this matters. **(Implemented 2026-05-26 at a different layer than originally planned: `raster_min_island_area_mm2` and `raster_min_feature_width_mm` ship in [raster.py](im_svg_maker/raster.py) — i.e. in the jpg→svg preprocessor, since that's the path where ratty sub-threshold geometry actually enters the pipeline. A clean black SVG from the new color selector doesn't need the filter. Width-floor uses an erosion test (`island.buffer(-w/2)`) as a keep-or-drop predicate rather than a morphological opening — opening fractured islands at thin necks instead of pruning them. The main-pipeline-level skip-tiny-fragment idea remains a future option for hand-authored SVGs with deliberately small interior features.)**

## Verification

End-to-end manual test using the demo black SVG:

1. `python -m im_svg_maker demo_W_black.svg`
2. Confirm `out/demo_W_black/` contains all 5 files.
3. Open `laser.svg` in a browser / Inkscape — verify:
   - 150×150 mm outer rectangle.
   - Interior W-halo cut, centered, longest dim ≈ 100 mm.
   - Cut shape is visibly slightly larger than the plug inset (kerf scale).
4. Open `plug.3mf` in a slicer (PrusaSlicer / Bambu / Cura):
   - Inset layer (3 mm tall) is the gold halo shape.
   - Base layer (1 mm tall) sits below, wider than the inset, with the inner hole around the W slightly shrunken vs the inset's inner hole.
   - Mesh is manifold (slicer reports no errors).
5. `run.log` shows island count = 1, base offset = `base_offset_min_mm`.
6. Sanity-check on a synthetic multi-island SVG (two disconnected black circles, ~10 mm apart) — confirm base offset grows to bridge them into one polygon.

Physical verification (post-fab) is on the user — the program's job is geometric correctness and clean file output.

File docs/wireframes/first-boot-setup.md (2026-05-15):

---
title: First-boot Setup — Wi-Fi Provisioning (Wireframe + Design Rationale)
type: design-artifact
phase: 2
chapter: 3
status: draft
date: 2026-05-14
surface: Mobile (React Native, App/v1)
tags: [hcde, wireframe, design-rationale, app, provisioning, softap, setup]
---

# First-boot Setup — Wi-Fi Provisioning

> **Chapter 3 of the LL-047 design-rationale set.** First-time-user provisioning is the most consequential surface in the product — it's the only screen many users see *before* the mirror starts being useful, and it tears down its own communication channel as part of normal operation. That last fact drives most of the decisions on this page.

**TL;DR:** SoftAP captive provisioning is the V1 path. User joins `LL-Mirror-XXXXXX`, opens the app, app sees the device on `192.168.4.1` and reports "Mirror needs Wi-Fi setup." User has two choices: provide home Wi-Fi creds, or skip and use the mirror entirely over its own SoftAP (the works-out-of-the-box principle). Submit tears down the SoftAP — by the time the device knows whether the creds worked, the WS link is dead and the device can't tell the app what happened. The screen handles this by setting expectation up-front (status pill), validating client-side (WPA2 length), and surfacing an honest "we can't tell — here's how to verify" recovery flow rather than faking a success signal.

## Wireframe

First-boot setup wireframe with 6 numbered callouts and 4 alternate-state thumbnails

## Where this lives in the user journey

This is the **only** screen between "I just plugged in a new mirror" and "I can control it from my home network." Stage 6 (Unbox & Set Up) in the [service blueprint](../service-blueprint.md), specifically the *"connect it to my Wi-Fi"* branch — but with the *"skip Wi-Fi setup"* option this screen actually spans two Stage 6 outcomes: home-network operation vs. SoftAP-only operation.

Adjacent surfaces:
- **Stage 6 prequel — physical unboxing**: user joins `LL-Mirror-XXXXXX` from their phone's Wi-Fi settings, opens the app. The app's URL field defaults to `http://192.168.4.1/` (the SoftAP IP). When connection succeeds, this screen renders.
- **[Home — Controls](home-control.md) (chapter 2)** — where the user lands after a successful provisioning. If the user skipped, they land here while still connected to the SoftAP; if they provided creds and rejoined home Wi-Fi, the app reconnects to the mirror at its DHCP-assigned IP.
- **[Settings — Wi-Fi](settings-wifi.md) (chapter 1)** — the multi-network surface this screen is the prequel to; once on home Wi-Fi, adding additional networks is a Settings-side flow.

## Decisions

### ① SoftAP captive provisioning, not BLE

Source: [post-mini-sprint-bugs.md #6](../post-mini-sprint-bugs.md) · [firmware-spec.md §4.5.3](../firmware-spec.md)

The fundamental architectural choice for first-time setup. V1 ships SoftAP-only because:

1. **Works without an app.** The captive webapp at `192.168.4.1/` is reachable from any phone's browser. Users who don't want to install the LL app aren't locked out of provisioning.
2. **Single radio stack.** ESP32-C3 has both Wi-Fi and BLE, but using BLE for provisioning would mean a parallel pairing flow plus the BLE permission UX (Bluetooth scan / location permissions on Android, "find devices" on iOS).
3. **Familiar mental model.** Every smart-home device the user has set up before — TPLink, Govee, Hue Bridge — works this way.

The cost is bug #6: the SoftAP teardown during cred-test kills the WS connection before the device can report success/failure. BLE provisioning sidesteps this entirely because the BLE link doesn't depend on the Wi-Fi state — Espressif's `wifi_prov_mgr` BLE scheme can notify the client with `WIFI_PROV_CRED_FAIL` events carrying the underlying `wifi_prov_sta_fail_reason_t`. **Deferred to post-V1.** When BLE provisioning lands, it becomes the path for app users; SoftAP stays for browser-only users.

### ② Skip path — works out of the box

Source: [sprint_plan.md (Apr 22 firmware design principles)](../../sprint_plan.md)

The "Control directly (skip Wi-Fi setup)" button is the visible expression of a locked product principle: *the mirror works out of the box with no required smart-home connection.* Tapping this button keeps the phone on the SoftAP, dismisses the cred form, and routes the user straight to [Home — Controls](home-control.md). The mirror never leaves SoftAP mode unless explicitly told to.

The full set of consequences for the skip path:
- User controls the mirror over SoftAP for as long as they want (the mirror's SoftAP doesn't time out).
- Other devices on the user's home network can't reach the mirror until the user joins home Wi-Fi via Settings later.
- OTA isn't possible from the SoftAP path (no upstream internet) — flagged in the rationale doc, not in the UI.
- The user retains the option to provision later from Settings.

This is the deliberate alternative to the smart-home-mandatory pattern competitors use. Per [feedback_rf_minimal_unless_asked](../../.claude/projects/C--Users-bowhi-Desktop-Independent-Study/memory/feedback_rf_minimal_unless_asked.md), home Wi-Fi is opt-in.

### ③ Show/Hide password toggle

Source: [App.tsx:706-726](../../App/v1/App.tsx)

WPA2 passwords are usually 12-30 characters of mixed entropy — typos are the dominant failure mode for first-cred submission, and the SoftAP teardown turns typos into recovery loops. Show/Hide on the password field lets users verify before submit. Two specific details:

- **Per-field, not page-level.** Only password has Show/Hide; SSID is plain-text. Adding the toggle to SSID would imply privacy where there is none.
- **Resets to Hide after submit.** If the cred was wrong and the user reopens the page, the password starts hidden again. Re-attempts start safe rather than with the password visible on the screen.

### ④ Inline WPA2 length validation

Source: [App.tsx:727-729](../../App/v1/App.tsx) · WPA2 spec (IEEE 802.11i)

A static helper line lives below the password field (*"WPA2: empty (open) or 8-64 characters"*); it flips to an inline error in red (*"WPA2 passwords are at least 8 characters"*) when the field has 1-7 characters. This catches the most common pre-submit error without ever sending a guaranteed-failure to the firmware.

The cost of *not* validating here: the user submits a 5-char password, mirror tries it, mirror times out after 15s, falls back to SoftAP, user has to rejoin and start over. The cost of validating: 30 lines of React. The bug doc explicitly notes the SoftAP teardown amplifies every failure here, so any client-side preventable error is worth catching.

Open is allowed (empty password) for the rare hotel-network case — kept rather than blocking submit with an empty field.

### ⑤ Status pill anchors the mental model

Source: App.tsx URL+pill row (lines 614-632)

The green *"Connected to mirror via SoftAP"* pill at the top of the screen does load-bearing work for the user's mental model. The next button press (submit) tears that connection down. If the user doesn't know they're talking to *the mirror's network* and not *their home network*, the disconnect reads as "the app broke." Setting expectation up-front turns the disconnect into "yes, that's what was supposed to happen."

The pill is a real wire signal (the app's WS connection state), not a placeholder — it goes green only when the device responds to a ping, so the user can trust it as a readiness indicator.

### ⑥ "Connect to Wi-Fi" — verb-of-the-device, not verb-of-the-form

Source: [App.tsx:731-740](../../App/v1/App.tsx)

Button label is "Connect to Wi-Fi" — describing what the *device* is going to do — not "Save" or "Submit" — describing what the *form* is going to do. The verb framing matters because the operation has a long-running asynchronous side effect (joining a network) and the user needs to model what they're triggering, not what they're filling out.

On submit, the label switches to "Connecting…" — confirms the gesture landed and disables to prevent double-submit during the 15-second window. The "Connecting…" state outlives the WS connection (which dies as soon as the device leaves SoftAP); the app reads it from local in-flight state, not from a server ack.

## Alternate states

| State | Trigger | Design response |
|---|---|---|
| **① Initial (empty)** | First arrival on this screen | Helper text + Skip button visible; SSID/Password fields empty with placeholders. Submit disabled until SSID has 1+ char. |
| **② Password shown** | User taps "Show" | Password field renders in plain text; Show button flips to brand-indigo "Hide". On submit success, reverts to Hide for next time. |
| **③ Submitted / 15s** | User taps "Connect to Wi-Fi" | "Credentials sent" screen with brand-indigo countdown number (15 → 0). Copy explains the fallback. WS already dead by now — countdown is the only feedback channel. |
| **④ Timeout / Recovery** | Countdown reaches 0 with no broadcast confirmation | Honest "No confirmation" header; yellow warning box with recovery steps ("re-join SoftAP, try again"); explicit Next Steps if creds actually worked (switch phone Wi-Fi back to home, find mirror on home network). |

## Considered & rejected

**BLE provisioning as the V1 default.** Rejected for V1 — see callout ①. The architectural cost (parallel pairing flow + BLE permission UX) outweighed the bug #6 fix for V1 scope. Tracked as the right post-V1 move. The wireframe's **Deferred — BLE provisioning** section at the bottom is a placeholder mockup of the in-app success-confirmation flow BLE would enable; the SoftAP path can't ship this because the teardown kills the WS link before the device can report `WIFI_PROV_STA_CONNECTED` / `CRED_FAIL` back.

**Faking a success signal after submit.** Considered: have the app pretend the submit succeeded if it didn't hear back within 15s. Rejected — the SoftAP teardown means the app *fundamentally cannot know* whether the creds worked from inside the SoftAP, and false success would route users to a Home/Controls screen where nothing responds. Honest "we can't tell, here's how to verify" beats false confidence.

**Auto-discovering the mirror on the home network after submit.** Considered: app keeps trying to find the mirror via mDNS after the user switches their phone Wi-Fi back. Rejected for V1 — mDNS on Android requires the native `NsdManager` integration (already done for find-mirror in [LL-040](../../tasks.md#LL-040)), but the user-flow requires the phone-Wi-Fi switch first, and that's outside the app's control. Adding a "find mirror" CTA at the post-submit screen would be the productized version of this; currently lives as part of the Home/Controls page's connection panel.

**Showing the mirror's SoftAP password to the user.** No password — the SoftAP is open. Considered making it WPA2-protected for security but the mirror's SoftAP carries no real secrets (just the provisioning ack), and the open SoftAP means the user can join from any device's browser without typing the password.

## Research-to-design honesty

[LL-048](../../tasks.md#LL-048) interviews still pending. The first-boot setup is where qualitative research would most quickly surface mismatches between founder-intuition and real user behavior.

| Decision | Status | Notes |
|---|---|---|
| ① SoftAP vs BLE | architecture-locked | Driven by V1 scope + radio stack tradeoffs. The post-V1 BLE pivot is the right move; interview signal would help time it. |
| ② Skip path | founder-intuition + principle-aligned | "Works without home Wi-Fi" is a deliberate brand position. **Worth specifically asking interviewees whether they'd ever use it** — if zero out of N say yes, the skip button can become a settings-buried option instead of a primary CTA. |
| ③ Show/Hide password | usability-validated | Standard pattern; safe yes. |
| ④ Inline WPA2 validation | usability-validated | Standard. |
| ⑤ Status pill | founder-intuition | Hypothesis: explicit "connected to mirror via SoftAP" reduces post-submit confusion. Pretty plausible but worth observing in a usability test. |
| ⑥ "Connect to Wi-Fi" verb | founder-intuition | The verb-of-the-device argument is design-rationale-grounded but unvalidated. |

## Implementation gaps

- ✅ Form + skip path + validation + Show/Hide + submit countdown — all implemented in [App.tsx:667-741](../../App/v1/App.tsx)
- ✅ Connection pill — implemented (the `pill` style + state-derived class)
- ⚠️ **Recovery copy at timeout** — implemented but exactly the "bare-bones" state called out in [post-mini-sprint-bugs.md #6](../post-mini-sprint-bugs.md). User can recover but the experience is rough. BLE provisioning is the real fix; a partial mitigation is NVS-persisted last-cred-attempt diagnostic (medium effort, half-day) that survives SoftAP re-establishment.
- ⚠️ **Windows captive-portal redirect** — see [post-mini-sprint-bugs.md #5](../post-mini-sprint-bugs.md). The Windows captive notification opens Chrome to `msn.com` (WISPr fallback) rather than `192.168.4.1/`. Workaround documented; real fix is DHCP option 114 or WISPr v2 XML in the captive probe response.

## What shipped

- App: [App/v1/App.tsx](../../App/v1/App.tsx) (setup form, validation, submit, countdown)
- Webapp: parallel implementation at [Firmware/v1/webapp/](../../Firmware/v1/webapp/) — captive route at `192.168.4.1/setup` for browser-only users
- Firmware: [Firmware/v1/core/provisioning/](../../Firmware/v1/core/provisioning/) (SoftAP lifecycle, cred apply, fallback timer)
- Captive DNS: [Firmware/v1/core/captive_dns/](../../Firmware/v1/core/captive_dns/) — DNS hijack so any hostname lookup on the SoftAP resolves to the device

## References

- [Multi-Network Design Doc §4.1](../multi-network-design.md) — provisioning explicitly excluded from multi-network scope; this screen is the prequel
- [Post Mini-Sprint Bugs #5, #6](../post-mini-sprint-bugs.md) — Windows captive redirect + bare-bones SoftAP error flow
- [Firmware Spec §4.4 Provisioning](../firmware-spec.md) — wifi_prov_mgr ownership
- [App.tsx Setup flow](../../App/v1/App.tsx) (lines 614-741)
- [Service Blueprint Stage 6](../service-blueprint.md) — journey context
- [Settings — Wi-Fi (chapter 1)](settings-wifi.md) — successor surface for adding more networks
- [Home — Controls (chapter 2)](home-control.md) — successor surface for control after setup
- [feedback_rf_minimal_unless_asked](../../.claude/projects/C--Users-bowhi-Desktop-Independent-Study/memory/feedback_rf_minimal_unless_asked.md) — principle behind the skip path

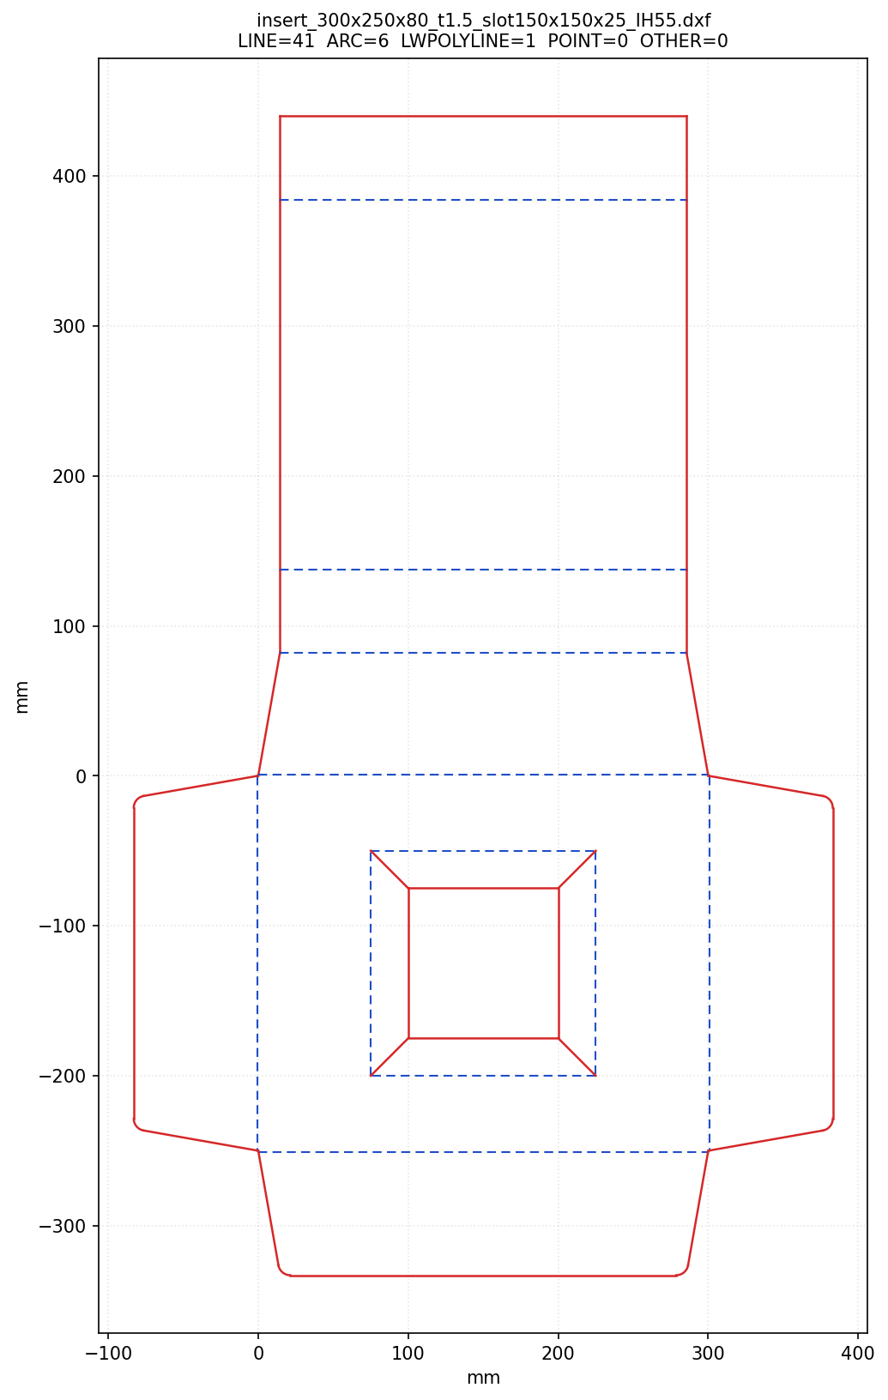
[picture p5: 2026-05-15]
Assembly_docs/packaging/passthrough_insert_300x250x80_t1.5_slot150x150x25_IH55.png

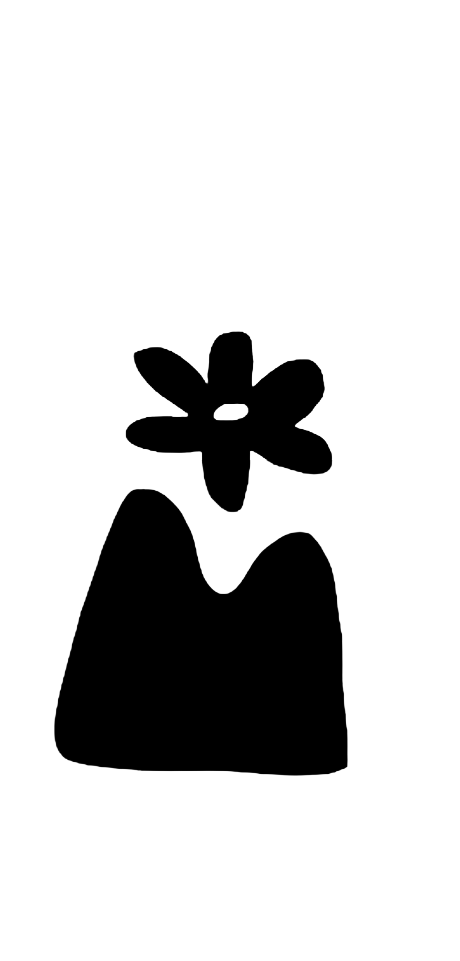
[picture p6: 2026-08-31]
Assembly_docs/IM_SVG_Maker/inputs/Empowder/empowder_src.png

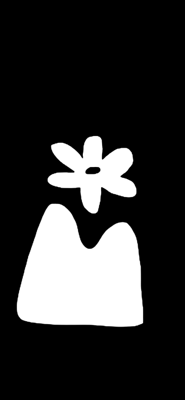
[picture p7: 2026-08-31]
Assembly_docs/IM_SVG_Maker/inputs/Empowder/extracted_0_prev.png

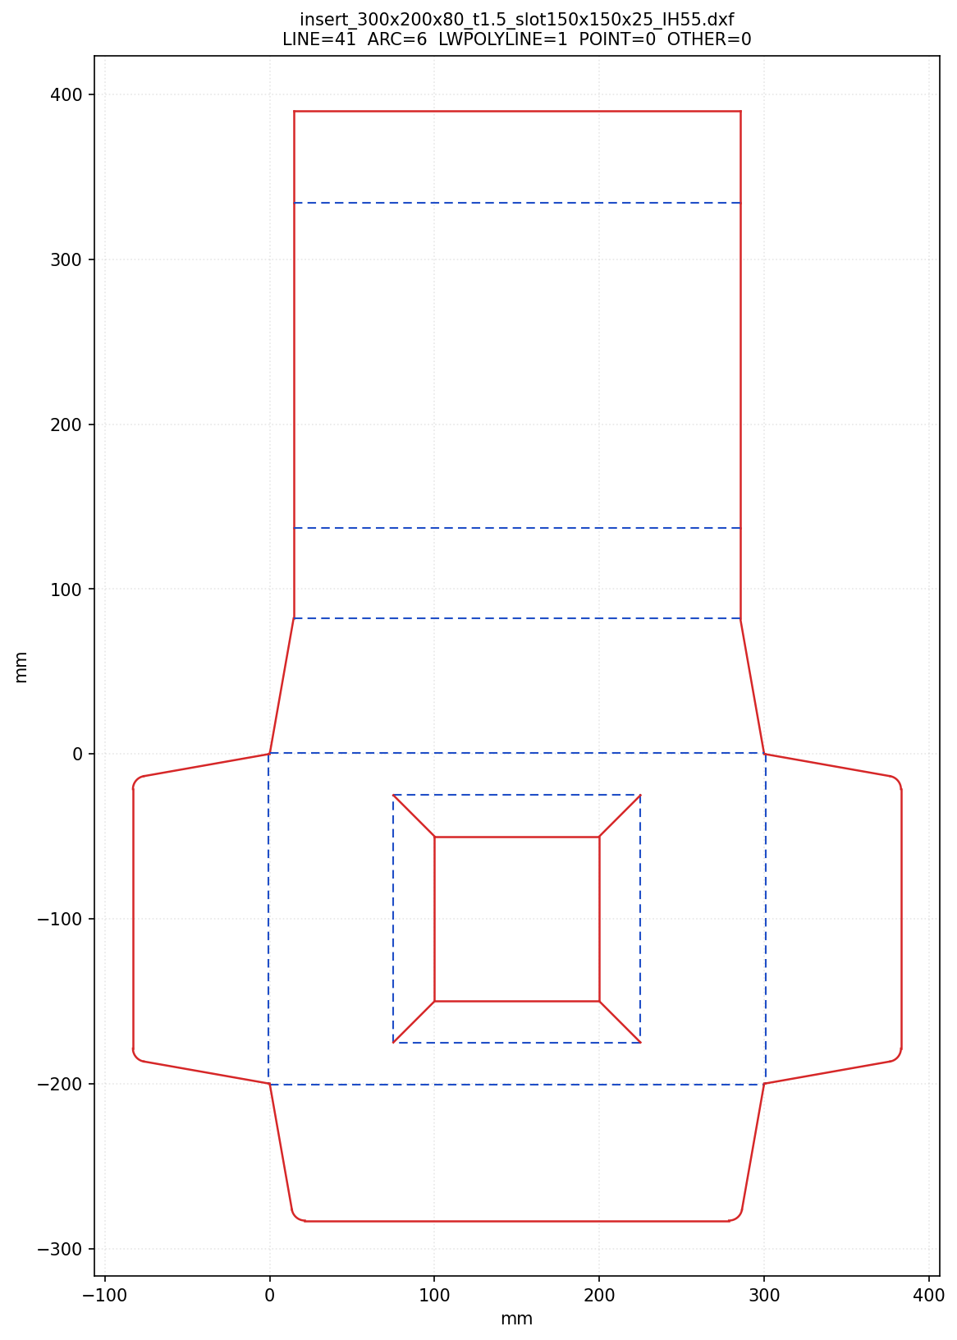
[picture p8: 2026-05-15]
Assembly_docs/packaging/passthrough_insert_300x200x80_t1.5_slot150x150x25_IH55.png

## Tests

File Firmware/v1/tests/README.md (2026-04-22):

# Host-side firmware tests

Unit tests for the pure-C modules of the firmware (anything that doesn't
pull in ESP-IDF / FreeRTOS). Built with plain CMake + a host C compiler.

## Run

```
cmake -S tests -B tests/build
cmake --build tests/build
ctest --test-dir tests/build --output-on-failure
```

The executable also runs standalone (`./tests/build/ll_firmware_tests`) if
you want raw output.

## Scope

Testable on host:
- `core/button/button_logic.c` — gesture state machines + cycle helpers
  (pure C, no ESP-IDF).
- `core/led_driver/led_driver_logic.c` — GRB reorder + brightness scaling
  for WS2812 frames (pure C, no RMT).
- `core/pattern_interp/patterns.c` — 7 stateless pattern renderers + the
  registry lookup.
- `core/pattern_interp/cue_logic.c` — cue overlay state machine and
  rendering for recessed-hold / factory-reset feedback.

Not tested here (on-target only):
- `core/button/button.c` — GPIO ISR + FreeRTOS task glue
- `core/state_bus/state_bus.c` — uses esp_event loop; would need a mock
- `core/led_driver/led_driver.c` — ESP-IDF RMT TX + WS2812 encoder
- `core/pattern_interp/pattern_interp.c` — render task + esp_event glue

If the on-target coverage gap matters, the next step is vendoring Unity
and running `idf.py build` + `idf.py -T button flash monitor` with a
test-runner app under `tests/on_target/`.

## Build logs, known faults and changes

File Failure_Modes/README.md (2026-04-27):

---
title: Failure Mode Inventory
type: hcde-artifact
phase: 2
week: 4
date: 2026-04-27
status: complete
tags: [failure-mode, repair, hcde, reliability]
---

# Failure Mode Inventory — Infinity Mirror v1.0

Enumerated failure modes for every user-serviceable component in the v1.0 infinity mirror. Each file documents symptoms, causes, probability, repair path, parts sourcing, and design mitigations.

This inventory is the technical companion to the [Right-to-Repair Philosophy](../docs/right-to-repair-philosophy.md) — it proves the claim that "every failure mode I can imagine has a user-serviceable path."

---

## LED Strip

| Failure Mode | Severity | Probability | User-Repairable |
|---|---|---|---|
| [Dead Pixel(s)](led-dead-pixel.md) | Low | Very Low | Yes |
| [Total Failure](led-strip-total-failure.md) | High | Very Low | Yes |
| [Color Degradation](led-color-degradation.md) | Low | Very Low | Yes |

## Power Supply

| Failure Mode | Severity | Probability | User-Repairable |
|---|---|---|---|
| [No Output](psu-no-output.md) | Critical | Low | Yes |
| [Voltage Instability](psu-voltage-instability.md) | Medium | Low | Yes |

## Controller / PCB

| Failure Mode | Severity | Probability | User-Repairable |
|---|---|---|---|
| [Hardware Failure](controller-hardware-failure.md) | High | Very Low | Partial |
| [Firmware Corruption](controller-firmware-corruption.md) | High | Very Low | Partial |
| [Wi-Fi Connectivity Loss](controller-wifi-failure.md) | Medium | Low | Yes |
| [NVS Data Loss](controller-nvs-corruption.md) | Low | Very Low | Yes |

## Acrylic Panels

| Failure Mode | Severity | Probability | User-Repairable |
|---|---|---|---|
| [Crack or Deep Scratch](acrylic-crack-scratch.md) | Medium | Low | Yes |
| [Coating Degradation](acrylic-coating-degradation.md) | Low | Very Low | Yes |

## Wood Frame

| Failure Mode | Severity | Probability | User-Repairable |
|---|---|---|---|
| [Physical Damage](frame-physical-damage.md) | Low | Low | Yes |

## PETG Printed Parts

| Failure Mode | Severity | Probability | User-Repairable |
|---|---|---|---|
| [Breakage](petg-breakage.md) | Low | Low | Yes |

## Wiring & Connections

| Failure Mode | Severity | Probability | User-Repairable |
|---|---|---|---|
| [Solder Joint Failure](wiring-solder-joint-failure.md) | Medium | Low | Partial |
| [Barrel Jack — Intermittent](barrel-jack-intermittent.md) | Medium | Low | Yes |

## Buttons

| Failure Mode | Severity | Probability | User-Repairable |
|---|---|---|---|
| [Primary Unresponsive](button-primary-failure.md) | Medium | Very Low | Partial |
| [Recessed Unresponsive](button-recessed-failure.md) | Medium | Very Low | Partial |

---

## Summary

- **17 failure modes** enumerated across 8 component categories.
- **12 fully user-repairable**, 5 partially user-repairable (require soldering or support for firmware).
- **0 non-repairable** — every failure mode has a service path.
- All repair parts are either commodity (available from any electronics/hardware supplier) or printable (STL on request).
- The only component requiring Layered Logic involvement is the controller firmware (closed binary — reflash service available at cost of shipping).

---

## Related

- [Right-to-Repair Philosophy](../docs/right-to-repair-philosophy.md) — the values framework this inventory supports
- [Sustainability Audit](../docs/sustainability-audit.md) — Stage 6 repairability matrix
- [BOM Breakdown](../docs/bom-breakdown-basic-6x6.md) — component costs and sourcing
- [Button Interface Design](../docs/button-interface.md) — factory reset and pairing recovery paths
- [Sprint Plan](../sprint_plan.md) — Week 4 deliverables

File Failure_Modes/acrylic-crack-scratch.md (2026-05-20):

---
title: "Acrylic Panel — Crack or Deep Scratch"
type: failure-mode
component: acrylic-panel
severity: medium
probability: low
user-repairable: yes
tags: [failure-mode, acrylic, mirror, physical-damage]
---

# Acrylic Panel — Crack or Deep Scratch

One of the acrylic mirror panels (1-way or 2-way) is cracked, chipped, or deeply scratched from impact or mishandling.

---

## Symptoms

- Visible crack line in the mirror surface, catching light or breaking the infinity effect.
- A deep scratch that disrupts the reflective coating and creates a visible mark.
- A chip at the edge or corner, typically from a drop or impact.
- The infinity effect looks "broken" — light leaks through the crack instead of reflecting.

## Likely Causes

- **Drop impact** — acrylic is more impact-resistant than glass but still cracks under point loads or edge impacts.
- **Flex stress** — if the mirror was packed, shipped, or stored with pressure on the face, the panel can crack.
- **Thermal shock** — unlikely in normal home use, but a very hot object placed on the mirror could crack the acrylic.
- **Over-tightening during assembly or repair** — the frame screws can stress the panel if tightened beyond snug.

## Probability

**Low.** Acrylic is more forgiving than glass — it flexes before cracking and doesn't shatter. The panels are mounted inside a wood frame that absorbs most edge impacts. Cracking requires a significant event (drop, crush, point impact).

## Repair Path

The panels are mounted in the frame — not glued, not permanently bonded. Replacement requires opening the mirror and swapping the damaged panel.

1. Unplug the mirror from power.
2. Remove the back panel screws (Phillips-head).
3. Remove the back panel, then carefully lift the LED spacer assembly to access the panels.
4. Slide the damaged panel out of the frame channel.
5. Slide the replacement panel in (match orientation — the reflective coating faces inward toward the LED cavity).
6. Reassemble: LED spacer, back panel, screws.

### Which panel?

| Panel | Position | Description |
|---|---|---|
| **2-way mirror** | Front (viewer-facing) | The see-through half-mirror you look at. Partially reflective, partially transparent: it reflects most light back into the cavity while letting enough through for the infinity tunnel to be visible. |
| **1-way mirror** | Back (behind the LEDs) | The full mirror behind the LED cavity. Fully reflective: it bounces all the light forward toward the front panel. |

### Tools Required

- Phillips-head screwdriver

### Parts Required

- **1-way mirror acrylic, 150mm × 150mm × 3.1mm** — Makerstock. ~$2.50/panel (cut from $9.95 12×12" sheet, 4 panels per sheet).
- **2-way mirror acrylic, 150mm × 150mm × 3.1mm** — TT Plastic Land. ~$5.00/panel (cut from $20 12×12" sheet, 4 panels per sheet).
- Panels need to be cut to size. If you have a laser cutter, use the provided cut file. Otherwise, contact support for a pre-cut panel.

### Estimated Difficulty

Moderate — requires careful handling to avoid scratching the new panel or damaging the LED strip during disassembly.

### Estimated Time

20–30 minutes.

## When to Contact Support

- If you need a pre-cut replacement panel (no laser cutter access).
- If the crack caused secondary damage to the LED strip or frame.
- If you're unsure which panel (1-way vs. 2-way) needs replacement.

## Design Mitigations

- **Panels are mounted, not glued** — replacement is non-destructive.
- **Wood frame absorbs impact** — the frame protects the panel edges from direct impact.
- **Acrylic over glass** — chosen for impact resistance, weight, and ease of laser cutting. The tradeoff is that acrylic scratches more easily than glass (see [Coating Degradation](acrylic-coating-degradation.md)).
- **Packaging design** — shipping box includes foam or corrugated spacers to prevent flex pressure on the panels.

---

## Related

- [Acrylic Panel — Coating Degradation](acrylic-coating-degradation.md) — gradual coating issues vs. impact damage
- [Frame — Physical Damage](frame-physical-damage.md) — if the frame is also damaged
- [Right-to-Repair Philosophy](../docs/right-to-repair-philosophy.md) — §4 acrylic EOL limitation acknowledged

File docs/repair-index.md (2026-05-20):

---
title: Repair Ecosystem — Index
type: moc
phase: 2
week: 5
status: active
tags: [moc, repair, hcde, portfolio, navigation]
---

# Repair Ecosystem — Index

> Sub-MOC for the Layered Logic repair story. Linked from the home note at [index.md](../index.md). Walk top-to-bottom for the narrative; jump by section for reference.

The repair commitment for the Infinity Mirror v1.0 spans five connected documents. None of them is a complete picture by itself — values without inventory is a slogan, inventory without rationale is a parts list, and a scorecard without philosophy is just numbers. This index ties them into one navigable artifact.

---

## 1. Start here — the value framework

[**Right-to-Repair Philosophy**](right-to-repair-philosophy.md)

The first-person values document. Why repair matters (pro-consumer conviction, environmental honesty, regulatory tailwind), what repair concretely means for v1.0, eight specific commitments, the honest limits, and what the buyer is asked to do in return. **Read first.** Everything else is downstream of this document.

---

## 2. The technical evidence

[**Failure Mode Inventory**](../Failure_Modes/README.md)

Seventeen enumerated failure modes across eight component categories: LED strip, PSU, controller/PCB, acrylic panels, wood frame, PETG printed parts, wiring, buttons. Each failure mode has its own file with symptoms, causes, probability, repair path, parts sourcing, and design mitigations. This is the answer to "okay, but what does *user-repairable* actually mean for this product?" — twelve fully user-repairable, five partial, zero non-repairable.

Per-failure-mode files (linked from the inventory README):

- **LED strip:** [dead pixel](../Failure_Modes/led-dead-pixel.md) · [total failure](../Failure_Modes/led-strip-total-failure.md) · [color degradation](../Failure_Modes/led-color-degradation.md)
- **PSU:** [no output](../Failure_Modes/psu-no-output.md) · [voltage instability](../Failure_Modes/psu-voltage-instability.md)
- **Controller / PCB:** [hardware failure](../Failure_Modes/controller-hardware-failure.md) · [firmware corruption](../Failure_Modes/controller-firmware-corruption.md) · [Wi-Fi failure](../Failure_Modes/controller-wifi-failure.md) · [NVS corruption](../Failure_Modes/controller-nvs-corruption.md)
- **Acrylic panels:** [crack/scratch](../Failure_Modes/acrylic-crack-scratch.md) · [coating degradation](../Failure_Modes/acrylic-coating-degradation.md)
- **Wood frame:** [physical damage](../Failure_Modes/frame-physical-damage.md)
- **PETG printed parts:** [breakage](../Failure_Modes/petg-breakage.md)
- **Wiring:** [solder joint failure](../Failure_Modes/wiring-solder-joint-failure.md) · [barrel jack intermittent](../Failure_Modes/barrel-jack-intermittent.md)
- **Buttons:** [primary unresponsive](../Failure_Modes/button-primary-failure.md) · [recessed unresponsive](../Failure_Modes/button-recessed-failure.md)

---

## 3. The design rationale

[**Repair-Driven Design Decisions**](repair-design-decisions.md)

Twenty design decisions made during v1.0 development, each one cross-referenced against the repair values it serves and the failure modes it pre-empts. This is the artifact that demonstrates repair wasn't retrofitted — it shaped the choices from the start. Format is matrix-first: every row terminates at a specific failure mode and a specific source citation, not at narrative.

---

## 4. The numbers

[**Repairability Scorecard**](repairability-scorecard.md)

Quantitative companion to the philosophy doc. Top-line: 17 failure modes, 12 fully user-repairable (71%), 0 non-repairable (0%), Phillips screwdriver as the single tool requirement, 7-year minimum replacement-part commitment. Per-failure-mode breakdown of severity, repair tier, tools, parts source, and estimated repair time. Several time-cells are placeholders pending golden-sample measurement; flagged in the doc.

---

## 5. The supporting context

These docs aren't part of the repair ecosystem proper but are load-bearing context for the repair claims:

- [**Sustainability Audit**](sustainability-audit.md) — lifecycle data behind the "long-service-life" claim. Stage 6 directly addresses repairability; Stage 7 covers end-of-life paths and the acrylic-coating recyclability gap that bounds the philosophy's promises.
- [**Brand Positioning**](brand-positioning.md) — the "Living" brand adjective is the values bridge between the repair philosophy and the consumer-facing brand promise. §4 voice is the first-person framing this whole repair-doc set inherits.
- [**BOM Breakdown**](bom-breakdown-basic-6x6.md) — component-by-component cost and sourcing data backing the parts-availability claims.
- [**Firmware Architecture Scoping**](firmware-architecture-scoping.md) — where the OTA / closed-binary / reflash-service architecture is technically defined.
- [**Firmware Security Model**](firmware-security.md) — auth modes, OTA signing, telemetry. Adjacent to repair: a closed binary that is *also* signed and rolled out responsibly is a different thing than a closed binary that is opaque about its update process.
- [**Button Interface Design**](button-interface.md) and [**Button Design Rationale**](button-design-rationale.md) — the recessed factory-reset button is one of the most-cited self-recovery mechanisms in the design-decisions matrix; its rationale lives here.

---

## 6. The buyer-facing wrapper

[**User Repair Guide**](user-repair-guide.md) — *complete (draft), Week 8*

The customer-facing how-to companion. It translates the failure-mode files into procedural instructions a non-technical buyer can follow: which screwdriver, which strip part number, where to email for the STL, how to use the recessed button to recover from a wedged Wi-Fi state. Its teardown steps build on the [Assembly & Teardown Guide](assembly-guide.md) §7 — the operations-track document the repair guide was previously blocked on.

The philosophy + inventory + decisions + scorecard are the *technical* and *values* foundation; the User Repair Guide is the *experiential* surface that lands in the buyer's hand. They share the same backing data; they differ in voice and detail level.

---

## 7. Pending — packaging integration

[**Packaging QR code**](packaging-qr-code.md) *(blocked — Apr 28)*

Per [philosophy §6](right-to-repair-philosophy.md#6-what-this-asks-of-the-buyer), the buyer reaches the repair docs via a QR code laser-etched into the outer cardboard. Blocked on final packaging design (stock, dimensions, cutting process). Once packaging is locked, the QR code pass adds zero material — the laser cutter etches the link in the same pass that scores the box.

---

## How to read this set

For different readers, in order of expected utility:

| If you are… | Read in this order |
|---|---|
| **A buyer wondering "is this thing fixable?"** | Repair Index (this doc, §1–4 summary) → User Repair Guide → Failure Mode Inventory README |
| **An advisor reviewing the HCDE portfolio** | Right-to-Repair Philosophy → Repair-Driven Design Decisions → Repairability Scorecard → Sustainability Audit Stage 6–7 |
| **A regulator checking compliance** | Right-to-Repair Philosophy §3 (commitments) + §5 (compliance) → Failure Mode Inventory → Repairability Scorecard §4 (parts independence) |
| **A future Layered Logic engineer** | Repair-Driven Design Decisions matrix → Firmware Architecture Scoping → Failure Mode Inventory per-component files |
| **A repair shop or hobbyist** | Right-to-Repair Philosophy §3 (commitments) → Failure Mode Inventory → Public schematic refs (when published per §3) |

---

## Maintenance

This index is intended to stay current with the repair-ecosystem doc set. If a new repair doc lands, link it from §3 (rationale) or §5 (supporting context) by topic. If the User Repair Guide ships, replace the §6 placeholder with a real link and trim the "pending" framing. The philosophy doc itself is treated as load-bearing — changes to it cascade through the matrix and scorecard, and a deliberate edit pass on all three should follow any revision to it.

---

## Related

- [Home Note (index.md)](../index.md) — repository top-level MOC; this sub-MOC is linked from there
- [Right-to-Repair Philosophy](right-to-repair-philosophy.md)
- [Failure Mode Inventory](../Failure_Modes/README.md)
- [Repair-Driven Design Decisions](repair-design-decisions.md)
- [Repairability Scorecard](repairability-scorecard.md)
- [Sustainability Audit](sustainability-audit.md)
- [Sprint Plan](../sprint_plan.md) — Week 4 deliverables, Week 8 follow-ups

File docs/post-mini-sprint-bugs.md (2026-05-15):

---
title: Post-Mini-Sprint Bug Backlog
type: engineering
phase: 2
opened: 2026-04-29
status: tracking
tags: [bugs, backlog, mini-sprint, firmware, webapp]
---

# Post-Mini-Sprint Bug Backlog

Bugs and rough edges deferred during the [Apr 28 → May 5 app demo mini-sprint](mini-sprint-app-demo.md) to keep the demo-readiness path unblocked. Triage these after the May 5 faculty advisor demo lands.

Each entry should carry: severity, surfaces, first observed, hypothesized cause, reproduction, possible fixes. Severity uses **High** (blocks demo / customer-visible / data-loss risk), **Medium** (visible but recoverable / ergonomic), **Low** (cosmetic / rare).

---

## Open

### #6 — Error flow during set_wifi_creds is bare-bones

**Severity:** Medium (functional but ergonomic — affects every "wrong password" recovery)
**Surfaces:** Webapp `/setup` page, after a `set_wifi_creds` submission with credentials the device can't actually use
**First observed:** Session 5 sub-4 closing UAT, 2026-04-29

**Symptom**
When the user submits credentials that don't work (wrong password, network out of range, typo'd SSID, hidden network not in scan range, etc.), the device does what it's told: tears down the SoftAP, attempts STA join, fails over the 15s window, falls back to SoftAP via the `apply_creds_fallback_cb` timer. From the webapp's perspective, the only signal is "the countdown ran out and I never got a fresh state broadcast." The user has to manually re-join `LL-Mirror-...`, reload the page, and reattempt. There's no failure-specific messaging ("password was wrong" vs "network not found" vs "out of range") because the webapp's WS connection died before any of that information could be relayed.

**Hypothesized root cause**
Architectural: the cred-application path tears down the very network the webapp is using to talk to the device, so the device can't tell the webapp anything about success or failure of the join attempt. The webapp can only infer "didn't work" from "didn't get a state update within the timeout window."

This is largely intrinsic to SoftAP-based provisioning: the laptop/phone client and the device share the same SoftAP for the cred-submission conversation, but the device has to leave that SoftAP to test the new creds. Any failure information generated post-leave is unreachable.

**Why BLE provisioning sidesteps this**
With BLE, the link to the provisioning client doesn't depend on the wifi state. The device can:
- Apply creds → try connecting → succeed → notify the BLE client "joined SSID X with IP Y"
- Apply creds → try connecting → fail with `WIFI_REASON_AUTH_EXPIRE` → notify the BLE client "wrong password, try again"
- Stay in BLE-pairing mode the whole time, with no SoftAP teardown

Espressif's `wifi_prov_mgr` BLE scheme already does exactly this — `WIFI_PROV_CRED_FAIL` events carry the underlying `wifi_prov_sta_fail_reason_t` which the webapp / RN app can surface as actionable text.

**Possible fixes (ordered by feasibility)**
1. **Adopt BLE provisioning post-V1.** Cleanest fix; aligns with the stretch goal in [mini-sprint-app-demo.md §4](mini-sprint-app-demo.md). Webapp keeps its SoftAP-only role for users who don't want a phone app; RN app gets BLE for richer error messaging. This is probably where this lands.
2. **Persist a "last-cred-attempt" diagnostic in NVS** the firmware writes before falling back. When the fallback restores SoftAP and the user reconnects, the webapp's `get_state` returns the last failure reason and the setup page shows it ("last attempt: wrong password"). Survives the SoftAP teardown via NVS persistence. Medium effort, ~half-day. Doesn't help mid-flight UX but improves recovery.
3. **APSTA mode during the cred-test window.** Run the SoftAP and the STA simultaneously while testing creds, only tear down the SoftAP after a successful join. Lets the webapp keep its socket alive and receive a real success/failure event. Tradeoff: APSTA mode uses more RAM + has its own quirks (channel must match the STA's, complicating things). Half-day.

**Demo-day workaround**
Document the recovery path: "if the mirror doesn't appear on your network within 15-20 seconds, the credentials were wrong — re-join `LL-Mirror-...` and try again." Acceptable for a 3-minute advisor demo; not acceptable for end-user shipping.

---

## Closed

### #2 — `state.on` and `state.brightness` can disagree (misleading wire state)

**Closed:** 2026-05-15 by [LL-075](../tasks.md#LL-075) — fix #2 from the original ROI list (couple them in `apply_event`), with an additional auto-restore on power-on so the button single-press path doesn't strand at brightness=0.

**Severity (at close):** Was Medium (visible, ergonomic). Now eliminated at the data-model layer.

**Symptom (historical)**
The wire `state.on` field could report `true` while `state.brightness` was 0 — LEDs dark, but the diagnostics panel showed `on=true`. The webapp's power toggle (which uses `state.on` directly per closed bug #3) had already been disambiguated from the brightness-derived inference, so the user-facing impact was mostly diagnostics-view confusion. The data model still permitted the contradictory state, and the symmetric case (`on=false, brightness>0`) also leaked through if a client posted `{on:false}` alone.

**Root cause (historical)**
`ll_state_t` carried `on` and `brightness` as independent fields mutated by independent state-bus events. No invariant was enforced anywhere — `apply_event` set whichever field the event named and left the other one alone.

**Fix shipped — LL-075** ([Firmware/v1/core/state_bus/state_bus.c](../Firmware/v1/core/state_bus/state_bus.c))

Two coupled invariants in `apply_event`:

- `LL_EV_BRIGHTNESS{value}` now also sets `on = (value > 0)`. brightness=0 implies !on; brightness>0 implies on.
- `LL_EV_POWER_TOGGLE{on:true}` auto-restores `brightness` to 75 (the `LL_BRIGHTNESS_RESUME_DEFAULT` constant) when current brightness is 0. So a webapp `{brightness:0}` set followed by a button single-press from off leaves the device at (on=true, brightness=75) — not stranded at brightness=0 with LEDs still dark.
- `LL_EV_POWER_TOGGLE{on:false}` deliberately **preserves brightness** — button long-hold → single-press cycle keeps the user's brightness setting. The renderer gates on `s->on` ([pattern_interp.c:151](../Firmware/v1/core/pattern_interp/pattern_interp.c)) so (on=false, brightness=75) renders dark; brightness is just preserved memory.

Boot self-heal in `ll_state_bus_init` catches legacy NVS blobs that carry the contradictory (on=true, brightness=0) and corrects on first load.

Verified on the live mirror via [ll_on_brightness_invariant_test.py](../Firmware/v1/scripts/ll_on_brightness_invariant_test.py) — all 6 cases pass (single-field brightness 0/non-zero, single-field on true/false, coupled webapp envelopes both ways).

### #1 — Transient `socket closed` errors under user load

**Closed:** 2026-05-15 across [LL-055](../tasks.md#LL-055) Sessions A-C (all four proposed fixes shipped).

**Severity (at close):** Was Low (cosmetic + auto-recoverable). Now fixed end-to-end at the firmware capacity layer.

**Symptom (historical)**
"socket closed" or "not connected" briefly flashes in the connection-status panel of the webapp when the user clicks several controls in rapid succession. Webapp reconnect-with-backoff (1-8s) recovers, but the error was user-visible.

**Root cause (historical)**
`esp_http_server`'s WS handler is single-task and serializes inbound dispatch + outbound broadcasts. Any state change triggers a fanout to all connected clients via `broadcast_state`, so one inbound message → N+1 frames of work on that one task. Network jitter on the SoftAP filled the framework's send queue and dropped connections. Spec §7.1's 10 msg/sec rate limit was documented but not enforced.

**Fixes shipped (chronological)**
1. **Coalesce broadcasts within a debounce window** — May 14 ([sprint_log entry](../sprint_log.md), commit on `claude/happy-lehmann-907629`). 30ms one-shot timer in [transport.c](../Firmware/v1/core/transport/transport.c); first call arms the timer, subsequent calls within the window coalesce. 3-field set_state went from 3 broadcasts → 1; 6 rapid clicks at ~30ms went from 6 → 2.
2. **Move broadcast fanout to a dedicated FreeRTOS task** — May 15 (LL-055 Session B). New `ll_broadcast` task (4 KB stack, prio 4) consumes a depth-2 queue of broadcast tokens; debounce timer cb posts to the queue instead of running do_broadcast_state synchronously. Verified via [ll_slow_client_test.py](../Firmware/v1/scripts/ll_slow_client_test.py): a slow client pinning a socket no longer affects inbound RTT (median 72→71 ms, 20/20 responses in both phases).
3. **Implement spec §7.1 rate limit** — May 15 (LL-055 Session C). Per-IP token bucket (10 msg/s, burst 10) in WS receive path; overrun → close 1008 + `httpd_sess_trigger_close`. Verified via [ll_ratelimit_test.py](../Firmware/v1/scripts/ll_ratelimit_test.py): steady 10 msg/s = 30/30 clean; flood 50 msg/s = close 1008 at 0.43s.
4. **Disable Wi-Fi power-save on the STA path** — May 15 (LL-055 Session A). Audit found zero `esp_wifi_set_ps` calls; new `ll_wifi_disable_ps()` helper + `WIFI_PS_NONE` at all four `esp_wifi_start` sites in [provisioning.c](../Firmware/v1/core/provisioning/provisioning.c). First-response latency dropped 155 → 84 ms (Test A, −46%) and 136 → 64 ms (Test B, −53%).

The full resilience characterization suite from LL-055 Session D (reconnect hammer, latency/loss proxy, 5-minute soak) confirms the firmware now handles realistic user loads without the originating symptom. Webapp-side mitigations (commit-on-release sliders, reconnect-with-backoff) remain in place as defense-in-depth.

### #3 — Color / pattern controls don't auto-power-on the device when LEDs are off

**Closed:** Session 5 sub-4, 2026-04-29 (commit pending)
**Fix:** Webapp `pages/control.tsx` now treats any active selection (color preset, color picker, pattern dropdown, brightness slider above 0) as an implicit power-on. The handlers send `{on: true, ...}` patches when `state.on` is false, restoring the last observed active brightness if `state.brightness` was 0. Brightness slider is also coupled the other way: dragging to 0 sends `{brightness: 0, on: false}`. The power toggle now reads `state.on` directly (firmware truth) instead of inferring from `brightness > 0`, so the hardware power button's effect is correctly reflected in the webapp's UI.

The underlying wire-state coupling (#2) is still open — the firmware can theoretically have `on=true, brightness=0` from button-modality interactions — but #3's user-facing symptom (web controls don't turn on the LEDs) is gone.

### #5 — Windows captive sheet's "open browser and connect" link goes to MSN, not the webapp

**Severity:** Medium (documented workaround — manually navigate; phone-side path works correctly)
**Surfaces:** Windows 10/11 dev PC connecting to the mirror's SoftAP via Chrome (and likely Edge / other browsers)
**First observed:** Session 5 sub-3 closing UAT, 2026-04-29

**Symptom**
On a Windows machine joining `LL-Mirror-XXXXXX`, the OS shows a notification: *"Open browser and sign in to Wi-Fi network."* Clicking it opens Chrome to `https://www.msn.com/?ocid=wispr&pc=u477` instead of the webapp at `http://192.168.4.1/`. Waiting on that page does nothing — it's the real MSN. The user can manually navigate to the device URL and the webapp loads fine.

**Hypothesized root cause**
Two-layer issue:

1. **WISPr v2 fallback in Windows.** Windows expects either (a) RFC 8910 DHCP option 114 (Captive-Portal URL) advertising the login URL at DHCP-lease time, or (b) a WISPr v2 XML payload embedded in the captive-portal probe response. We provide neither — our 404 redirect returns plain HTTP 302 to `/`. With no proper "where's the login page?" signal, Windows falls back to its hardcoded default sign-in page (`msn.com/?ocid=wispr`).
2. **HSTS + DoH on `msn.com`.** `msn.com` is in Chrome's HSTS preload list, so the browser refuses to speak HTTP. Even if our DNS hijack catches the resolution, Chrome would only attempt HTTPS:443, which the device doesn't serve. And many Chrome installs use DNS-over-HTTPS to bypass local DNS entirely. Combined: the browser opens the *real* msn.com over the dev PC's other internet path (ethernet, in this case), bypassing the captive-portal flow entirely.

**Reproduction**
1. Dev PC must have a working secondary internet path (ethernet, Tailscale, etc.) — without that, Chrome would just fail.
2. Forget the `LL-Mirror-XXXXXX` profile in Windows (so it re-runs the full captive probe on rejoin).
3. Join the SoftAP. Wait for the "Open browser and sign in" notification.
4. Click the notification. Chrome opens to `https://www.msn.com/?ocid=wispr&pc=u477`.

**Why phones work**
Android and iOS captive-portal probes run on a single network path (the Wi-Fi the phone just joined), so when we hijack DNS + return a 302, the OS opens the redirect target directly without the WISPr fallback. They also tend to use HTTP probes that don't go through HSTS-locked hosts.

**Possible fixes (ordered by effort)**
1. **Add DHCP option 114** with the captive-portal URL (`http://192.168.4.1/`) in the SoftAP's DHCP server response. RFC 8910-compliant. Modern Windows / iOS / Android all parse this and use it as the captive landing URL. Requires extending `esp_netif`'s DHCP server to emit a non-standard option, which means dropping into lwip's `dhcp.c` or post-DHCPACK injection. Medium effort, 1-2 days.
2. **Embed WISPr v2 XML** in the captive-portal probe response body (alongside the existing 302). Older spec but still respected by Windows when it sees one. The XML response is small (~300 bytes). Easier than DHCP option 114. Half a day.
3. **Ship the demo with the workaround.** Document that the dev-PC user should bypass the captive notification and navigate to the URL manually. Phone path is the primary demo target anyway.

**Demo-day workaround:** if presenting from the dev PC, ignore the Windows captive notification, open a new tab in Chrome, and navigate to `http://192.168.4.1/` directly. Works around the issue without code changes. Phone demo (the more interesting one for a faculty advisor anyway) uses the captive sheet correctly.

### #4 — Brightness slider scale labels are decorative, not interactive

**Severity:** Low (polish — affordance-discoverability rather than blocking)
**Surfaces:** Webapp `#/` control page, brightness slider
**First observed:** Session 5 sub-4 closing UAT, 2026-04-29

**Symptom**
The 0/25/50/75/100 marks below the brightness slider are static labels — they look like they should be tap targets that snap the slider to that value (especially on mobile where precise dragging is hard), but clicking them does nothing. Misses an accessibility win for users with motor-control challenges or anyone using a phone screen.

**Hypothesized root cause**
The labels were added in Session 4 as visual reference for the four button-modality stops. They were never meant to be interactive. UX intuition has caught up with the implementation.

**Reproduction**
1. From the webapp on `#/`, look at the brightness slider's scale row.
2. Click any of the 0/25/50/75/100 labels.
3. Nothing happens.

**Possible fix**
Wrap each label in a `<button>` that calls `sendBrightness(value)` and styles to look like the existing label. ~15 minutes. Update `.brightness-marks` CSS to give the buttons hit areas while keeping the visual layout.

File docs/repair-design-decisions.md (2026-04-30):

---
title: Repair-Driven Design Decisions
type: hcde
phase: 2
week: 5
status: draft
tags: [hcde, repair, design-rationale, portfolio, decision-matrix]
---

# Repair-Driven Design Decisions

**Author:** William White
**Date:** April 30, 2026
**Status:** Draft — companion artifact to [right-to-repair-philosophy.md](right-to-repair-philosophy.md) and the [Failure_Modes/](../Failure_Modes/) inventory.

The [philosophy doc](right-to-repair-philosophy.md) states the repair *commitments*. The [failure mode inventory](../Failure_Modes/README.md) enumerates *what can break* and how the buyer fixes it. This doc closes the loop in the other direction: it walks through the **specific design decisions** made during v1.0 development and traces each one back to the repair value(s) it serves and the failure mode(s) it pre-empts. It is the portfolio artifact that proves repairability wasn't retrofitted onto the design — it shaped the design from the start.

The structure is deliberately a matrix rather than prose. Repair claims are easy to make in narrative form; harder to make in a table where every row has to terminate at a specific commitment, a specific failure mode, and a specific cross-link.

---

## 1. Repair values, defined

The matrix below cross-references each design decision against five repair values. They're listed here so the column abbreviations in §2 are unambiguous.

| Code | Value | One-line meaning |
|---|---|---|
| **R** | Reopenable | The product can be disassembled with standard tools, without destruction, indefinitely. |
| **C** | Commodity parts | Replacement parts are available from multiple independent suppliers — not gated by Layered Logic's warehouse. |
| **S** | Self-recovery | Common faults can be cleared by the owner without contacting Layered Logic. |
| **L** | Long service life | The decision actively extends the product's expected lifetime in service. |
| **O** | OTA-fixable | Software-side issues are correctable without anyone opening the enclosure. |

A decision can serve multiple values; the matrix marks each one that applies.

---

## 2. The decision matrix

Every row of this matrix terminates at: (a) a specific repair value, (b) a specific failure mode in [Failure_Modes/](../Failure_Modes/) it pre-empts, and (c) a cross-link to the spec or scoping doc where the decision is recorded.

| # | Decision | R | C | S | L | O | Failure mode pre-empted | Source |
|---|---|---|---|---|---|---|---|---|
| 1 | **Phillips-head fasteners only.** No proprietary bits, no glue, no ultrasonic welds. The enclosure opens with a tool every household owns. | ✓ |  | ✓ |  |  | All cases that require accessing internal components — see [solder joint](../Failure_Modes/wiring-solder-joint-failure.md), [PSU swap](../Failure_Modes/psu-no-output.md), etc. | [right-to-repair-philosophy §2](right-to-repair-philosophy.md) |
| 2 | **Friction-fit + screwed assembly, glued nowhere.** Every panel that joins another can be separated and rejoined without destroying either side. | ✓ |  | ✓ | ✓ |  | [Acrylic crack/scratch](../Failure_Modes/acrylic-crack-scratch.md), [frame physical damage](../Failure_Modes/frame-physical-damage.md) | [right-to-repair-philosophy §2](right-to-repair-philosophy.md), [LED Mirror Project Brief](../external_chats/LED_Mirror_Project_Brief.md) |
| 3 | **WS2812B 5M/60 commodity LED strip** (not a custom or proprietary lighting module). |  | ✓ |  |  |  | [LED dead pixel](../Failure_Modes/led-dead-pixel.md), [strip total failure](../Failure_Modes/led-strip-total-failure.md), [color degradation](../Failure_Modes/led-color-degradation.md) | [BOM breakdown](bom-breakdown-basic-6x6.md) |
| 4 | **5V barrel-jack PSU brick** (industry-standard plug, replaceable from any electronics retailer). |  | ✓ | ✓ |  |  | [PSU no output](../Failure_Modes/psu-no-output.md), [voltage instability](../Failure_Modes/psu-voltage-instability.md) | [BOM breakdown](bom-breakdown-basic-6x6.md), [sustainability-audit §2](sustainability-audit.md) |
| 5 | **PETG (printable) for all internal printed parts.** Owner can reprint from STL on request. The geometry is deliberately printable on consumer FDM, not just industrial machines. | ✓ | ✓ | ✓ |  |  | [PETG breakage](../Failure_Modes/petg-breakage.md) | [right-to-repair-philosophy §3](right-to-repair-philosophy.md), [LED Mirror Project Brief](../external_chats/LED_Mirror_Project_Brief.md) |
| 6 | **Replaceable controller module** (the ESP32-C3 sits on a separate PCB module rather than being embedded in the main board). | ✓ | ✓ | ✓ |  |  | [Controller hardware failure](../Failure_Modes/controller-hardware-failure.md), [Wi-Fi failure](../Failure_Modes/controller-wifi-failure.md) | [firmware-architecture-scoping §6](firmware-architecture-scoping.md) |
| 7 | **OTA firmware updates with self-hosted infrastructure** (`ota.layeredlogic.cc`, Cloudflare Worker + R2). Software bugs ship as binary updates that arrive without any owner action. |  |  |  | ✓ | ✓ | [Firmware corruption](../Failure_Modes/controller-firmware-corruption.md), all classes of post-ship software regression | [firmware-architecture-scoping §5.4](firmware-architecture-scoping.md), [firmware-security.md](firmware-security.md) |
| 8 | **Self-hosted OTA on `ota.layeredlogic.cc`** (not on a third-party platform). Software updates remain available even if a third-party vendor goes EOL. |  |  |  | ✓ | ✓ | Indirect: protects against supply-chain shutdown of update infrastructure | [firmware-security.md](firmware-security.md), [reference_domain_layeredlogic memory](../../../.claude/projects/C--Users-bowhi-Desktop-Independent-Study/memory/reference_domain_layeredlogic.md) |
| 9 | **NVS-stored settings** (Wi-Fi creds, color, pattern, brightness). State persists across reboots; a power cut doesn't strand the owner in setup mode. |  |  | ✓ | ✓ |  | [NVS data loss](../Failure_Modes/controller-nvs-corruption.md) (handled gracefully — first-boot defaults restore device to a usable state) | [firmware-spec.md](firmware-spec.md), [project_firmware_status memory](../../../.claude/projects/C--Users-bowhi-Desktop-Independent-Study/memory/project_firmware_status.md) |
| 10 | **Recessed factory-reset button.** Owner can clear bricked Wi-Fi state, paired credentials, or stale settings without contacting Layered Logic. |  |  | ✓ |  |  | [Wi-Fi failure](../Failure_Modes/controller-wifi-failure.md), [NVS corruption](../Failure_Modes/controller-nvs-corruption.md), provisioning-loop edge cases | [button-interface §3](button-interface.md), [button-design-rationale §3](button-design-rationale.md) |
| 11 | **App-driven provisioning + control** (no firmware-flashing for setup or daily use). |  |  | ✓ | ✓ | ✓ | Stale firmware bugs that would otherwise require user-facing flashing | [App spec](app-spec.md), [webapp-spec.md](webapp-spec.md) |
| 12 | **Reflash service for dead controllers** (cost-of-shipping, not a paid repair). The closed-binary firmware is the philosophy doc's [§4 honest limit](right-to-repair-philosophy.md#4-the-honest-limits) — this is the mitigation. |  |  | ✓ | ✓ |  | Replacement controllers shipped without firmware can be made functional via the reflash service | [right-to-repair-philosophy §4](right-to-repair-philosophy.md) |
| 13 | **Versioned PCB silkscreen** — every shipped board carries its revision letter visibly. An owner reading a schematic can match it to their physical board. | ✓ |  | ✓ |  |  | All controller-side failure modes that require schematic reference | [right-to-repair-philosophy §3](right-to-repair-philosophy.md) |
| 14 | **STL files supplied on request** for any owner reporting a printable-part repair need. Not published by default — service-driven distribution. |  | ✓ | ✓ |  |  | [PETG breakage](../Failure_Modes/petg-breakage.md), edge cases involving custom modifications | [right-to-repair-philosophy §3](right-to-repair-philosophy.md) |
| 15 | **Public schematic references on GitHub** (per-revision folder). Anyone can read along with the design that's inside their unit. | ✓ |  |  | ✓ |  | Indirect: enables independent repair by hobbyists or repair shops | [right-to-repair-philosophy §3](right-to-repair-philosophy.md) |
| 16 | **7-year minimum replacement-part availability** for the PCB and controller module. Commodity parts (LED strip, PSU, screws, acrylic) outlive this on their own. |  | ✓ |  | ✓ |  | All controller-side failures across the documented service window | [right-to-repair-philosophy §3](right-to-repair-philosophy.md) |
| 17 | **No bonded enclosure.** Acrylic panels sit in milled channels, not adhesive. Replaceable as separate parts. | ✓ |  | ✓ | ✓ |  | [Acrylic crack/scratch](../Failure_Modes/acrylic-crack-scratch.md), [coating degradation](../Failure_Modes/acrylic-coating-degradation.md) | [LED Mirror Project Brief](../external_chats/LED_Mirror_Project_Brief.md), [sustainability-audit §2](sustainability-audit.md) |
| 18 | **Open-mode auth as the default.** Roommates and guests can use the mirror without authentication friction; reduces "I can't control my own light" support burden. |  |  | ✓ |  |  | Pairing-state edge cases that would otherwise need a factory reset | [firmware-security.md](firmware-security.md) |
| 19 | **Three-tier product line shares a common firmware core.** Basic (STM8), Pro (ESP32), Pro+ (ESP32 + Matter) all draw from `Firmware/v1/core/`. A bug fix on one tier benefits all tiers. |  |  |  | ✓ | ✓ | Indirect: amortizes the maintenance burden across the product line | [firmware-architecture-scoping §6](firmware-architecture-scoping.md) |
| 20 | **LED strip pre-tested at receiving** before the build. Catches DOA strips before they enter the unit; reduces field-failure rate. |  |  |  | ✓ |  | [LED total failure](../Failure_Modes/led-strip-total-failure.md) (frequency reduction, not elimination) | [Assembly_docs/LED_Mirror_Project_Brief](../Assembly_docs/LED_Mirror_Project_Brief.md) |

---

## 3. Reading the matrix

A few patterns the matrix surfaces, none of which are coincidence:

- **Every controller-side failure mode terminates at either a self-recovery path (recessed button, OTA) or a swap path (replaceable module, reflash service).** No controller failure requires Layered Logic to physically touch the unit; either the owner clears it, the OTA fixes it, or a board ships out and back. This is the fundamental architectural decision behind the closed-binary acknowledgement in [philosophy §4](right-to-repair-philosophy.md#4-the-honest-limits) — the binary is closed, but its consequences are not stranded.
- **Commodity parts dominate the BOM.** Of the 17 enumerated failure modes in the [inventory](../Failure_Modes/README.md), 14 are resolved by parts available from multiple independent suppliers — i.e., the buyer's repair path doesn't depend on Layered Logic continuing to exist. The 3 that do depend on Layered Logic (the PCB, the controller module, and the firmware reflash service) are exactly the cases where [§4 of the philosophy](right-to-repair-philosophy.md#4-the-honest-limits) names the dependency explicitly.
- **OTA-fixability protects against the failure mode that doesn't appear in the inventory: bugs I haven't shipped yet.** A static enumeration of failure modes is a snapshot; software regressions that arrive after ship are continuous. OTA is the design lever that keeps post-ship surface area small.
- **Long-service-life value (L) clusters around decisions that make the product *adaptive*, not just *durable*.** Reprintable parts, replaceable modules, OTA-updatable firmware, schematic availability — these don't reduce wear, they reduce the cost of recovery from wear. The product is designed to outlive its components by replacing them, not to outlive its components by lasting forever.

---

## 4. What this matrix doesn't cover

For honesty, the categories of decision this doc deliberately leaves out:

- **Cost-driven decisions** that don't terminate at a repair value. The matrix is filtered to entries where repair was a *driver*, not a side effect.
- **The user-facing repair guide itself** — that's a separate Week 8 deliverable, blocked on the assembly guide.
- **Quantitative assessment** of how the decisions perform in practice. That's the [repairability scorecard](repairability-scorecard.md).
- **End-of-life paths** other than repair. The acrylic-coating recyclability gap is documented in [sustainability-audit §7](sustainability-audit.md) — it's a stated limit of the philosophy, not a design decision this doc claims credit for solving.

---

## Related

- [Right-to-Repair Philosophy](right-to-repair-philosophy.md) — the values framework this matrix substantiates
- [Failure Mode Inventory](../Failure_Modes/README.md) — every cell in the "Failure mode pre-empted" column links here
- [Repairability Scorecard](repairability-scorecard.md) — quantitative companion
- [Repair Index](repair-index.md) — entry point for the repair-ecosystem docs
- [Sustainability Audit](sustainability-audit.md) — lifecycle context, including the EOL gap that bounds the philosophy
- [Brand Positioning](brand-positioning.md) — "Living" adjective that this matrix operationalizes
- [Button Design Rationale](button-design-rationale.md) — paired-format companion (button-side decisions; this doc covers repair-side decisions)
- [Sprint Plan](../sprint_plan.md) — Week 4 deliverables, Week 8 follow-ups

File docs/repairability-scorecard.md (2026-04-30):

---
title: Repairability Scorecard — Infinity Mirror v1.0
type: hcde
phase: 2
week: 5
status: draft
tags: [hcde, repair, scorecard, metrics, portfolio]
---

# Repairability Scorecard — Infinity Mirror v1.0

**Author:** William White
**Date:** April 30, 2026
**Status:** Draft — quantitative companion to [right-to-repair-philosophy.md](right-to-repair-philosophy.md). Several cells use placeholder values pending measurement on the golden sample; flagged with **TBD** and an estimation source.

---

## 1. Top-line numbers

Pulled from the [failure mode inventory](../Failure_Modes/README.md) and the [BOM breakdown](bom-breakdown-basic-6x6.md):

| Metric | Value | Source |
|---|---|---|
| Failure modes enumerated | **17** | [Failure_Modes/](../Failure_Modes/) — counted across 8 component categories |
| Fully user-repairable | **12 (71%)** | [Failure_Modes/README.md §Summary](../Failure_Modes/README.md) |
| Partially user-repairable (needs soldering or LL involvement) | **5 (29%)** | same |
| Non-repairable | **0** | same |
| Component classes that are 100% commodity-sourceable | **6 of 8** (LED strip, PSU, screws, acrylic, wood frame, wiring) | [BOM breakdown](bom-breakdown-basic-6x6.md) |
| Component classes that depend on Layered Logic | **2 of 8** (PCB, controller firmware) | [right-to-repair-philosophy §4](right-to-repair-philosophy.md#4-the-honest-limits) |
| Tools required for full disassembly | **1** (Phillips screwdriver) | [right-to-repair-philosophy §2](right-to-repair-philosophy.md) |
| Replacement-part availability commitment | **7 years from ship date** | [right-to-repair-philosophy §3](right-to-repair-philosophy.md) |

---

## 2. Per-failure-mode scorecard

The 17 modes from [Failure_Modes/](../Failure_Modes/) scored on five axes. Repair time is wall-clock end-to-end, including disassembly, replacement, and reassembly — **TBD** values are estimates pending golden-sample measurement.

| Failure mode | Severity | Repair tier | Tools | Parts source | Est. repair time |
|---|---|---|---|---|---|
| [LED dead pixel](../Failure_Modes/led-dead-pixel.md) | Low | User | Phillips, soldering iron | Commodity (WS2812B 5M/60) | **TBD ~25 min** (estimate) |
| [LED strip total failure](../Failure_Modes/led-strip-total-failure.md) | High | User | Phillips, soldering iron | Commodity | **TBD ~40 min** (estimate; covers full-strip swap on a 6×6) |
| [LED color degradation](../Failure_Modes/led-color-degradation.md) | Low | User | Phillips, soldering iron | Commodity | **TBD ~40 min** (treats as full strip replacement) |
| [PSU no output](../Failure_Modes/psu-no-output.md) | Critical | User | None | Commodity (5V barrel-jack) | **TBD ~2 min** (unplug + plug) |
| [PSU voltage instability](../Failure_Modes/psu-voltage-instability.md) | Medium | User | None | Commodity | **TBD ~2 min** |
| [Controller hardware failure](../Failure_Modes/controller-hardware-failure.md) | High | Partial — needs LL reflash | Phillips | LL (controller module) + commodity | **TBD ~15 min user-side, plus ship round-trip** |
| [Controller firmware corruption](../Failure_Modes/controller-firmware-corruption.md) | High | Partial — OTA-resolvable in most cases | None (OTA) or Phillips + LL reflash | LL (firmware) | OTA: < 5 min unattended. Reflash: ship round-trip |
| [Wi-Fi connectivity loss](../Failure_Modes/controller-wifi-failure.md) | Medium | User | None | None (recovery path only) | **TBD ~3 min** (recessed-button factory reset + re-pair) |
| [NVS data loss](../Failure_Modes/controller-nvs-corruption.md) | Low | User | None | None (graceful default) | < 1 min (auto-recovery on next boot) |
| [Acrylic crack/scratch](../Failure_Modes/acrylic-crack-scratch.md) | Medium | User | Phillips | Commodity (cut to spec) or LL replacement panel | **TBD ~20 min** + acquisition lead time |
| [Acrylic coating degradation](../Failure_Modes/acrylic-coating-degradation.md) | Low | User | Phillips | LL or specialty supplier | **TBD ~20 min** + lead time |
| [Frame physical damage](../Failure_Modes/frame-physical-damage.md) | Low | User | Phillips, woodworking tools | Commodity (1×2 hardwood, milled) or LL reorder | Variable — **TBD** depending on damage extent |
| [PETG breakage](../Failure_Modes/petg-breakage.md) | Low | User | Phillips, FDM printer | Commodity (filament) + LL STL on request | **TBD ~30 min** + print time (~1–3 hr per part) |
| [Solder joint failure](../Failure_Modes/wiring-solder-joint-failure.md) | Medium | Partial — soldering required | Phillips, soldering iron | None (re-flow existing) | **TBD ~15 min** |
| [Barrel jack intermittent](../Failure_Modes/barrel-jack-intermittent.md) | Medium | User | Phillips, soldering iron (sometimes) | Commodity (panel-mount jack) | **TBD ~20 min** |
| [Primary button unresponsive](../Failure_Modes/button-primary-failure.md) | Medium | Partial — soldering required | Phillips, soldering iron | LL (PCB-mount switch) | **TBD ~25 min** |
| [Recessed button unresponsive](../Failure_Modes/button-recessed-failure.md) | Medium | Partial — soldering required | Phillips, soldering iron | LL (PCB-mount switch) | **TBD ~25 min** |

---

## 3. Tooling accessibility

Distribution of repairs by required tooling — proxy for "how technical does the buyer need to be":

| Tools required | Count | % of failure modes | Examples |
|---|---|---|---|
| **No tools at all** | 4 | 24% | PSU swap, Wi-Fi reset, NVS auto-recovery, OTA |
| **Phillips only** | 0 | 0% | (Phillips alone doesn't resolve any failure mode without an inner action; tracking for completeness) |
| **Phillips + acquisition** | 4 | 24% | Acrylic panel swap, frame replacement, controller module swap, PETG reprint |
| **Phillips + soldering iron** | 9 | 53% | All LED-strip and PCB-side electrical repairs |
| Specialty equipment | 0 | 0% | None require equipment beyond a standard hobbyist electronics bench |

The soldering-iron threshold is the main accessibility line. **TBD: target measurement** — what fraction of buyers in the target audience are comfortable soldering, vs. comfortable shipping the unit back for service. The reflash-service pathway and the "send the controller module to LL for replacement" pathway exist precisely because soldering-comfort is not universal.

---

## 4. Parts independence

Counted as: of the parts needed to complete each repair, how many depend on Layered Logic continuing to operate?

| Independence tier | Count | Examples |
|---|---|---|
| **Fully independent** (commodity parts only — buyer can source from any electronics retailer or hardware store) | 12 | LED strip, PSU, barrel jack, screws, frame wood, acrylic panel (cut to spec), filament for PETG reprints |
| **STL-on-request** (LL provides file, buyer prints) | 1 | PETG breakage |
| **LL-supplied part** (LL ships a replacement) | 4 | PCB, controller module, custom replacement acrylic, custom-cut frame from original supplier |
| **LL-supplied service** (LL performs the work) | 1 | Firmware reflash |

The 5 LL-dependent paths are exactly what [philosophy §4](right-to-repair-philosophy.md#4-the-honest-limits) and the [§3 commitments](right-to-repair-philosophy.md#3-what-i-commit-to) name explicitly. The 7-year availability commitment is the contractual mitigation; the public schematic publication and the architecture-generic PCB design are the long-tail mitigations against LL-shutdown risk.

---

## 5. Comparative context

Repairability scores from comparable consumer-LED products. **TBD: source these from public iFixit teardowns, manufacturer disclosures, or the EU Right-to-Repair scoring framework as it phases in through 2026–2027.** Categories below are placeholders illustrating the framework — replace with real data before publishing externally.

| Product class | Tools to access | Common failure path | Replacement availability | Repair-friendly? |
|---|---|---|---|---|
| **LL Infinity Mirror v1.0** | Phillips screwdriver | User-serviceable for 12 of 17 modes | 7-year LL commitment + commodity supply | Yes by design |
| Mass-market LED art (Etsy / Amazon, $50–120 segment) | **TBD** | **TBD** — typically replace-the-whole-unit | **TBD** — typically none | **TBD** |
| Mid-tier sensory-therapy LED ($230–4,300) | **TBD** | **TBD** | **TBD** | **TBD** |
| Smart-home lighting (Hue / Nanoleaf) | Often non-opening (glued) | Replace whole unit | Vendor-controlled, multi-year | Typically not by design |

The above table is the most explicitly TBD section of this scorecard — comparative data needs sourcing before the scorecard is portfolio-final. The framework is right; the cells need filling.

---

## 6. Lifetime carbon implications

From [sustainability-audit.md](sustainability-audit.md) §6 (Repairability) and §7 (End-of-life): the v1.0 unit's embodied carbon is ~2.5–2.7 kg CO₂ cradle-to-door. Repairable design extends the in-service window — every additional year a unit stays in service amortizes that embodied carbon over a longer use phase. The [LED strip's 14+ year service life](sustainability-audit.md) is the longest-tenured component; the expected dominant constraint is one of the partially-repairable PCB-side failure modes.

| Hypothetical timeline | Embodied carbon amortization | Notes |
|---|---|---|
| 1 year (worst case — early controller failure, owner doesn't pursue repair) | ~2.5 kg CO₂ / yr | Repair philosophy specifically designed to prevent this scenario |
| 7 years (LL replacement-availability floor) | ~0.36 kg CO₂ / yr | Aligns with §3 commitment window |
| 14 years (LED service life ceiling) | ~0.18 kg CO₂ / yr | Implies all electronic components have been replaced at least once during service |

These figures are from the audit and are the most direct answer to "why repair *matters*" beyond the values argument.

---

## 7. Open methodology questions

Items the scorecard would benefit from once the golden sample is built:

- **Stopwatch the actual repair times** for each documented failure mode on a real unit. Replace every **TBD** repair-time estimate with measured data.
- **Soldering-required repairs** could be revisited if the v2 PCB uses a swappable connector for the LED strip rather than direct solder pads. That alone would push 3 modes from "Partial" to "User" tier.
- **Comparative repairability data** — see §5. Sourcing options: iFixit teardowns where available, EU scoring once disclosure rules ship, manufacturer warranty terms as proxy.
- **Publish the scorecard with each unit shipment** as a sticker-style summary card? Open question on whether this is over-promising. Tabling pending Week 7 service-blueprint work on the unboxing flow.

---

## Related

- [Right-to-Repair Philosophy](right-to-repair-philosophy.md) — the values doc this scorecard quantifies
- [Failure Mode Inventory](../Failure_Modes/README.md) — every row in §2 sources from a file here
- [Repair-Driven Design Decisions](repair-design-decisions.md) — how the design was shaped by the repair values measured here
- [Repair Index](repair-index.md) — entry point for the repair-ecosystem docs
- [Sustainability Audit](sustainability-audit.md) — lifecycle data behind §6
- [BOM Breakdown](bom-breakdown-basic-6x6.md) — component-source data behind §4
- [Sprint Plan](../sprint_plan.md) — Week 4 / Week 8 deliverable arc

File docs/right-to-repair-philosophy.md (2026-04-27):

---
title: Right-to-Repair Philosophy
type: hcde-artifact
phase: 2
week: 4
date: 2026-04-20
status: complete
tags: [hcde, repair, philosophy, values]
---

# Right-to-Repair Philosophy

**Prepared by:** William White, Founder — Layered Logic LLC
**Date:** April 20, 2026
**Status:** Complete — Week 4 deliverable

---

## 0. The Principle

I design products to be opened, repaired, and kept.

That's the whole philosophy in one sentence. The rest of this document says *why*, what the commitment specifically covers, and where its honest limits are. The User Repair Guide (in development) is the practical companion — this doc is the reasoning behind it.

---

## 1. Why

Three reasons, ordered by how much they actually drive my decisions.

### The first is pro-consumer conviction.

When someone pays for something I made, that's the beginning of the relationship — not the end of the transaction. A product that can't be opened is a product that tells its owner "this was never really yours." I'd rather make fewer units that people keep for a decade than more units that pile up in closets waiting for the landfill.

This is the posture I want the brand to have by default: buying is joining, not consuming. Repair is a form of respect — for the buyer's money, for their time, for the materials that went into the thing, and for the idea that good objects should be lived with, not rotated out.

### The second is environmental honesty.

The single biggest lever on a product's lifetime carbon is how long it stays in service. Everything else — recycled packaging, efficient PSUs, right-sized components — is secondary to simply keeping the object in use.

The [Sustainability Audit](sustainability-audit.md) puts the numbers on this: the LED strip has a 14+ year service life at worst-case usage, and the electronics fabrication locks in the largest share of the product's embodied carbon at the moment it's built. That carbon is already spent. The environmentally coherent move after that is to keep the unit working for as long as physically possible — and to make sure every failure mode is a repair event, not an end-of-life event.

A product designed to be repaired is a product designed to be *kept*. That connects back to **Living** as a brand adjective — the mirror isn't a static object that decays on a schedule. It's a system that can be updated, refreshed, and carried forward.

### The third is that the law is arriving.

The EU Right-to-Repair Directive, the Washington and California state bills tracking alongside it, and similar legislation in other major markets are all converging on the same requirement: electronics must be repairable using standard tools and parts for 7–10 years from date of sale. Sealed-unit products are becoming illegal to sell in the markets I want to sell into.

I'm listing this third on purpose. The legal argument reinforces the values argument, but if the law were my only reason I'd be doing the minimum and calling it compliance. I'd rather build a product that *would have been* repairable even if nobody was watching — and then discover that the regulators happen to agree.

---

## 2. What Repair Means Here

Concretely, for the v1.0 infinity mirror:

- **The product opens with standard tools.** Philips-head screwdriver. No proprietary bits, no glued enclosures, no ultrasonic-welded clamshells, no destructive entry.
- **Every failure mode I can imagine has a user-serviceable path.** LED burns out → replace the strip (commodity WS2812B 5M/60, stocked by every electronics supplier). Controller dies → swap the module. PSU fails → replace the 5V barrel-jack brick from any supplier. Enclosure cracks → reprint the PETG part from the STL I ship with every unit.
- **Firmware is updateable without opening the product.** Over-the-air updates mean a software fix never requires hardware work. Bugs I ship in 2026 can be fixed in 2030 without anyone touching a screwdriver.
- **Nothing is bonded that doesn't need to be.** Friction-fit where possible, screwed where necessary, glued nowhere. If a future owner needs to swap a component, the object cooperates.
- **Parts stay findable.** Every component in the BOM is either a commodity (available from dozens of suppliers) or a printable file (available from me). "Available" here doesn't depend on my warehouse alone — the ecosystem is the supply chain.

---

## 3. What I Commit To

As long as I'm the one building these, these are the commitments the buyer can hold me to:

- I will publish the User Repair Guide as a standalone document — not as a buried FAQ entry, not hidden behind an account wall.
- I will supply STL files on request to any owner reporting a specific repair need. They're not published by default — the commitment is to service, not to free distribution — but no one with a cracked enclosure will be turned away from the file to reprint it.
- I will publish schematic references for each shipped PCB revision in a public GitHub folder, updated as revisions ship. Anyone wanting to understand what's inside the box can read along.
- I will version every physical PCB clearly, with the revision letter on the silkscreen and visible when the enclosure is opened. An owner and I should always be able to line up the board in their hand with the schematic they're reading.
- I will maintain OTA firmware update support for the life of each unit, so software-side issues get fixed without the owner ever needing to flash anything themselves.
- I will answer repair questions directly. While I'm the assembler, I'm also the support line — there is no handoff between who built it and who helps fix it.
- I will honor the warranty by repair first, replacement second, refund third — not as a dodge, but because repair is the option most aligned with the values of the product.
- I will maintain replacement-part availability for a minimum of **7 years from ship date**, aligned with the floor emerging in right-to-repair legislation. In practice, commodity parts (LED strips, PSUs, screws, acrylic) will outlive that window on their own. The commitment is meaningful mainly for the PCB and controller module.

---

## 4. The Honest Limits

A philosophy doc is only useful if it states what it *doesn't* promise.

- **The acrylic mirror panels cannot be recycled as pure PMMA.** The vacuum-deposited metallic coating disqualifies them from standard PMMA recycling streams. At ~166g per unit, this is the product's largest end-of-life gap, and I'm not going to pretend otherwise. [Full analysis in Sustainability Audit §7.] Glass panels are on the v2 investigation list, along with a possible panel take-back program for custom units.
- **I can't guarantee the exact ESP32 module will be manufacturable in ten years.** Espressif's roadmap is theirs, not mine. If the C3-MINI-1 goes end-of-life, I will document the pin-compatible successor and publish an updated PCB footprint — but that's a best-effort commitment, not an absolute one. What I *can* guarantee is that *some* module will be able to drive the LEDs; the architecture is deliberately generic.
- **The firmware is a closed binary.** This is the one place where the philosophy and a business decision don't fully agree, and I'd rather name the tension than paper over it. The hardware is documented enough — schematic, BOM, versioned PCBs, STLs on request — that the circuit is in principle reproducible. The firmware is not. In practice this means a bare replacement board has to come through me to be flashed; an owner can rebuild the hardware around a dead controller but can't boot a blank one without my help. What I commit to instead is: **a reflash service** for the cost of shipping, and **ongoing OTA updates** so software issues never require opening the product. This is a position I'm willing to revisit as the business evolves — including the question of firmware escrow if I ever discontinue the product line or shutter the business.
- **I am one person.** The support response time is "a human who built your mirror, replying when they can" — not a 24/7 helpdesk. That's a feature until the day the volume grows past what one person can hold, at which point the commitment transitions with the brand. First-person "I" becomes first-person plural "we" only when the person on the other end of an email actually changes.

---

## 5. Compliance as Reinforcement

The relevant legislation at time of writing:

- **EU Right-to-Repair Directive** — adopted 2024, phasing into national law across member states through 2026–2027. Mandates repair information, spare parts availability, and standard-tool repair for covered electronics.
- **Washington HB-1933** and **California SB-244** — state-level analogues of the EU framework, both in force or phasing in, mandating repair access for consumer electronics sold in-state.
- **Emerging FTC guidance** on warranty tying and repair-restriction practices.

The v1.0 infinity mirror, as designed, already meets the repairability requirements in all three. This is not a retrofit. It's what happens when the values and the design brief agree with each other from the start.

I note this here for completeness — compliance matters, and the legal ceiling will only rise from here — but the commitments in §3 are not downstream of legislation. They'd be the commitments regardless.

---

## 6. What This Asks Of The Buyer

Two things, neither of them large:

- **Before you throw it out, ask me.** I'd rather fix it than replace it, and I'd rather replace it than see it in a landfill. The email address that sold it to you is the same one that can still help.
- **Don't seal it shut.** Every modification the enclosure allows is one I want you to make — mount it differently, swap the LEDs for a different density, print a variant frame. But please leave it reopenable. That's the whole point.

The buyer reaches this document through a QR code laser-etched (or perforated) into the outer cardboard, produced in the same cutting pass that forms the folded box. Zero extra material, and the path to the repair philosophy is the same piece of cardboard the owner would otherwise throw away. Repair promises that only live on a marketing page are easy to miss; repair promises on the box are not.

---

## 7. Why This Is A Document

Repair commitments are easy to claim in marketing copy and easy to walk back when they get expensive. Writing the reasoning down — publicly, in first-person, with the limitations stated alongside the promises — is what makes the commitment real.

This document is the version of the argument that gets tested when something does go wrong and a specific buyer emails me about a specific broken mirror. If what I do in that moment doesn't match what's written here, the document is wrong — and I'd rather rewrite the document to match reality than let the two drift apart quietly.

So: if you're holding one of these mirrors and something on this page reads as aspirational rather than real, tell me. That's the only way it stays honest.

---

## Related

- [Brand Positioning](brand-positioning.md) — voice and values this doc inherits (§4 voice, §3 "Living" adjective)
- [Sustainability Audit](sustainability-audit.md) — lifecycle evidence behind the repair claims (Stage 6)
- [Market Analysis Report](Market%20Analysis%20Report.md) — regulatory context (§3.E Repairability Liability)
- [Stakeholder Map](stakeholder-map.md) — end-of-life and repair stakeholders this philosophy is written for
- [Firmware Architecture Scoping](firmware-architecture-scoping.md) — where the closed-binary + self-hosted OTA + reflash-service commitments get technical definition
- [Failure Mode Inventory](../Failure_Modes/) — individual failure mode analyses for every v1.0 component, with repair paths and parts sourcing
- User Repair Guide *(pending — Week 4 → Week 8 final)* — the practical how-to companion
- [Sprint Plan](../sprint_plan.md) — Week 4 deliverables

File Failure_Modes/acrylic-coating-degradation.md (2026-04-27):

---
title: "Acrylic Panel — Coating Degradation"
type: failure-mode
component: acrylic-panel
severity: low
probability: very-low
user-repairable: yes
tags: [failure-mode, acrylic, mirror, coating, aging]
---

# Acrylic Panel — Coating Degradation

The vacuum-deposited metallic coating on the acrylic mirror panel degrades over time — clouding, hazing, or developing spots that reduce the infinity mirror effect.

---

## Symptoms

- The mirror surface looks hazy or cloudy compared to when it was new.
- Small spots or patches where the reflective coating has worn away, creating dark areas in the infinity tunnel.
- The infinity depth effect is weaker — fewer visible "layers" of reflection.
- Discoloration or yellowing of the reflective surface.

## Likely Causes

- **UV exposure** — direct sunlight on the mirror face degrades the metallic coating over years. UV also yellows the acrylic substrate.
- **Chemical exposure** — cleaning with ammonia-based products (Windex), alcohol, or abrasive cleaners strips the coating. Standard glass cleaner is the enemy here.
- **Moisture** — extended exposure to high humidity (bathroom placement without ventilation) can cause the coating to delaminate at the edges.
- **Abrasion** — wiping with rough cloths or paper towels scratches through the thin coating layer.

## Probability

**Very low under normal conditions.** The panels are protected inside the wood frame (edges sealed from moisture), and the coating faces inward (away from direct contact). This failure mode requires years of UV exposure or improper cleaning. Indoor placement away from direct sunlight makes this a decade-plus concern.

## Repair Path

Same as [Acrylic Panel — Crack or Scratch](acrylic-crack-scratch.md) — panel replacement.

1. Unplug, open back panel, remove LED spacer.
2. Slide out the degraded panel.
3. Slide in a replacement panel (reflective coating facing the LED cavity).
4. Reassemble.

### Tools Required

- Phillips-head screwdriver

### Parts Required

- **1-way or 2-way mirror acrylic, 150mm × 150mm × 3.1mm** — same sourcing as [Crack or Scratch](acrylic-crack-scratch.md). ~$2.50–$5.00 per panel.

### Estimated Difficulty

Moderate.

### Estimated Time

20–30 minutes.

## When to Contact Support

- Same as crack/scratch — if you need pre-cut panels or aren't sure which panel is affected.

## Design Mitigations

- **Coating faces inward** — the reflective surface is on the interior of the cavity, protected from direct contact, cleaning, and UV exposure.
- **Wood frame edges** — frame channels shelter the panel edges from moisture ingress.
- **Care instructions** — packaging includes a note: clean the front surface with a soft microfiber cloth and water only. No ammonia, no alcohol, no paper towels.

### Preventive Care

- Place the mirror away from direct sunlight.
- Clean only with a soft microfiber cloth, lightly dampened with water.
- Never use glass cleaner, alcohol, or abrasive products on the mirror surface.
- Avoid bathroom placement unless the room has good ventilation.

---

## Related

- [Acrylic Panel — Crack or Scratch](acrylic-crack-scratch.md) — physical damage vs. chemical/aging degradation
- [Right-to-Repair Philosophy](../docs/right-to-repair-philosophy.md) — §4 acrylic EOL limitations
- [Sustainability Audit](../docs/sustainability-audit.md) — §7 acrylic recycling gap

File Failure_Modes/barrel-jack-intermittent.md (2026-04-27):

---
title: "Barrel Jack — Intermittent Connection"
type: failure-mode
component: power-connector
severity: medium
probability: low
user-repairable: yes
tags: [failure-mode, barrel-jack, power, connector]
---

# Barrel Jack — Intermittent Connection

The DC barrel jack connector on the mirror has a loose or intermittent connection — the mirror flickers, resets, or loses power when the cable is bumped.

---

## Symptoms

- Mirror cuts out momentarily when the DC cable is touched or moved.
- The mirror reboots (flashes default color briefly) when the cable is jiggled — this is a power-cycle reboot.
- Power works only when the plug is held at a specific angle.
- Flickering that correlates with cable movement (as opposed to [PSU — Voltage Instability](psu-voltage-instability.md), which is independent of cable position).

## Likely Causes

- **Worn barrel jack socket** — the spring contacts inside the socket have relaxed from repeated plug/unplug cycles. The plug no longer seats firmly.
- **Bent center pin** — the PSU plug's center pin is slightly bent, making inconsistent contact with the socket's center conductor.
- **Solder joint failure at the socket** — the barrel jack socket's leads have cracked where they're soldered to the PCB or wiring. See [Wiring — Solder Joint Failure](wiring-solder-joint-failure.md).
- **Damaged cable** — the DC cable from the PSU has an internal break near the plug, making contact intermittent.

## Probability

**Low.** The barrel jack is a robust connector, and the mirror is typically plugged in once and left — not repeatedly connected and disconnected. This failure mode is more likely if the mirror is frequently moved or if the cable is stressed (routed at a sharp angle, pulled taut, or stepped on).

## Repair Path

### Step 1: Check the PSU plug

1. Inspect the PSU's barrel plug — is the center pin straight? Is the plug visibly damaged?
2. Try a different 5V PSU with a matching barrel plug. If the issue goes away, the problem is the PSU cable, not the mirror's socket. Replace the PSU per [PSU — No Output](psu-no-output.md).

### Step 2: Check the socket (if the PSU plug is fine)

1. Unplug from power.
2. Open the back panel (Phillips-head screws).
3. Inspect the barrel jack socket:
   - Check the solder joints where the socket connects to the board or wiring. Reflow if they look cracked or dull.
   - Gently wiggle the socket — it should be solidly mounted with no play.
4. If the socket's internal spring contacts are worn, replace the socket.

### Socket replacement:

1. Desolder the old barrel jack socket.
2. Solder in a replacement (standard 5.5mm × 2.1mm panel-mount or PCB-mount barrel jack socket).
3. Test with the PSU plugged in — verify solid connection with no intermittent behavior.

### Tools Required

- Phillips-head screwdriver
- Soldering iron + solder (for joint reflow or socket replacement)
- (Optional) Multimeter for continuity testing

### Parts Required

- **5.5mm × 2.1mm DC barrel jack socket** — commodity part, under $1. Available from Amazon, DigiKey, Mouser, or AliExpress.
- Or just replace the PSU if the issue is the plug side — see [PSU — No Output](psu-no-output.md).

### Estimated Difficulty

Easy (PSU replacement) to Moderate (socket reflow/replacement).

### Estimated Time

Under 1 minute (PSU swap) to 15–20 minutes (socket replacement).

## When to Contact Support

- If you're not comfortable with soldering.
- If the socket replacement doesn't fix the issue — the problem may be deeper in the power path (PCB trace, regulator, etc.).

## Design Mitigations

- **Standard connector** — 5.5mm × 2.1mm barrel jack is the most common DC power connector. Sockets and plugs are universally available.
- **External PSU** — the connector is on the mirror's enclosure, accessible without full disassembly.
- **Strain relief** — cable routing inside the enclosure includes a strain relief point so cable tugs stress the relief, not the solder joint.

---

## Related

- [PSU — No Output](psu-no-output.md) — if the issue is the PSU, not the connector
- [PSU — Voltage Instability](psu-voltage-instability.md) — if flickering is independent of cable movement
- [Wiring — Solder Joint Failure](wiring-solder-joint-failure.md) — if the socket's solder connection is the problem

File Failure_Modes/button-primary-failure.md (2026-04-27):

---
title: "Button — Primary Unresponsive"
type: failure-mode
component: button
severity: medium
probability: very-low
user-repairable: partial
tags: [failure-mode, button, input, gpio]
---

# Button — Primary Unresponsive

The main exposed button stops registering presses — single, double, triple, and hold gestures all produce no response.

---

## Symptoms

- Pressing the primary button does nothing — no color change, no pattern change, no on/off.
- The mirror continues running its current pattern and color normally (if it was on) — just can't be controlled.
- (ESP32 variant) The mirror still responds to app commands over WebSocket — only the physical button is dead.
- The recessed button still works (if applicable).

## Likely Causes

- **Button switch failure** — the tactile switch has worn out or its internal contact has failed. Typical tactile switches are rated for 100,000–1,000,000 cycles. At normal use (10–20 presses/day), this is years to decades of life.
- **Solder joint failure at the button** — the button's leads have cracked loose from the PCB. See [Wiring — Solder Joint Failure](wiring-solder-joint-failure.md).
- **GPIO failure on the MCU** — the input pin (GPIO9) has been damaged by ESD. Rare.
- **Firmware bug** — the button task or ISR has crashed. A power cycle or factory reset may resolve this. See [Firmware Corruption](controller-firmware-corruption.md).
- **Mechanical obstruction** — something is preventing the button from actuating (debris in the button well, enclosure misalignment after a repair).

## Probability

**Very low.** Tactile switches are among the most reliable components in the BOM. The primary button on the v1.0 mirror is used moderately — not a gaming controller or TV remote level of abuse. Mechanical failure before year 5 would be unusual.

## Repair Path

### Step 1: Rule out firmware (no tools needed)

1. Unplug the mirror, wait 5 seconds, plug back in. This power-cycles the controller and restarts the button task.
2. Try all gestures (single, double, triple, hold).
3. If it works now, it was a firmware glitch — monitor for recurrence. If it happens again, factory reset (recessed button 10s hold).

### Step 2: Physical inspection

1. Unplug from power.
2. Open the back panel (Phillips-head screws).
3. Inspect the button:
   - Is the button physically intact? Press it by hand — you should feel a tactile click.
   - Check the solder joints at the button's leads.
   - Check that the button can actuate freely through the enclosure hole.

### Step 3: Button replacement (if the switch is dead)

1. Desolder the failed button from the PCB (2 or 4 leads depending on switch type).
2. Solder in a replacement tactile switch — generic 6mm × 6mm through-hole tactile momentary switch, available from any electronics supplier.
3. Reassemble and test.

### Tools Required

- Phillips-head screwdriver
- Soldering iron + solder (for replacement)
- (Optional) Multimeter to test button continuity

### Parts Required

- **6mm × 6mm tactile momentary switch (through-hole, SPST, normally open)** — commodity part, pennies each. Available from Amazon, Adafruit, DigiKey, Mouser, or any electronics supplier.

### Estimated Difficulty

Easy (firmware reset) to Moderate (button replacement requires desoldering and resoldering).

### Estimated Time

1 minute (power cycle) to 20 minutes (physical button replacement).

## When to Contact Support

- If you're not comfortable with soldering.
- If the power cycle and factory reset don't help and the button appears physically fine — may be a GPIO issue on the MCU.
- If you'd like a replacement board with a working button pre-soldered.

## Design Mitigations

- **Internal pullup** — no external resistor needed. The GPIO's built-in pullup keeps the input clean, reducing false-trigger or stuck-low issues.
- **Firmware debouncing** — 20ms debounce window filters contact bounce, protecting the gesture state machine from noisy input.
- **App as fallback** — on ESP32 variants, all button functions are also accessible via the app/webapp. A dead button degrades the experience but doesn't brick the product.

---

## Related

- [Button — Recessed Failure](button-recessed-failure.md) — if the recessed button is the one that's dead
- [Wiring — Solder Joint Failure](wiring-solder-joint-failure.md) — if the issue is at the joint, not the switch
- [Controller — Firmware Corruption](controller-firmware-corruption.md) — if a firmware glitch is killing the button task

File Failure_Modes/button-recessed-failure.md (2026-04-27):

---
title: "Button — Recessed Unresponsive"
type: failure-mode
component: button
severity: medium
probability: very-low
user-repairable: partial
tags: [failure-mode, button, recessed, pairing, factory-reset]
---

# Button — Recessed Unresponsive

The recessed pinhole button stops working — pairing mode (3s hold) and factory reset (10s hold) can't be triggered.

---

## Symptoms

- Inserting a paperclip into the pinhole and pressing produces no response.
- The mirror doesn't enter pairing mode (no indigo pulse at 3s).
- Factory reset can't be triggered (no red flash at 10s).
- All primary button functions still work normally.
- (ESP32 variant) The device is stuck on its current Wi-Fi credentials — can't re-provision to a new network via the button path.

## Likely Causes

- **Misaligned pinhole** — the paperclip isn't reaching the button. The enclosure hole may not line up perfectly with the button center, especially after reassembly from a previous repair.
- **Button switch failure** — same as [Primary Button Failure](button-primary-failure.md), but lower probability since the recessed button is used far less frequently (a few times in the product's lifetime vs. daily use).
- **Solder joint failure** — the button's leads have cracked loose from the PCB.
- **Debris in the pinhole** — dust, paint, or a foreign object is blocking the pin from reaching the button.
- **GPIO failure** — the recessed button's GPIO pin is damaged.

## Probability

**Very low.** The recessed button is used rarely — perhaps a handful of times over the product's entire life (initial pairing, occasional re-provisioning, maybe one factory reset). Mechanical wear is essentially zero. Failure would be a manufacturing defect or alignment issue.

## Repair Path

### Step 1: Check the pinhole

1. Look into the pinhole with a flashlight — can you see the button inside?
2. Try a thinner pin or a different paperclip — the standard paperclip diameter is ~0.8mm; ensure it fits the pinhole.
3. Press firmly — the recessed mounting means you need slightly more force than the exposed primary button.

### Step 2: Check alignment

1. If you recently reassembled the mirror, the PETG enclosure may be slightly shifted. Open the back panel and verify the pinhole aligns with the button center.
2. Adjust the enclosure position if needed — it's friction-fit.

### Step 3: Button replacement

Same process as [Primary Button Failure](button-primary-failure.md) Step 3 — desolder the failed switch, solder in a replacement.

### Tools Required

- Paperclip, SIM tool, or thin pin
- Phillips-head screwdriver (if opening)
- Flashlight (for inspection)
- Soldering iron (if replacing the switch)

### Parts Required

- **6mm × 6mm tactile momentary switch** — same commodity part as the primary button. Pennies each from any electronics supplier.

### Estimated Difficulty

Easy (alignment fix) to Moderate (button replacement).

### Estimated Time

2 minutes (alignment) to 20 minutes (replacement).

## When to Contact Support

- If you can't reach the button at all and the alignment looks correct.
- If you need to re-provision Wi-Fi but can't enter pairing mode — support may be able to assist via an alternative provisioning path.
- If you need a factory reset but can't trigger it — support can reflash the board to achieve the same result.

## Design Mitigations

- **Hold-only semantics** — no tap gestures on the recessed button. This means the button only needs to register sustained contact, not precise timing. Even a marginal button that's hard to press still works if you can hold it.
- **LED threshold feedback** — the indigo pulse at 3s and red flash at 10s confirm the button *is* registering. If you see the feedback, the button works — the issue is elsewhere.
- **Recessed by design** — the pinhole placement prevents accidental activation, but the tradeoff is that the button is harder to reach. This is intentional per the [Button Interface Design §5](../docs/button-interface.md#5-recessed-button--rare-operations).

---

## Related

- [Button — Primary Failure](button-primary-failure.md) — if the daily-use button is the one that's dead
- [Controller — Wi-Fi Failure](controller-wifi-failure.md) — if you need to re-provision but the recessed button is dead
- [Controller — Firmware Corruption](controller-firmware-corruption.md) — if factory reset is needed but the button path is blocked

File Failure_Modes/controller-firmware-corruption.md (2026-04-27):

---
title: "Controller — Firmware Corruption"
type: failure-mode
component: controller-pcb
severity: high
probability: very-low
user-repairable: partial
tags: [failure-mode, controller, firmware, ota]
---

# Controller — Firmware Corruption

The controller hardware is intact, but the firmware has become corrupted — the device won't boot correctly or behaves erratically.

---

## Symptoms

- Mirror powers on but LEDs show unexpected behavior — random flashing, frozen on a single color that isn't user-selected, or a brief flash followed by reboot loop.
- Buttons don't respond normally (but the mirror does *something* on power-up, unlike a hardware failure where it does nothing).
- (ESP32 variant) Device was working, received an OTA update, and now behaves incorrectly.
- (ESP32 variant) Device shows up briefly on the network then disappears — reboot loop.

## Likely Causes

- **Interrupted OTA update** — power loss or Wi-Fi drop during a firmware write. The most likely cause for ESP32 variants.
- **NVS corruption** — the flash region holding settings was corrupted by power loss during a write cycle. See also [NVS Corruption](controller-nvs-corruption.md) for the milder variant where only settings are lost.
- **Flash memory degradation** — flash has a finite write endurance (~100,000 cycles). NVS debouncing (500ms minimum between writes) prevents premature wear, but after many years of continuous state changes, the flash region could degrade.
- **Bitrot** — extremely rare, but possible: a single-bit error in the firmware partition. More likely in high-radiation environments (not typical for a home product).

## Probability

**Very low.** The ESP32's A/B partition scheme with automatic rollback is specifically designed to prevent bricked devices from bad OTA updates. If a new firmware fails its health check within 60 seconds of boot, the bootloader automatically reverts to the previous known-good partition. A complete firmware corruption requires a failure mode that defeats this rollback mechanism.

## Repair Path

### Step 1: Factory Reset (user-serviceable)

This clears NVS and returns to factory firmware state. Resolves most corruption scenarios.

1. With the mirror powered on (even if misbehaving), use a paperclip to press and hold the recessed button for **10 seconds**.
2. LED feedback: at 3 seconds you'll see an indigo pulse (pairing threshold — keep holding). At 10 seconds, a red flash followed by a green hold confirms factory reset.
3. The mirror reboots to out-of-box defaults: Indigo Signal color, no Wi-Fi credentials, unprovisioned.
4. If the mirror now works normally, re-pair through the app.

### Step 2: OTA Recovery (if factory reset doesn't help)

If the device can connect to Wi-Fi after factory reset and re-provisioning:

1. Re-provision the device via the app (recessed button 3s hold → pairing mode).
2. The device will check for OTA updates on boot and every 24 hours.
3. If a newer firmware is available, it will self-update.

### Step 3: Reflash Service (if the device can't boot at all)

If the device is in a hard boot loop that factory reset can't resolve:

1. Contact Layered Logic support.
2. Ship the mirror (or just the controller board) for reflash. Cost: shipping only.
3. The board is reflashed via USB/JTAG using the production flashing setup — same as Station S14 in the factory.

### Tools Required

- Paperclip or SIM tool (for factory reset)
- No tools needed for OTA recovery
- (Reflash service is handled by support)

### Parts Required

None — this is a software repair. The hardware is fine.

### Estimated Difficulty

Easy (factory reset) to N/A (reflash service handled by support).

### Estimated Time

Under 1 minute (factory reset). OTA recovery depends on network speed. Reflash service: shipping time + turnaround.

## When to Contact Support

- If factory reset doesn't resolve the issue (hard boot loop persists).
- If the device can't enter pairing mode after factory reset.
- The [reflash service](../docs/right-to-repair-philosophy.md#3-what-i-commit-to) is available at cost of shipping for the life of the product.

## Design Mitigations

- **A/B OTA partitions** — bad firmware automatically rolls back within 60 seconds. A bricked device from OTA should be nearly impossible.
- **Anti-rollback protection** — monotonic version counter in eFuse prevents firmware downgrades that might reintroduce known bugs.
- **Staged OTA rollout** — new builds go to 1% → 10% → 50% → 100% of devices. Opt-in telemetry cohort gets builds first (de facto beta channel). Issues are caught before they reach the full fleet.
- **NVS write debouncing** — state writes limited to once per 500ms, protecting flash endurance.
- **Factory reset path** — the recessed button factory reset is always available as a recovery mechanism, regardless of firmware state.

---

## Related

- [Controller — Hardware Failure](controller-hardware-failure.md) — if the hardware itself is dead
- [Controller — NVS Corruption](controller-nvs-corruption.md) — milder variant where only settings are lost
- [Right-to-Repair Philosophy](../docs/right-to-repair-philosophy.md) — §3 OTA commitment, §4 reflash service

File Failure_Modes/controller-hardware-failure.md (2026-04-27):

---
title: "Controller — Hardware Failure"
type: failure-mode
component: controller-pcb
severity: high
probability: very-low
user-repairable: partial
tags: [failure-mode, controller, pcb, esp32, stm8]
---

# Controller — Hardware Failure

The MCU or controller PCB has failed — the board is non-functional and the mirror doesn't respond to any input.

---

## Symptoms

- Mirror has power (PSU is warm, barrel jack seated) but no LEDs light and no button responds.
- **Distinguishing from PSU failure:** if you have a multimeter, measure 5V at the barrel jack input on the board. If 5V is present but the board is unresponsive, the controller is the problem.
- Controller was previously working — this isn't a setup/provisioning issue.
- (ESP32 Pro/Pro+ variant) The device disappears from the app and from the network entirely.

## Likely Causes

- **ESD damage** — static discharge to an exposed GPIO or connector. Most likely during handling or repair of other components.
- **Power surge** — a spike that the PSU passed through to the board. The bulk capacitor provides some protection but can't absorb everything.
- **Manufacturing defect** — cold solder joint on the MCU, marginal crystal/oscillator, or defective IC. Pre-ship QC at Stations S14–S15 catches most of these, but latent defects can appear weeks to months after initial power-on.
- **Water or condensation damage** — if the mirror was placed in a humid environment (bathroom) without adequate protection.
- **Physical damage** — drop impact cracking the PCB or breaking a trace.

## Probability

**Very low.** The STM8 and ESP32 are industrial-grade ICs designed for reliability. Running within spec with conservative power draw, these controllers should outlast every other component. Firmware flash and function test at Stations S14–S15 catch manufacturing defects before shipping.

## Repair Path

The controller is a board-level replacement — you swap the entire PCB module.

1. Unplug the mirror from power.
2. Remove the back panel screws (Phillips-head).
3. Disconnect the LED strip from the controller (3-pin connection).
4. Disconnect the barrel jack input wiring.
5. Remove the controller from its mounting (friction-fit in PETG enclosure or screwed depending on revision).
6. Seat the replacement controller in the same position.
7. Reconnect the LED strip (match 5V, GND, Data).
8. Reconnect barrel jack input.
9. Reassemble the back panel and test.

**Note:** A replacement controller board needs firmware flashed before it will operate. Pre-flashed replacement boards are available through support. If you have a bare board, see "When to Contact Support" below.

### Tools Required

- Phillips-head screwdriver
- (Optional) Soldering iron if connections are soldered rather than connectorized

### Parts Required

- **Replacement controller PCB (pre-flashed)** — contact Layered Logic support. The PCB is custom but inexpensive (~$1–$4 at production cost). A pre-flashed board is the simplest path.
- For STM8 Basic variant: STM8S003F3P6 board per the published schematic.
- For ESP32 Pro variant: ESP32-C3-MINI-1 board per the published schematic.

### Estimated Difficulty

Moderate — straightforward physically, but requires a pre-flashed replacement board.

### Estimated Time

15–30 minutes for the physical swap.

## When to Contact Support

- **Always recommended for this failure mode.** The replacement board needs firmware, and the firmware is a closed binary. Contact support for a pre-flashed replacement board (cost of board + shipping).
- The [reflash service commitment](../docs/right-to-repair-philosophy.md#3-what-i-commit-to) means you can also send your existing board in for diagnosis and reflash at cost of shipping.
- Published schematics allow you to verify the board-level issue, but the firmware must come from Layered Logic.

## Design Mitigations

- **Published schematics** for every shipped PCB revision — the hardware is transparent even though the firmware is closed.
- **Versioned PCB silkscreen** — the revision letter is visible when the enclosure is opened, so you and support are always looking at the same schematic.
- **Firmware flash + function test** at Station S14–S15 before shipping catches manufacturing defects.
- **Bulk capacitor** on the power input provides basic surge protection.
- **Reflash service** — if the controller is physically fine but firmware-corrupted, it can be reflashed. See [Firmware Corruption](controller-firmware-corruption.md).

---

## Related

- [Controller — Firmware Corruption](controller-firmware-corruption.md) — if the hardware is fine but firmware is broken
- [Controller — Wi-Fi Failure](controller-wifi-failure.md) — network-specific issues (ESP32 only)
- [LED Strip — Total Failure](led-strip-total-failure.md) — if LEDs are dark, rule out the strip before blaming the controller
- [Right-to-Repair Philosophy](../docs/right-to-repair-philosophy.md) — §3 schematic publication, §4 closed-binary rationale

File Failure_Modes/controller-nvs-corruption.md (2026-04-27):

---
title: "Controller — NVS Data Loss"
type: failure-mode
component: controller-pcb
severity: low
probability: very-low
user-repairable: yes
tags: [failure-mode, controller, nvs, settings, esp32]
---

# Controller — NVS Data Loss

User settings stored in non-volatile storage (NVS) are lost — the mirror reverts to factory defaults unexpectedly.

**Applies to:** Both STM8 Basic (EEPROM) and ESP32 Pro/Pro+ (NVS flash partition) variants, with different symptoms.

---

## Symptoms

- The mirror powers on to the default color (Indigo Signal `#3214FF`) and default brightness instead of the user's last setting.
- (ESP32 variant) Wi-Fi credentials are lost — the device is unprovisioned and needs to be re-paired.
- Saved pattern selection is reset to the first pattern.
- This happens after a power outage, power surge, or plug pull — not during normal button use.

## Likely Causes

- **Power loss during a write cycle** — NVS/EEPROM corruption occurs when power is cut in the narrow window (milliseconds) during an active flash write. This is the primary cause.
- **Flash wear** — NVS flash sectors have a write endurance of ~100,000 cycles. If the debouncing mechanism failed or was bypassed, frequent writes could exhaust the sector.
- **Power surge** — a grid event that corrupts the flash contents.
- **Firmware bug** — a software defect that writes invalid data to NVS. Resolved via OTA update.

## Probability

**Very low.** The firmware debounces NVS writes to once per 500ms minimum, protecting against rapid state-change wear. Power-loss-during-write requires hitting a millisecond window during an infrequent write — realistic over years of use, but unlikely to happen often. STM8 EEPROM (128 bytes, 10,000 cycle endurance) is more vulnerable than ESP32 flash (~100,000 cycles with wear leveling).

## Repair Path

This is a self-resolving failure — the mirror works fine, it just lost its settings.

1. **Set your preferences again** using the primary button — color (single press), pattern (double press), brightness (triple press).
2. The new settings are saved to NVS automatically.
3. (ESP32 variant) If Wi-Fi credentials were lost, **re-provision**: recessed button 3s hold → pairing mode → enter Wi-Fi credentials via the app.

That's it. No hardware work needed.

### Tools Required

- Paperclip or SIM tool (only if re-provisioning Wi-Fi)

### Parts Required

None.

### Estimated Difficulty

Trivial.

### Estimated Time

Under 2 minutes.

## When to Contact Support

- If settings are lost **repeatedly** (more than once or twice) — may indicate flash wear or a firmware bug. Report the behavior so it can be investigated and potentially patched via OTA.
- If the mirror doesn't save new settings at all after resetting them — the NVS partition may be damaged. Factory reset (10s recessed hold) reformats NVS and may resolve it.

## Design Mitigations

- **NVS write debouncing** — state writes limited to once per 500ms, preventing rapid cycling from button mashing or pattern changes.
- **Soft-off vs. hard-off distinction** — soft-off (hold button) saves state; hard-off (power loss) resumes to a known default. This design choice means NVS corruption from power loss produces a *safe* outcome (factory defaults) rather than an *undefined* one.
- **ESP32 wear leveling** — the NVS library automatically distributes writes across the flash sector to maximize endurance.
- **Factory reset as recovery** — if NVS is badly corrupted, the 10-second recessed hold reformats the partition cleanly.

---

## Related

- [Controller — Firmware Corruption](controller-firmware-corruption.md) — more severe corruption affecting boot
- [Controller — Wi-Fi Failure](controller-wifi-failure.md) — if only Wi-Fi credentials were lost
- [PSU — No Output](psu-no-output.md) — if power loss events are frequent, address the root cause

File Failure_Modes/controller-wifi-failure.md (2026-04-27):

---
title: "Controller — Wi-Fi Connectivity Loss"
type: failure-mode
component: controller-pcb
severity: medium
probability: low
user-repairable: yes
tags: [failure-mode, controller, wifi, esp32, network]
---

# Controller — Wi-Fi Connectivity Loss

The ESP32 controller can't connect to the home Wi-Fi network. The mirror still works locally (buttons, patterns, colors) but is unreachable from the app and can't receive OTA updates.

**Applies to:** ESP32 Pro and Pro+ variants only. The STM8 Basic model has no Wi-Fi.

---

## Symptoms

- The app shows the device as "offline" or "not found."
- The mirror works fine from the physical buttons — LEDs respond, patterns change, brightness adjusts.
- mDNS discovery (`_layeredlogic._tcp.local.`) returns no results.
- The mirror was previously connected and working on the network.

## Likely Causes

- **Router change or password change** — the saved Wi-Fi credentials in NVS no longer match the network.
- **Router firmware update** changed Wi-Fi settings (channel, band, security protocol).
- **2.4GHz band disabled on router** — the ESP32-C3 only supports 2.4GHz Wi-Fi. If the router was reconfigured to 5GHz-only, the device can't connect.
- **IP conflict or DHCP exhaustion** — the router ran out of DHCP leases or assigned a conflicting IP.
- **Distance/interference** — the mirror was moved to a location with weak 2.4GHz signal.
- **ESP32 Wi-Fi radio failure** — hardware-level radio failure. Rare but possible.

## Probability

**Low for device-side issues, moderate for network-change issues.** The most common scenario is a changed router password or a router replacement — the device itself is almost never the problem. The ESP32's Wi-Fi radio is robust and industrial-grade.

## Repair Path

### If the network changed (most common):

1. Use a paperclip to hold the recessed button for **3 seconds** → mirror enters pairing mode (slow indigo pulse).
2. Open the Layered Logic app → follow the provisioning flow to enter new Wi-Fi credentials.
3. The mirror connects to the new network and saves the credentials to NVS.

### If the network hasn't changed:

1. **Restart the mirror** — unplug power, wait 5 seconds, plug back in. The ESP32 re-attempts Wi-Fi connection on boot.
2. **Restart the router** — clears DHCP state and any temporary bans.
3. **Check 2.4GHz is enabled** on the router — the ESP32-C3 doesn't support 5GHz.
4. **Move the mirror closer to the router** temporarily to rule out signal strength.
5. If none of the above helps, **re-provision**: recessed button 3s hold → pairing mode → re-enter credentials via the app. This clears and re-saves the Wi-Fi config.

### Tools Required

- Paperclip or SIM tool (for recessed button)

### Parts Required

None — this is a configuration issue.

### Estimated Difficulty

Easy.

### Estimated Time

2–5 minutes.

## When to Contact Support

- If the device won't enter pairing mode at all (recessed button unresponsive). See [Button — Recessed Failure](button-recessed-failure.md).
- If re-provisioning repeatedly fails — the Wi-Fi radio may have a hardware issue.
- If you need help identifying your 2.4GHz network name or checking router settings.

## Design Mitigations

- **Radios dark at rest** — Wi-Fi only activates after provisioning. No passive advertising means no phantom connectivity issues from boot.
- **User-initiated re-provisioning** — the 3s recessed hold makes it trivial to re-pair to a new network without opening the device.
- **Standalone operation** — Wi-Fi loss degrades app control and OTA, but **the mirror continues to work perfectly from the physical buttons.** No connectivity is required for core product function.
- **mDNS discovery** — the app finds the device automatically by service name. No manual IP entry required.

---

## Related

- [Controller — Hardware Failure](controller-hardware-failure.md) — if the radio is physically dead
- [Controller — NVS Corruption](controller-nvs-corruption.md) — if Wi-Fi credentials were lost from NVS
- [Button — Recessed Failure](button-recessed-failure.md) — if you can't enter pairing mode

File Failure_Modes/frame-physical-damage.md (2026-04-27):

---
title: "Frame — Physical Damage"
type: failure-mode
component: wood-frame
severity: low
probability: low
user-repairable: yes
tags: [failure-mode, frame, wood, physical-damage]
---

# Frame — Physical Damage

The wood frame is chipped, cracked, warped, or otherwise physically damaged.

---

## Symptoms

- Visible chip, crack, or dent in the frame edge or corner.
- Frame no longer sits flat — warping from moisture exposure.
- A panel slot has widened or loosened, causing the acrylic to rattle or shift.
- Stain or finish has worn away, exposing bare wood.

## Likely Causes

- **Drop or impact** — corners and edges are vulnerable to point impacts.
- **Moisture exposure** — untreated wood absorbs water and warps. Bathroom placement or a spill can cause this.
- **Heat proximity** — placing the mirror near a heat source (radiator, heating vent) can dry and crack the wood.
- **Wear over time** — surface finish wears from handling, moving, or resting against rough surfaces.

## Probability

**Low.** The frame is solid cut lumber (2×4 stock) — structurally robust for its size. Minor cosmetic damage (nicks, dings) is more likely than structural failure. Warping requires sustained moisture exposure.

## Repair Path

Depends on the severity of the damage.

### Minor cosmetic damage (ding, nick, surface scratch):

1. Sand the affected area lightly with 220-grit sandpaper.
2. Apply matching stain or finish (if the frame was stained).
3. Seal with a light coat of polyurethane or wax.

No disassembly needed.

### Structural damage (crack, warp, broken panel slot):

1. Unplug and fully disassemble the mirror — back panel, LED spacer, acrylic panels, electronics.
2. Remove the damaged frame piece(s).
3. Cut a replacement from matching lumber (standard 2×4 stock, available at any hardware store).
4. Route or saw the panel slot channels to match the original frame profile.
5. Reassemble with the new frame piece(s).

### Tools Required

- 220-grit sandpaper (cosmetic repair)
- Phillips-head screwdriver (disassembly)
- Saw + router or table saw with dado blade (structural replacement — the panel channel is the tricky part)

### Parts Required

- **2×4 lumber** — standard dimensional lumber from any hardware store. Cost: ~$3–$5 for a full 8' board (enough for many frames).
- **Wood stain/finish** (if applicable) — match the original.

### Estimated Difficulty

Easy (cosmetic) to Advanced (structural — requires woodworking tools for the panel channel).

### Estimated Time

10 minutes (cosmetic touch-up) to 1–2 hours (structural replacement including cutting and routing).

## When to Contact Support

- If the frame is a custom or specialty wood that you can't match locally.
- If you don't have woodworking tools to cut the panel channels for a structural replacement.
- If you'd prefer a pre-cut replacement frame set shipped to you.

## Design Mitigations

- **Standard lumber** — no exotic or proprietary materials. Any hardware store stocks 2×4 in multiple wood species.
- **3-sided frame** — the open back means the frame is accessible and modifiable without destruction.
- **Screwed assembly** — frame is held together with screws, not glue. Individual sides can be replaced without rebuilding the whole frame.

---

## Related

- [Acrylic Panel — Crack or Scratch](acrylic-crack-scratch.md) — if the frame damage also cracked a panel
- [PETG Parts — Breakage](petg-breakage.md) — if the internal mounting parts are also damaged

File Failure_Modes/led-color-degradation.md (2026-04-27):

---
title: "LED Strip — Color Degradation"
type: failure-mode
component: led-strip
severity: low
probability: very-low
user-repairable: yes
tags: [failure-mode, led, ws2812b, aging]
---

# LED Strip — Color Degradation

LEDs gradually dim, shift color, or lose brightness uniformity over extended use.

---

## Symptoms

- The strip is noticeably dimmer than when new, even at 100% brightness.
- Colors appear washed out or shifted (e.g., white looks yellowish or pinkish).
- Some LEDs are dimmer than their neighbors, creating uneven brightness across the strip.
- The mirror "doesn't look the same as it used to" — subtle but persistent.

## Likely Causes

- **Phosphor aging in the blue/green die** — WS2812B LEDs use InGaN dies. Over tens of thousands of hours the phosphor layer degrades, shifting color temperature and reducing output. This is normal semiconductor aging.
- **Prolonged high-brightness operation** — running at 100% white continuously accelerates aging. The firmware caps at ~29% of rated current, but "full white at 100% brightness" is still the highest-stress mode.
- **Environmental factors** — heat from nearby sources (radiators, direct sunlight on the mirror, enclosed shelving with poor airflow) accelerates LED aging.

## Probability

**Very low over the product's expected life.** WS2812B LEDs are rated at 50,000 hours (L70 — 70% of original brightness). At the firmware's conservative ~29% current limiting, real degradation is pushed well past 14 years at 8 hours/day. Noticeable color shift before year 10 would be unusual under normal indoor conditions.

## Repair Path

This is a gradual wear failure — by the time it's noticeable, the strip has served for many years. The fix is a full strip replacement.

1. Unplug from power.
2. Open the back panel (Phillips-head screws).
3. Disconnect and remove the old strip.
4. Install a fresh WS2812B strip (32 LEDs for 6×6, match data direction).
5. Reconnect and reassemble.

### Tools Required

- Phillips-head screwdriver
- (Optional) Soldering iron if the connection is soldered

### Parts Required

- **WS2812B LED strip, 60 LEDs/m** — ~$1.50–$5.00. Same commodity part as other LED failure modes.

### Estimated Difficulty

Easy to Moderate (same as any strip replacement).

### Estimated Time

15–25 minutes.

## When to Contact Support

- If degradation appears within the first year — that's not normal aging, it may indicate a defective batch or an electrical issue (overvoltage from PSU). See [PSU — Voltage Instability](psu-voltage-instability.md).
- If only a few LEDs are dim while others are bright — that's more likely [Dead Pixel(s)](led-dead-pixel.md) than general degradation.

## Design Mitigations

- **Conservative current limiting** (~29% of rated max) is the single biggest lifespan lever. Less current = less heat = slower phosphor aging.
- **White dimming factor** — the firmware applies a 217/255 (~85%) scaling factor on solid white specifically to reduce thermal stress in the highest-power mode.
- **No sealed enclosure** — the open-backed frame allows passive airflow, preventing heat buildup around the strip.

---

## Related

- [LED Strip — Dead Pixel(s)](led-dead-pixel.md) — sudden single-LED failure vs. gradual degradation
- [LED Strip — Total Failure](led-strip-total-failure.md) — complete strip failure
- [Right-to-Repair Philosophy](../docs/right-to-repair-philosophy.md) — §2 commodity parts commitment

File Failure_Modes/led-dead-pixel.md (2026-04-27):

---
title: "LED Strip — Dead Pixel(s)"
type: failure-mode
component: led-strip
severity: low
probability: very-low
user-repairable: yes
tags: [failure-mode, led, ws2812b]
---

# LED Strip — Dead Pixel(s)

One or more individual LEDs on the strip stop lighting, show the wrong color, or flicker while the rest of the strip operates normally.

---

## Symptoms

- A single LED stays dark while others around it work.
- An LED is stuck on one color regardless of pattern.
- An LED flickers or stutters out of sync with the pattern.
- All LEDs *after* a certain point in the chain are dark (WS2812B is a daisy chain — a dead LED breaks the data signal downstream).

## Likely Causes

- **Manufacturing defect** in the WS2812B IC — rare but possible in commodity strips.
- **Solder joint fatigue** at the LED pad, especially if the strip was bent sharply during assembly.
- **Thermal damage** — unlikely under normal operation (firmware caps drive current at ~29% of rated max), but possible from external heat sources near the mirror.
- **ESD damage** during assembly or handling — the WS2812B IC is sensitive to static discharge.

## Probability

**Very low.** WS2812B LEDs are rated for 50,000 hours. At the firmware's conservative current limiting (~29% of rated max), thermal stress is minimal and real-world lifespan exceeds the 50,000-hour spec. At 8 hours/day, that's 17+ years before age-related failure is expected. Pre-assembly testing at Station S10 catches defective strips before they ship.

## Repair Path

The LED strip is a single continuous piece — individual LEDs can't be swapped. The repair is a full strip replacement.

1. Unplug the mirror from power.
2. Remove the back panel screws (Phillips-head).
3. Lift the back panel to access the interior.
4. Disconnect the LED strip from the controller (3-pin JST or solder pads — depends on build revision).
5. Remove the strip from the LED spacer channel.
6. Seat the replacement strip in the channel (match the data direction arrow).
7. Reconnect to the controller.
8. Reassemble and test.

### Tools Required

- Phillips-head screwdriver
- (Optional) Soldering iron, if the strip is soldered rather than connectorized

### Parts Required

- **WS2812B LED strip, 60 LEDs/m density** — commodity part available from Amazon, AliExpress, Adafruit, or any electronics supplier. Cut to 32 LEDs for the 6×6 model. Cost: ~$1.50–$5.00 depending on source and quantity.

### Estimated Difficulty

Easy — no soldering if connectorized. Moderate if the strip connection is soldered.

### Estimated Time

15–25 minutes.

## When to Contact Support

- If you're uncomfortable with soldering (if applicable).
- If the replacement strip also shows dead pixels — may indicate a controller issue rather than a strip defect. See [Controller — Hardware Failure](controller-hardware-failure.md).
- If you'd like a pre-cut, pre-tested replacement strip shipped to you.

## Design Mitigations

- **Pre-ship testing:** Every LED strip is tested at receiving (Station S10) and again after solder (Station S11) — dead pixels are caught before the unit ships.
- **Current limiting:** Firmware drives LEDs at ~29% of rated max, reducing thermal stress and extending lifespan well beyond the 50,000-hour specification.
- **Commodity parts:** WS2812B strips are the most widely available addressable LED format in the world. No proprietary sourcing needed.

---

## Related

- [LED Strip — Total Failure](led-strip-total-failure.md) — when the entire strip goes dark
- [LED Strip — Color Degradation](led-color-degradation.md) — gradual dimming or color shift
- [Wiring — Solder Joint Failure](wiring-solder-joint-failure.md) — if the issue is at the connection, not the strip
- [Right-to-Repair Philosophy](../docs/right-to-repair-philosophy.md) — §2, §3

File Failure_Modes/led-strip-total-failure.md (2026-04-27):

---
title: "LED Strip — Total Failure"
type: failure-mode
component: led-strip
severity: high
probability: very-low
user-repairable: yes
tags: [failure-mode, led, ws2812b]
---

# LED Strip — Total Failure

The entire LED strip is dark — no LEDs light up at all, even though the mirror has power and the controller appears to be running.

---

## Symptoms

- Mirror is plugged in and the controller board has power (check for any indicator LED on the controller if applicable), but the strip is completely dark.
- Pressing the primary button produces no visible response.
- Patterns, colors, and brightness changes have no effect.

## Likely Causes

- **Disconnected data or power wire** — the 3-wire connection (5V, GND, Data) between the controller and strip has come loose. Most likely cause.
- **First LED in chain is dead** — because WS2812B is a serial daisy chain, a dead first LED kills the entire strip. See [LED — Dead Pixel(s)](led-dead-pixel.md).
- **Broken solder joint** at the strip-to-controller connection — vibration from shipping or moving the mirror can stress the joint.
- **5V power rail issue** — the strip's power wire is disconnected even if the data line is fine. LEDs need both data and power.
- **Controller data pin failure** — the GPIO driving the strip has failed. See [Controller — Hardware Failure](controller-hardware-failure.md).

## Probability

**Very low.** The strip itself is robust. This failure mode is almost always a connection issue, not a strip defect. Pre-ship QC at Stations S11 and S19 catches loose connections before the unit ships.

## Repair Path

Start with the simplest check and work inward.

1. **Verify power.** Unplug and replug the PSU barrel jack. Confirm the PSU LED (if present) is on.
2. **Open the back panel.** Remove Phillips-head screws, lift the panel.
3. **Check the strip connection.** Look at where the strip connects to the controller:
   - If connectorized (JST): unplug and reseat firmly.
   - If soldered: inspect the three joints (5V, GND, Data) under good light. Look for cracked or cold joints.
4. **If the connection looks good**, try a known-good replacement strip to isolate whether the strip or controller is the problem.
5. If the strip lights on a different controller (or a different strip lights on this controller), you've identified the failed component. Replace accordingly.

### Tools Required

- Phillips-head screwdriver
- (Optional) Multimeter to check continuity on the 5V and GND lines
- (Optional) Soldering iron if re-flowing a joint

### Parts Required

- **WS2812B LED strip, 60 LEDs/m** — if the strip itself is confirmed dead. Same commodity part as [LED — Dead Pixel(s)](led-dead-pixel.md). ~$1.50–$5.00.

### Estimated Difficulty

Easy (reseat connector) to Moderate (re-solder or replace strip).

### Estimated Time

5 minutes (connector reseat) to 25 minutes (full strip replacement).

## When to Contact Support

- If both the strip and the connection check out fine — the issue may be the controller's data output pin. See [Controller — Hardware Failure](controller-hardware-failure.md).
- If you don't have a multimeter or soldering iron and the connection looks suspect.

## Design Mitigations

- **Connectorized strip connections** are preferred over direct solder in production, making reseat trivial.
- **Post-solder power-on test** at Station S11 catches every dead strip and bad joint before final assembly.
- **Final QC** at Station S19 is zero-tolerance on dead LEDs — no unit ships with a strip issue.

---

## Related

- [LED Strip — Dead Pixel(s)](led-dead-pixel.md) — partial strip failure
- [Wiring — Solder Joint Failure](wiring-solder-joint-failure.md) — connection-level diagnosis
- [PSU — No Output](psu-no-output.md) — if the whole mirror is dark, check power first
- [Controller — Hardware Failure](controller-hardware-failure.md) — if the data pin is the problem

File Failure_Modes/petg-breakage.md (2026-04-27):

---
title: "PETG Parts — Breakage"
type: failure-mode
component: petg-enclosure
severity: low
probability: low
user-repairable: yes
tags: [failure-mode, petg, 3d-print, enclosure, spacer]
---

# PETG Parts — Breakage

A 3D-printed PETG component (LED spacer or electronics enclosure) has cracked, broken, or deformed.

---

## Symptoms

- The LED spacer is cracked or broken — LED strip sags or shifts position, causing uneven light distribution in the infinity tunnel.
- The electronics enclosure is cracked — controller board or wiring is exposed or loose.
- A snap-fit tab has broken off — the part no longer holds friction-fit.
- Visible deformation (warping, bowing) of a printed part.

## Likely Causes

- **Impact or drop** — PETG is tough but can crack under sharp point loads, especially at thin-wall sections or layer boundaries.
- **Overtightening a screw** — if a screw is driven into a printed boss too hard, the boss splits along layer lines.
- **Heat exposure** — PETG glass transition is ~80°C. Placement near a heat source (radiator, south-facing window in direct sun, enclosed shelf with no airflow) can soften and deform the parts.
- **Layer adhesion failure** — a 3D printing quality issue where weak inter-layer bonding causes delamination under stress. Should be caught at production QC but can manifest as a latent defect.
- **UV degradation** — PETG is reasonably UV-stable, but years of direct sunlight can embrittle it.

## Probability

**Low.** The PETG parts are internal — protected by the wood frame and back panel from most impacts. They don't bear structural load. The LED spacer's job is to hold the strip in position; the enclosure's job is to cradle the controller board. Neither is under continuous mechanical stress.

## Repair Path

This is one of the simplest repairs — reprint the part.

1. Unplug the mirror from power.
2. Remove the back panel screws (Phillips-head).
3. Remove the broken part — LED spacer lifts out of the frame; enclosure is friction-fit or screwed in place.
4. Drop in the replacement part.
5. Reassemble.

### Getting the STL file

Per the [Right-to-Repair Philosophy §3](../docs/right-to-repair-philosophy.md#3-what-i-commit-to): STL files are supplied on request to any owner reporting a specific repair need. Contact support with your order number or serial, describe which part broke, and the file will be sent.
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

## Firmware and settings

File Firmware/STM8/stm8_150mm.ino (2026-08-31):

#include "stm8s.h"

// =================== Hardware ===================
#define NUM_LEDS 32

// LED data on PC6 (custom PCB, TSSOP20 pin 16).
// Corrected 2026-08-17: this said PC7/pin 17, but the PCB has routed
// /LED_SIG from PC6 since the 5bc9107 baseline -- verified across all three
// board revisions. On PC7 the strip simply stayed dark.
#define DATA_PORT GPIOC
#define DATA_MASK GPIO_PIN_6

// Mode button on PD6 (TSSOP20 pin 3), active low. The board carries a 10k
// pull-up and a 100n debounce cap -- which is also why UART1_RX is unusable
// on this design: RX is physically PD6 and it is already spoken for.
#define BTN_PORT GPIOD
#define BTN_MASK GPIO_PIN_6

// ---- rework pass 2 hardware, 2026-08-17 (see the board's REWORK_SPEC.md) ----
// USB-C CC sense: /CC1 -> R7 10k -> PD2 (AIN3), /CC2 -> R8 10k -> PD3 (AIN4).
#define CC1_ADC_CH 3
#define CC2_ADC_CH 4
// UART1_TX debug pad TP1 on PD5 (pin 2). TP2 = GND, TP3 = PD4 (spare).
#define ENABLE_UART 1
#define UART_BAUD_DIV 139           /* 16 MHz / 115200 = 138.9 */
// IR receiver J8 (fitted DNP) OUT -> PA3 (pin 10) = TIM2_CH3.
// Set to 0 to reclaim the flash if J8 is never populated.
#define ENABLE_IR 1
// Placeholder NEC command bytes -- these are remote-specific. Every received
// code is printed on TP1, so capture your remote's actual bytes first and
// then correct these. Left as distinct dummy values so an unknown remote
// simply does nothing instead of firing the wrong action.
#define IR_CMD_POWER     0x45
#define IR_CMD_COLOR     0x46
#define IR_CMD_PATTERN   0x47
#define IR_CMD_BRIGHT_UP 0x40
#define IR_CMD_BRIGHT_DN 0x19

// CC decode. There is NO regulator on this board -- VDD is raw VBUS -- so the
// ADC is RATIOMETRIC and thresholds must be fractions of full scale, never
// absolute volts. With Rd = 5.1k the CC node sits at 0.41 V (default USB),
// 0.92 V (1.5 A) or 1.68 V (3.0 A); across VDD 4.75-5.5 V those land at codes
// 76-88, 171-198 and 313-362, so the gaps are wide and these sit mid-gap.
#define CC_TH_1A5 130
#define CC_TH_3A0 255

// Brightness ceiling per advertised source tier. 32 WS2812 at full white draw
// roughly 32 x 60 mA = 1.9 A, so each cap is (budget / 1.9 A) scaled to 255.
#define BRIGHT_CAP_DEFAULT 90       /* <=0.9 A source -> ~0.7 A budget */
#define BRIGHT_CAP_1A5 160          /* 1.5 A source   -> ~1.2 A budget */
#define BRIGHT_CAP_3A0 255          /* 3.0 A source   -> unrestricted  */
#define CC_POLL_TICKS 20            /* re-read CC about once a second */

// =================== Settings ===================
#define DEFAULT_BRIGHTNESS 128  // 0..255
#define MIN_BRIGHTNESS 25       // Minimum brightness (about 10%)
#define BRIGHTNESS_STEP 25      // 10% of 255 ~= 25
#define DEBOUNCE_MS 20          // Reduced - hardware cap handles most bounce
#define DOUBLE_CLICK_MS 200     // Max time between clicks for double/triple-click
#define LONG_PRESS_MS 600       // Hold time for long press
#define PATTERN_STEP_MS 50      // Pattern animation speed
#define WHITE_DIM_FACTOR 217    // 85% of 255 = ~217 (15% dimmer for white)

// =================== EEPROM Addresses ===================
#define EEPROM_BASE       0x4000
#define EEPROM_MAGIC_ADDR (EEPROM_BASE + 0)
#define EEPROM_COLOR_ADDR (EEPROM_BASE + 1)
#define EEPROM_PATTERN_ADDR (EEPROM_BASE + 2)
#define EEPROM_BRIGHTNESS_ADDR (EEPROM_BASE + 3)
#define EEPROM_MAGIC_VALUE 0xA5  // Indicates valid saved state

// =================== Color Definitions ===================
// Colors: white, red, red-orange, orange, yellow-orange, yellow,
//         yellow-green, green, blue-green, blue, blue-purple, purple, red-purple
#define NUM_COLORS 13

typedef struct {
  uint8_t r, g, b;
} RGB;

static const RGB colors[NUM_COLORS] = {
  {255, 255, 255},  // White
  {255, 0, 0},      // Red
  {255, 64, 0},     // Red-Orange
  {255, 128, 0},    // Orange
  {255, 192, 0},    // Yellow-Orange
  {255, 255, 0},    // Yellow
  {128, 255, 0},    // Yellow-Green
  {0, 255, 0},      // Green
  {0, 255, 128},    // Blue-Green
  {0, 0, 255},      // Blue
  {64, 0, 255},     // Blue-Purple
  {128, 0, 255},    // Purple
  {255, 0, 128}     // Red-Purple
};

// =================== Pattern Definitions ===================
#define NUM_PATTERNS 7
typedef enum {
  PATTERN_SOLID = 0,
  PATTERN_RAINBOW,
  PATTERN_SCANNER,
  PATTERN_SPINNER,
  PATTERN_RANDOM,
  PATTERN_BREATHING,
  PATTERN_TWINKLE
} Pattern;

// =================== State ===================
static uint8_t isOn = 0;
static uint8_t currentColor = 0;
static uint8_t currentPattern = PATTERN_SOLID;
static uint8_t currentBrightness = DEFAULT_BRIGHTNESS;
static uint8_t animStep = 0;
static uint8_t breathDir = 1;
static uint8_t breathVal = 0;

// LED buffer for patterns
static RGB ledBuffer[NUM_LEDS];

// Random state
static uint16_t rngState = 12345;

// =================== Utilities ===================
static uint8_t scale8(uint8_t v, uint8_t sc) {
  return (uint16_t)v * sc / 255;
}

static void delay_ms_soft(uint16_t ms) {
  while (ms--) for (volatile uint16_t i = 0; i < 1600; i++) __asm__("nop");
}

static uint8_t random8(void) {
  // Simple 16-bit LFSR for STM8
  uint8_t lsb;
  lsb = rngState & 1;
  rngState >>= 1;
  if (lsb) {
    rngState ^= 0xB400;  // Taps for maximal length
  }
  return (uint8_t)rngState;
}

// =================== EEPROM Functions ===================
static void eeprom_unlock(void) {
  FLASH->DUKR = 0xAE;  // First key
  FLASH->DUKR = 0x56;  // Second key
  while (!(FLASH->IAPSR & FLASH_IAPSR_DUL));  // Wait for unlock
}

static void eeprom_lock(void) {
  FLASH->IAPSR &= (uint8_t)~FLASH_IAPSR_DUL;
}

static void eeprom_write(uint16_t addr, uint8_t data) {
  eeprom_unlock();
  *((uint8_t *)addr) = data;
  while (!(FLASH->IAPSR & FLASH_IAPSR_EOP));  // Wait for write complete
  eeprom_lock();
}

static uint8_t eeprom_read(uint16_t addr) {
  return *((uint8_t *)addr);
}

static void saveState(void) {
  eeprom_write(EEPROM_COLOR_ADDR, currentColor);
  eeprom_write(EEPROM_PATTERN_ADDR, currentPattern);
  eeprom_write(EEPROM_BRIGHTNESS_ADDR, currentBrightness);
  eeprom_write(EEPROM_MAGIC_ADDR, EEPROM_MAGIC_VALUE);
}

static void clearSavedState(void) {
  // Invalidate saved state - power loss will reset to defaults
  eeprom_write(EEPROM_MAGIC_ADDR, 0x00);
}

static uint8_t loadState(void) {
  // Returns 1 if state was loaded, 0 if using defaults
  if (eeprom_read(EEPROM_MAGIC_ADDR) == EEPROM_MAGIC_VALUE) {
    currentColor = eeprom_read(EEPROM_COLOR_ADDR);
    currentPattern = eeprom_read(EEPROM_PATTERN_ADDR);
    currentBrightness = eeprom_read(EEPROM_BRIGHTNESS_ADDR);
    // Validate loaded values
    if (currentColor >= NUM_COLORS) currentColor = 0;
    if (currentPattern >= NUM_PATTERNS) currentPattern = 0;
    if (currentBrightness < MIN_BRIGHTNESS) currentBrightness = DEFAULT_BRIGHTNESS;
    // Clear after loading so power loss won't restore this state again
    clearSavedState();
    return 1;
  }
  return 0;
}

// =================== USB-C CC sense (ADC) ===================
// PD2/PD3 MUST stay input-floating (CR1 clear). An internal pull-up would
// corrupt the CC divider and misread even a good 3 A source -- not a silent
// failure, so never blanket-init these two pins as pull-up inputs.
static uint8_t ccTier = 0;                   /* 0 = default, 1 = 1.5A, 2 = 3.0A */
static uint8_t ccMaxBright = BRIGHT_CAP_DEFAULT;

static void adc_init(void) {
  volatile uint8_t d;
  GPIO_Init(GPIOD, (GPIO_Pin_TypeDef)(GPIO_PIN_2 | GPIO_PIN_3),
            GPIO_MODE_IN_FL_NO_IT);
  ADC1->CR1 = 0x00;                  /* fmaster/2, single conversion mode */
  ADC1->CR2 = ADC1_CR2_ALIGN;        /* right aligned -> read DRL before DRH */
  ADC1->CR1 |= ADC1_CR1_ADON;        /* the first ADON only wakes the ADC */
  for (d = 0; d < 60; d++) __asm__("nop");   /* tSTAB = 7 us at 16 MHz */
}

static uint16_t adc_read(uint8_t ch) {
  uint8_t i;
  uint16_t v = 0;
  ADC1->CSR = ch;                    /* select channel, clear EOC, no interrupt */
  /* Two back-to-back conversions, keep the second. Source impedance is
     10k + 5.1k ~= 15.1k against the 3 pF sample-and-hold: ~8.3 time constants
     inside the 0.75 us sample window, so ONE conversion is already good to
     ~0.3 LSB. (At the 22k this started life as it was 4.6 tau and ~10 LSB,
     and the second read was mandatory.) Kept as belt-and-braces -- it costs
     a few microseconds and makes the result independent of whatever else
     the ADC is later used for. */
  for (i = 0; i < 2; i++) {
    ADC1->CR1 |= ADC1_CR1_ADON;      /* the second ADON starts a conversion */
    while (!(ADC1->CSR & ADC1_CSR_EOC));
    v = (uint16_t)ADC1->DRL;         /* DRL FIRST when right-aligned */
    v |= (uint16_t)((uint16_t)ADC1->DRH << 8);
    ADC1->CSR &= (uint8_t)~ADC1_CSR_EOC;
  }
  return v;
}

static void cc_poll(void) {
  uint16_t a, b, cc;
  a = adc_read(CC1_ADC_CH);
  b = adc_read(CC2_ADC_CH);
  cc = (a > b) ? a : b;              /* the mated orientation is the higher one */
  if (cc >= CC_TH_3A0)      ccTier = 2;
  else if (cc >= CC_TH_1A5) ccTier = 1;
  else                      ccTier = 0;
  ccMaxBright = (ccTier == 2) ? BRIGHT_CAP_3A0
              : (ccTier == 1) ? BRIGHT_CAP_1A5 : BRIGHT_CAP_DEFAULT;
}

// =================== UART1 debug: TP1 = PD5 (TX), TP2 = GND ===================
#if ENABLE_UART
static void uart_init(void) {
  /* UART1 drives PD5 itself once TEN is set. Transmit only -- RX would be
     PD6, which is the Mode button. */
  UART1->CR1 = 0x00;
  UART1->CR3 = 0x00;                 /* 1 stop bit */
  UART1->BRR2 = (uint8_t)((UART_BAUD_DIV & 0x0F) |
                          ((UART_BAUD_DIV >> 8) & 0xF0));
  UART1->BRR1 = (uint8_t)((UART_BAUD_DIV >> 4) & 0xFF);  /* BRR1 last: it latches */
  UART1->CR2 = UART1_CR2_TEN;
}

static void uart_putc(char c) {
  while (!(UART1->SR & UART1_SR_TXE));
  UART1->DR = (uint8_t)c;
}

static void uart_puts(const char *s) {
  while (*s) uart_putc(*s++);
}

static void uart_putu16(uint16_t v) {
  char buf[6];
  uint8_t i = 5;
  buf[5] = 0;
  if (!v) { uart_putc('0'); return; }
  while (v && i) { buf[--i] = (char)('0' + (uint8_t)(v % 10)); v /= 10; }
  uart_puts(&buf[i]);
}
#else
#define uart_init()
#define uart_puts(s)
#define uart_putu16(v)
#endif

// =================== IR receiver: J8 (DNP) OUT -> PA3 ===================
#if ENABLE_IR
/* PA3 = TIM2_CH3 as the DEFAULT alternate function. Leave option byte AFR1
   UNPROGRAMMED: it would remap TIM2_CH3 to PD2, which is now AIN3, and the
   datasheet's bracket notation means an exclusive choice, not a duplicate.

   NEC framing, measured falling edge to falling edge with TIM2 at 8 us/tick:
   leader 13.5 ms, '0' 1.125 ms, '1' 2.25 ms. showLEDs() disables interrupts
   for about 1 ms per 50 ms frame, so an edge is occasionally lost; NEC
   remotes repeat, so a dropped frame is not worth extra machinery. */
#define IR_LEADER_MIN 1400
#define IR_LEADER_MAX 1900
#define IR_ZERO_MIN     90
#define IR_ZERO_MAX    190
#define IR_ONE_MIN     220
#define IR_ONE_MAX     350

static volatile uint32_t irShift = 0;
static volatile uint16_t irLast = 0;
static volatile uint8_t irBits = 0;
static volatile uint8_t irCmd = 0;
static volatile uint8_t irReady = 0;

static void ir_init(void) {
  /* Pulled up so the pin does not float on boards where J8 is not fitted. */
  GPIO_Init(GPIOA, GPIO_PIN_3, GPIO_MODE_IN_PU_NO_IT);
  TIM2->PSCR = 7;                    /* 16 MHz / 128 = 8 us per tick */
  TIM2->CCMR3 = 0x01;                /* CC3 = input, mapped to TI3 */
  TIM2->CCER2 = 0x03;                /* CC3E | CC3P -> capture on falling edge */
  TIM2->IER = TIM2_IER_CC3IE;
  TIM2->CR1 = 0x01;                  /* counter on, free running */
}

INTERRUPT_HANDLER(TIM2_CAPCOM_IRQHandler, 14) {
  uint16_t now, d;
  uint8_t cmd, inv;
  if (!(TIM2->SR1 & TIM2_SR1_CC3IF)) return;
  now = (uint16_t)(((uint16_t)TIM2->CCR3H << 8) | TIM2->CCR3L);
  TIM2->SR1 = (uint8_t)~TIM2_SR1_CC3IF;
  d = (uint16_t)(now - irLast);      /* 16-bit wrap is intentional */
  irLast = now;
  if (d >= IR_LEADER_MIN && d <= IR_LEADER_MAX) {
    irShift = 0; irBits = 0;
  } else if (d >= IR_ZERO_MIN && d <= IR_ZERO_MAX) {
    irShift <<= 1; irBits++;
  } else if (d >= IR_ONE_MIN && d <= IR_ONE_MAX) {
    irShift = (irShift << 1) | 1UL; irBits++;
  } else {
    irBits = 0;                      /* out of spec: resync on the next leader */
  }
  if (irBits >= 32) {
    cmd = (uint8_t)((irShift >> 8) & 0xFF);
    inv = (uint8_t)(irShift & 0xFF);
    if ((uint8_t)(~cmd) == inv) { irCmd = cmd; irReady = 1; }
    irBits = 0;
  }
}
#endif

// =================== WS2812B driver (16MHz STM8) ===================
#define NOP1 __asm__("nop")
#define NOP2 NOP1; NOP1
#define NOP4 NOP2; NOP2
#define NOP10 NOP4; NOP4; NOP2

static void sendByte(uint8_t b) {
  uint8_t i;
  for (i = 0; i < 8; i++) {
    if (b & 0x80) {
      DATA_PORT->ODR |= DATA_MASK;
      NOP10; NOP2;
      DATA_PORT->ODR &= (uint8_t)~DATA_MASK;
      NOP4;
    } else {
      DATA_PORT->ODR |= DATA_MASK;
      NOP4;
      DATA_PORT->ODR &= (uint8_t)~DATA_MASK;
      NOP10; NOP2;
    }
    b <<= 1;
  }
}

static void showLEDs(void) {
  uint8_t i;
  volatile uint16_t j;
  uint8_t r, g, b, br;
  disableInterrupts();
  for (i = 0; i < NUM_LEDS; i++) {
    // Apply white dimming if color is white (index 0)
    br = currentBrightness;
    /* Hard ceiling from the USB-C source's advertised current. Applied here,
       not in the button handlers, so nothing can route around it. */
    if (br > ccMaxBright) br = ccMaxBright;
    if (currentColor == 0 && currentPattern == PATTERN_SOLID) {
      br = scale8(br, WHITE_DIM_FACTOR);
    }
    r = scale8(ledBuffer[i].r, br);
    g = scale8(ledBuffer[i].g, br);
    b = scale8(ledBuffer[i].b, br);
    sendByte(g); sendByte(r); sendByte(b);
  }
  enableInterrupts();
  for (j = 0; j < 2500; j++) __asm__("nop");
}

static void setAllLEDs(uint8_t r, uint8_t g, uint8_t b) {
  uint8_t i;
  for (i = 0; i < NUM_LEDS; i++) {
    ledBuffer[i].r = r;
    ledBuffer[i].g = g;
    ledBuffer[i].b = b;
  }
}

static void clearLEDs(void) {
  setAllLEDs(0, 0, 0);
  showLEDs();
}

// =================== Color Wheel (for rainbow) ===================
static void wheel(uint8_t pos, uint8_t *r, uint8_t *g, uint8_t *b) {
  if (pos < 85) { *r = 255 - pos*3; *g = pos*3; *b = 0; }
  else if (pos < 170) { pos -= 85; *r = 0; *g = 255 - pos*3; *b = pos*3; }
  else { pos -= 170; *r = pos*3; *g = 0; *b = 255 - pos*3; }
}

// =================== Pattern Functions ===================
static void pattern_solid(void) {
  uint8_t cr = colors[currentColor].r;
  uint8_t cg = colors[currentColor].g;
  uint8_t cb = colors[currentColor].b;
  setAllLEDs(cr, cg, cb);
}

static void pattern_rainbow(void) {
  uint8_t i, pos;
  for (i = 0; i < NUM_LEDS; i++) {
    pos = (i * 256 / NUM_LEDS + animStep) & 0xFF;
    wheel(pos, &ledBuffer[i].r, &ledBuffer[i].g, &ledBuffer[i].b);
  }
  animStep += 3;
}

static void pattern_scanner(void) {
  uint8_t cr, cg, cb, pos, i;
  cr = colors[currentColor].r;
  cg = colors[currentColor].g;
  cb = colors[currentColor].b;
  pos = animStep % (NUM_LEDS * 2);
  if (pos >= NUM_LEDS) pos = (NUM_LEDS * 2) - pos - 1;

  // Fade all LEDs
  for (i = 0; i < NUM_LEDS; i++) {
    ledBuffer[i].r = ledBuffer[i].r > 20 ? ledBuffer[i].r - 20 : 0;
    ledBuffer[i].g = ledBuffer[i].g > 20 ? ledBuffer[i].g - 20 : 0;
    ledBuffer[i].b = ledBuffer[i].b > 20 ? ledBuffer[i].b - 20 : 0;
  }

  // Set scanner head with tail
  ledBuffer[pos].r = cr;
  ledBuffer[pos].g = cg;
  ledBuffer[pos].b = cb;

  animStep++;
}

static void pattern_spinner(void) {
  // 4-point spinner - lights at 4 equally spaced positions
  uint8_t cr, cg, cb, spacing, offset, arm, pos, tailPos;
  cr = colors[currentColor].r;
  cg = colors[currentColor].g;
  cb = colors[currentColor].b;
  setAllLEDs(0, 0, 0);

  spacing = NUM_LEDS / 4;
  offset = animStep % spacing;

  for (arm = 0; arm < 4; arm++) {
    pos = (arm * spacing + offset) % NUM_LEDS;
    ledBuffer[pos].r = cr;
    ledBuffer[pos].g = cg;
    ledBuffer[pos].b = cb;

    // Add tail
    tailPos = (pos + NUM_LEDS - 1) % NUM_LEDS;
    ledBuffer[tailPos].r = cr / 3;
    ledBuffer[tailPos].g = cg / 3;
    ledBuffer[tailPos].b = cb / 3;
  }

  animStep++;
}

static void pattern_random(void) {
  uint8_t cr, cg, cb, i, pos;
  cr = colors[currentColor].r;
  cg = colors[currentColor].g;
  cb = colors[currentColor].b;

  // Fade existing
  for (i = 0; i < NUM_LEDS; i++) {
    ledBuffer[i].r = ledBuffer[i].r > 15 ? ledBuffer[i].r - 15 : 0;
    ledBuffer[i].g = ledBuffer[i].g > 15 ? ledBuffer[i].g - 15 : 0;
    ledBuffer[i].b = ledBuffer[i].b > 15 ? ledBuffer[i].b - 15 : 0;
  }

  // Light random LEDs
  if ((animStep % 3) == 0) {
    pos = random8() % NUM_LEDS;
    ledBuffer[pos].r = cr;
    ledBuffer[pos].g = cg;
    ledBuffer[pos].b = cb;
  }

  animStep++;
}

static void pattern_breathing(void) {
  uint8_t cr, cg, cb, i;
  cr = colors[currentColor].r;
  cg = colors[currentColor].g;
  cb = colors[currentColor].b;

  // Update breath value
  if (breathDir) {
    if (breathVal < 250) breathVal += 5;
    else breathDir = 0;
  } else {
    if (breathVal > 5) breathVal -= 5;
    else breathDir = 1;
  }

  // Apply breath to all LEDs
  for (i = 0; i < NUM_LEDS; i++) {
    ledBuffer[i].r = scale8(cr, breathVal);
    ledBuffer[i].g = scale8(cg, breathVal);
    ledBuffer[i].b = scale8(cb, breathVal);
  }
}

static void pattern_twinkle(void) {
  uint8_t cr, cg, cb, i, rnd;
  cr = colors[currentColor].r;
  cg = colors[currentColor].g;
  cb = colors[currentColor].b;

  // Randomly brighten or dim each LED
  for (i = 0; i < NUM_LEDS; i++) {
    rnd = random8();
    if (rnd < 30) {
      // Sparkle on
      ledBuffer[i].r = cr;
      ledBuffer[i].g = cg;
      ledBuffer[i].b = cb;
    } else {
      // Fade
      ledBuffer[i].r = ledBuffer[i].r > 10 ? ledBuffer[i].r - 10 : 0;
      ledBuffer[i].g = ledBuffer[i].g > 10 ? ledBuffer[i].g - 10 : 0;
      ledBuffer[i].b = ledBuffer[i].b > 10 ? ledBuffer[i].b - 10 : 0;
    }
  }
}

static void updatePattern(void) {
  switch (currentPattern) {
    case PATTERN_SOLID:    pattern_solid(); break;
    case PATTERN_RAINBOW:  pattern_rainbow(); break;
    case PATTERN_SCANNER:  pattern_scanner(); break;
    case PATTERN_SPINNER:  pattern_spinner(); break;
    case PATTERN_RANDOM:   pattern_random(); break;
    case PATTERN_BREATHING: pattern_breathing(); break;
    case PATTERN_TWINKLE:  pattern_twinkle(); break;
  }
  showLEDs();
}

// =================== Button Handling ===================
typedef enum {
  BTN_NONE = 0,
  BTN_SINGLE,
  BTN_DOUBLE,
  BTN_TRIPLE,
  BTN_LONG
} ButtonEvent;
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
void loop() {
  ButtonEvent btn;
  static uint8_t ccTick = 0;
  static uint8_t lastTier = 255;

  // Re-read the CC lines about once a second: the cable can be swapped for a
  // weaker charger at any time, and the brightness ceiling has to follow.
  if (++ccTick >= CC_POLL_TICKS) {
    ccTick = 0;
    cc_poll();
    if (ccTier != lastTier) {
      lastTier = ccTier;
      uart_puts("CC tier=");
      uart_putu16(ccTier);
      uart_puts(" cap=");
      uart_putu16(ccMaxBright);
      uart_puts("\r\n");
    }
  }

#if ENABLE_IR
  // Unknown codes are printed rather than ignored: that is how you learn a
  // given remote's map. Point a terminal at TP1 (115200 8N1, ground on TP2),
  // press buttons, then fill in the IR_CMD_* defines below.
  if (irReady) {
    uint8_t c = irCmd;
    irReady = 0;
    uart_puts("IR 0x");
    uart_putu16(c);
    uart_puts("\r\n");
    switch (c) {
      case IR_CMD_POWER:
        if (isOn) { saveState(); isOn = 0; clearLEDs(); }
        else { isOn = 1; loadState(); animStep = 0; breathVal = 0; breathDir = 1; }
        break;
      case IR_CMD_COLOR:
        if (isOn && ++currentColor >= NUM_COLORS) currentColor = 0;
        break;
      case IR_CMD_PATTERN:
        if (isOn) {
          if (++currentPattern >= NUM_PATTERNS) currentPattern = 0;
          animStep = 0; breathVal = 0; breathDir = 1;
          setAllLEDs(0, 0, 0);
        }
        break;
      case IR_CMD_BRIGHT_UP:
        if (isOn && currentBrightness <= (255 - BRIGHTNESS_STEP))
          currentBrightness += BRIGHTNESS_STEP;
        break;
      case IR_CMD_BRIGHT_DN:
        if (isOn && currentBrightness >= (MIN_BRIGHTNESS + BRIGHTNESS_STEP))
          currentBrightness -= BRIGHTNESS_STEP;
        break;
      default:
        break;
    }
  }
#endif

  btn = checkButton();

  switch (btn) {
    case BTN_SINGLE:
      // Single press: turn on or change color
      if (!isOn) {
        isOn = 1;
        // Try to load saved state (from long-press off in same power session)
        // If no saved state, defaults are already set
        loadState();
        animStep = 0;
        breathVal = 0;
        breathDir = 1;
      } else {
        // Cycle to next color
        currentColor++;
        if (currentColor >= NUM_COLORS) {
          currentColor = 0;
        }
      }
      break;

    case BTN_DOUBLE:
      // Double press: cycle pattern
      if (isOn) {
        currentPattern++;
        if (currentPattern >= NUM_PATTERNS) {
          currentPattern = 0;
        }
        animStep = 0;
        breathVal = 0;
        breathDir = 1;
        // Clear buffer for clean pattern start
        setAllLEDs(0, 0, 0);
      }
      break;

    case BTN_TRIPLE:
      // Triple press: reduce brightness by 10%
      if (isOn) {
        if (currentBrightness > MIN_BRIGHTNESS + BRIGHTNESS_STEP) {
          currentBrightness -= BRIGHTNESS_STEP;
        } else {
          // Wrap around to full brightness
          currentBrightness = DEFAULT_BRIGHTNESS;
        }
      }
      break;

    case BTN_LONG:
      // Long press: turn off and save state
      saveState();
      isOn = 0;
      clearLEDs();
      break;

    default:
      break;
  }

  // Update LEDs if on
  if (isOn) {
    updatePattern();
  }

  delay_ms_soft(PATTERN_STEP_MS);
}

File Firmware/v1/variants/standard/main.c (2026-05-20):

/*
 * Layered Logic Infinity Mirror — Standard variant (Pro).
 *
 * Wiring order matters:
 *   1.  nvs_init               — load persisted state (or defaults on first boot).
 *   2.  state_bus              — seed the bus with that state; everyone subscribes to its loop.
 *   3.  nvs_subscribe          — start debounced save-on-change AFTER the bus exists.
 *   3a. auth_init/subscribe    — load the paired-mode shared secret; wipe it on factory reset.
 *   4.  provisioning_init      — bring up netif/wifi; connect if creds saved, else
 *                                 configure (but don't start) the SoftAP.
 *   5.  provisioning_subscribe — react to LL_EV_PROVISION_START / FACTORY_RESET /
 *                                 WIFI_APPLY_CREDS.
 *   6.  mdns_init              — set hostname; service publication deferred to WIFI_CONNECTED.
 *   7.  mdns_subscribe         — listen for WIFI_CONNECTED / DISCONNECTED / AUTH_MODE.
 *   8.  transport_init         — placeholder; httpd lazy-starts on WIFI_CONNECTED.
 *   9.  transport_subscribe    — wire WIFI_CONNECTED → start_server, DISCONNECTED → stop.
 *   10. captive_dns_init       — placeholder; UDP responder lazy-starts on WIFI_CONNECTED.
 *   11. captive_dns_subscribe  — wire WIFI_CONNECTED → start_responder (AP-mode only).
 *   12. pattern_interp         — registers handlers + brings up led_driver.
 *   13. button                 — starts posting events that the others now listen for.
 *   14. provisioning_kick_softap — actually start the SoftAP now that subscribers are wired.
 */

#include <stdio.h>

#include "esp_event.h"
#include "esp_log.h"
#include "freertos/FreeRTOS.h"
#include "freertos/task.h"

#include "auth.h"
#include "board.h"
#include "button.h"
#include "captive_dns.h"
#include "ll_mdns.h"
#include "nvs.h"
#include "ota.h"
#include "pattern_interp.h"
#include "provisioning.h"
#include "state_bus.h"
#include "state_bus_events.h"
#include "telemetry.h"
#include "transport.h"

static const char *TAG = "main";

static void on_state_changed(void *arg, esp_event_base_t base,
                             int32_t id, void *data)
{
    (void)arg; (void)base; (void)id;
    const ll_state_changed_payload_t *p = data;
    const ll_state_t *s = ll_state_bus_get();
    ESP_LOGI(TAG,
             "state changed (field=%d): on=%d pattern=%s brightness=%u color=#%06lX",
             (int)p->which, (int)s->on, s->pattern_id,
             (unsigned)s->brightness, (unsigned long)s->base_color_rgb);
}

void app_main(void)
{
    printf("Layered Logic Infinity Mirror — standard variant\n");
    printf("Board: LED pin=%d, primary btn=%d, reset btn=%d\n",
           LL_PIN_LED_DATA, LL_PIN_BUTTON_PRIMARY, LL_PIN_BUTTON_RESET);
    printf("Default LED count: %d\n", LL_LED_COUNT_DEFAULT);

    ll_state_t initial;
    bool first_boot;
    ESP_ERROR_CHECK(ll_nvs_init(&initial, &first_boot));

    ll_state_bus_init(&initial);

    ESP_ERROR_CHECK(ll_nvs_subscribe());

    /* Auth: load the paired-mode shared secret from NVS (open mode if none);
     * subscribe so a factory reset wipes it. Per LL-057-D / firmware-security §5. */
    ESP_ERROR_CHECK(ll_auth_init());
    ESP_ERROR_CHECK(ll_auth_subscribe());

    ESP_ERROR_CHECK(ll_provisioning_init());
    ESP_ERROR_CHECK(ll_provisioning_subscribe());

    ESP_ERROR_CHECK(ll_mdns_init());
    ESP_ERROR_CHECK(ll_mdns_subscribe());

    ESP_ERROR_CHECK(ll_transport_init());
    ESP_ERROR_CHECK(ll_transport_subscribe());

    ESP_ERROR_CHECK(ll_captive_dns_init());
    ESP_ERROR_CHECK(ll_captive_dns_subscribe());

    /* OTA: subscribes to LL_EV_WIFI_CONNECTED. The first connect after
     * boot marks the running image as valid (cancels rollback). If the
     * image panics or never reaches Wi-Fi, the bootloader rolls back
     * to the previous slot on the next reset — see
     * CONFIG_BOOTLOADER_APP_ROLLBACK_ENABLE in sdkconfig.defaults. */
    ESP_ERROR_CHECK(ll_ota_init());
    ESP_ERROR_CHECK(ll_ota_subscribe());

    /* Telemetry: 24h jittered beacon to telemetry.layeredlogic.cc/v1/beacon.
     * Gated by state.telemetry_enabled — first beacon fires 1-5 min
     * after the first WIFI_CONNECTED. Per firmware-spec §4.10 / LL-057-C. */
    ESP_ERROR_CHECK(ll_telemetry_init());
    ESP_ERROR_CHECK(ll_telemetry_subscribe());

    ESP_ERROR_CHECK(esp_event_handler_instance_register_with(
        ll_state_bus_get_loop(),
        LL_STATE_EVENT_BASE, LL_EV_STATE_CHANGED,
        on_state_changed, NULL, NULL));

    ll_pattern_interp_init();
    ll_button_init();

    /* Start the SoftAP now that every *_subscribe has run, so downstream
     * modules don't miss the LL_EV_WIFI_CONNECTED event the AP_START
     * handler posts. No-op when LL_SOFTAP_PROVISIONING=0 or when the
     * device booted with creds saved (STA path took over instead). */
    ESP_ERROR_CHECK(ll_provisioning_kick_softap());

    /* Live behavior:
     *   primary single  → power on, then cycle base color (17 steps)
     *   primary double  → cycle pattern (solid/rainbow/scanner/spinner/
     *                     random/breathing/twinkle)
     *   primary triple  → cycle brightness (25/50/75/100)
     *   primary hold    → power off
     *   recessed press  → blue blink (visual feedback while held)
     *   recessed ≥3s release → provision start
     *   recessed ≥10s hold   → factory reset (red flash → green hold)
     */

    while (1) {
        vTaskDelay(pdMS_TO_TICKS(1000));
    }
}

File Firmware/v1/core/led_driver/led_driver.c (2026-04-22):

/*
 * WS2812B driver over ESP-IDF RMT.
 *
 * Wire format (WS2812B, 800 kHz, NZR):
 *   bit '0'   : T0H ~0.4 µs high, T0L ~0.85 µs low
 *   bit '1'   : T1H ~0.8 µs high, T1L ~0.45 µs low
 *   reset/latch: ≥ 50 µs low
 *
 * RMT resolution is 10 MHz (100 ns/tick), so:
 *   T0H=4 T0L=8   -> 0.4 / 0.8 µs
 *   T1H=8 T1L=4   -> 0.8 / 0.4 µs
 *   RESET: 500 ticks low = 50 µs
 *
 * We compose two encoders: a bytes_encoder that turns each payload byte
 * into the NZR bit stream, then a copy_encoder that emits the reset
 * symbol afterwards. The outer encoder below drives them in sequence.
 */

#include "led_driver.h"
#include "led_driver_logic.h"

#include <stdlib.h>
#include <string.h>

#include "board.h"
#include "driver/rmt_tx.h"
#include "esp_check.h"
#include "esp_log.h"
#include "freertos/FreeRTOS.h"

static const char *TAG = "led_driver";

#define LED_RMT_RESOLUTION_HZ   10000000   /* 10 MHz -> 100 ns/tick */
#define LED_RMT_MEM_BLOCK_SYM   64         /* min for single channel */

/* Bit timings in RMT ticks at 10 MHz. */
#define T0H_TICKS  4
#define T0L_TICKS  8
#define T1H_TICKS  8
#define T1L_TICKS  4
#define RESET_TICKS  500   /* 50 µs low */

typedef struct {
    rmt_encoder_t base;
    rmt_encoder_t *bytes_encoder;
    rmt_encoder_t *copy_encoder;
    int state;                       /* 0: bytes, 1: reset, done when >=2 */
    rmt_symbol_word_t reset_symbol;
} ws2812_encoder_t;

static size_t ws2812_encode(rmt_encoder_t *enc,
                            rmt_channel_handle_t channel,
                            const void *primary_data, size_t data_size,
                            rmt_encode_state_t *ret_state)
{
    ws2812_encoder_t *self = __containerof(enc, ws2812_encoder_t, base);
    rmt_encode_state_t session_state = RMT_ENCODING_RESET;
    rmt_encode_state_t state = RMT_ENCODING_RESET;
    size_t encoded = 0;

    if (self->state == 0) {
        encoded += self->bytes_encoder->encode(self->bytes_encoder, channel,
                                               primary_data, data_size,
                                               &session_state);
        if (session_state & RMT_ENCODING_COMPLETE) {
            self->state = 1;
        }
        if (session_state & RMT_ENCODING_MEM_FULL) {
            state |= RMT_ENCODING_MEM_FULL;
            goto out;
        }
    }

    if (self->state == 1) {
        encoded += self->copy_encoder->encode(self->copy_encoder, channel,
                                              &self->reset_symbol,
                                              sizeof(self->reset_symbol),
                                              &session_state);
        if (session_state & RMT_ENCODING_COMPLETE) {
            self->state = 2;
            state |= RMT_ENCODING_COMPLETE;
        }
        if (session_state & RMT_ENCODING_MEM_FULL) {
            state |= RMT_ENCODING_MEM_FULL;
        }
    }

out:
    *ret_state = state;
    return encoded;
}

static esp_err_t ws2812_reset_encoder(rmt_encoder_t *enc)
{
    ws2812_encoder_t *self = __containerof(enc, ws2812_encoder_t, base);
    rmt_encoder_reset(self->bytes_encoder);
    rmt_encoder_reset(self->copy_encoder);
    self->state = 0;
    return ESP_OK;
}

static esp_err_t ws2812_del_encoder(rmt_encoder_t *enc)
{
    ws2812_encoder_t *self = __containerof(enc, ws2812_encoder_t, base);
    if (self->bytes_encoder) rmt_del_encoder(self->bytes_encoder);
    if (self->copy_encoder)  rmt_del_encoder(self->copy_encoder);
    free(self);
    return ESP_OK;
}

static esp_err_t new_ws2812_encoder(rmt_encoder_t **out_enc)
{
    ws2812_encoder_t *self = calloc(1, sizeof(*self));
    if (!self) return ESP_ERR_NO_MEM;

    self->base.encode = ws2812_encode;
    self->base.reset  = ws2812_reset_encoder;
    self->base.del    = ws2812_del_encoder;

    rmt_bytes_encoder_config_t bytes_cfg = {
        .bit0 = { .level0 = 1, .duration0 = T0H_TICKS,
                  .level1 = 0, .duration1 = T0L_TICKS },
        .bit1 = { .level0 = 1, .duration0 = T1H_TICKS,
                  .level1 = 0, .duration1 = T1L_TICKS },
        .flags.msb_first = 1,
    };
    esp_err_t err = rmt_new_bytes_encoder(&bytes_cfg, &self->bytes_encoder);
    if (err != ESP_OK) goto fail;

    rmt_copy_encoder_config_t copy_cfg = {0};
    err = rmt_new_copy_encoder(&copy_cfg, &self->copy_encoder);
    if (err != ESP_OK) goto fail;

    self->reset_symbol = (rmt_symbol_word_t){
        .level0 = 0, .duration0 = RESET_TICKS / 2,
        .level1 = 0, .duration1 = RESET_TICKS / 2,
    };

    *out_enc = &self->base;
    return ESP_OK;

fail:
    ws2812_del_encoder(&self->base);
    return err;
}

/* ---- Driver state ---- */
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

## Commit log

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2026-04-06 Mark operating agreement signed and add ESP32 module research
    - Operating agreement updated to finalized/printed/signed (Apr 6)
    - Business bank account unblocked in sprint log (operating agreement complete)
    - ESP32-C3-MINI-1 selected as v1.0 MCU: smallest footprint, cheapest (~$2 LCSC), wide availability, built-in USB/JTAG
    - C6 variant (Zigbee/Thread/Matter) deferred pending customer survey on smart home usage
    - Added docs/esp32-module-comparison.md: full 21-module spec table across 4 tables
    - Added docs/esp32-module-shortlist.md: focused S/W analysis for shortlisted modules with decision rationale
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2026-04-14 Add Assembly_docs: 20-station production line detail and time calculator
    - LED_Mirror_Station_Details.csv — full per-station spec (tools, fixtures,
    consumables, inputs/outputs, QC criteria) for all 20 production stations
    - LED_Mirror_Assembly_Calculator.xlsx — per-unit time calculator with Time
    Standards, Unit Calculator, and Batch Planner sheets
    [LED_Mirror_Assembly_Calculator.xlsx, LED_Mirror_Station_Details.csv]
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2026-04-20 Lock Week 4 brand decisions: hybrid palette, italic-default type, Berkeley Mono, "[X] that layers" tagline motif
    - Fix overlapping label text in palette-hybrid-recommended.svg (bump viewBox + reflow row spacing)
    - Lock hybrid palette; preserve Option B and C analyses for reference
    - Lock typography: ExtraLight Italic as default posture, upright reserved for emphasis and section gear-shifts
    - Lock Berkeley Mono as technical accent (Diatype's R tail rejected, JetBrains deprioritized)
    - Lock "Light that layers." as infinity-mirror tagline; "[X] that layers" as parent-brand motif extending to consulting ("data that layers") and future lines
    - Note logo work is happening in Bill's P5.js repo (lin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
2026-04-20 Week 4 log + index update: brand track substantially locked
    - sprint_log Week 4: Done entries for brand positioning worksheet, palette swatches, Obsidian vault restructure, assets scaffold, and P5 logo repo review
    - index.md: Right Now section reframed around the locked brand track; resolved brand-architecture open question; added pending items (type specimen, moodboard images, right-to-repair philosophy)
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2026-04-22 Week 4 Apr 22: firmware architecture block locked + compliance
    Compliance:
    - BOI Report confirmed exempt under FinCEN interim final rule (US-domestic entities)
    - WA BLS registration filed (Retailing + Manufacturing, NAICS 335129, UBI issued)
    Firmware architecture (Apr 22 focus block) — all 5 §5 decisions locked:
    - 5.1 ESP-IDF with C (not C++)
    - 5.2 BLE + SoftAP via wifi_prov_mgr, user-initiated only, radios dark at rest
    - 5.3 Two-variant split: Pro (no Matter) + Pro+ (uncertified Matter, test VID 0xFFF1),
    shared core library, Matter on Pro+ only. Three-tier product line: Basic/Pro/Pro+
    - 5.4 Self-hosted OTA on Cloudflare + R2 at ota.layeredlogic.cc, ECDSA-signed,
    A/B partitio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
    [c3_devkit.h, c6_devkit.h, main.c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]
2026-04-22 Week 4 Apr 22: firmware v1 bring-up — state_bus, button, led_driver, pattern_interp + host tests
    Greenfield ESP-IDF firmware moves from blink-level scaffold to a runnable
    end-to-end loop. Four core modules + cross-firmware reference docs + a
    host-side CMake test harness.
    Modules (Firmware/v1/core/):
    - state_bus/ — single-writer esp_event loop; LL_EV_STATE_CHANGED broadcast,
    transient events at 0x1001+ pass through without mutation
    - button/ — debounced ISR + FreeRTOS task; primary (single/double/triple/
    hold) + recessed (3s provision / 10s factory reset). Pure
    logic split into button_logic for host testing
    - led_driver/ — RM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
    [button.c, button_logic.h, led_driver.c]
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2026-04-22 Firmware v1 nvs: persist ll_state_t across reboots
    New core/nvs component owns the "ll_settings" namespace. Adds a
    host-testable pure-C split (nvs_logic) + ESP-IDF runtime (nvs.c):
    - Schema-versioned packed blob (44 bytes), discard-on-mismatch — no
    migrations yet, but the version field lets us add them later without
    bricking units.
    - Deserialize hard-fails on NULL/wrong-size/schema mismatch; soft-
    sanitizes weird-but-non-fatal values (brightness clamp, led_count
    bounds, auth_mode enum check, pattern_id defaults, color upper-byte
    mask).
    - Target-side subscribes to LL_EV_STATE_CHANGED and coalesces saves
    through a 2s esp_timer debounce so rapid brightness dial / color
    cycles d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
    [main.c]
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2026-04-27 Right-to-repair finalized + 17-file failure mode inventory
    Finalize the right-to-repair philosophy doc (draft → complete) and
    build out the full failure mode inventory for every v1.0 component.
    17 individual files across 8 categories (LED strip, PSU, controller,
    acrylic, frame, PETG, wiring, buttons) — each with symptoms, causes,
    repair paths, parts sourcing, and design mitigations. 12 fully
    user-repairable, 5 partial, 0 non-repairable.
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2026-04-28 Week 5 Apr 28: app mini-sprint locked + V1 firmware pre-flash fixes
    Apr 22 parked app decisions resolved. Path A + B + C committed for the
    May 5 advisor demo (transport + device-hosted webapp + RN Android app).
    Stack: bare RN, Preact + Vite webapp, esp_http_server transport, cJSON,
    phone hotspot for the demo network, open-mode auth (HMAC stays optional
    in the envelope so this incurs zero protocol debt). Demo board is the
    existing C3 dev kit; webapp captive portal handles all provisioning and
    RN skips BLE for V1; pattern editor stays out as V2. New planning doc
    docs/mini-sprint-app-demo.md tracks the 8-session breakdown, hardware
    safety rules (no eFuse burns, no secure boot, no flash encrypti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
    [button.c, c3_devkit.h]
2026-04-28 Session 0: first V1 flash on real silicon (XIAO ESP32-C3)
    Two bugs surfaced during boot of the V1 firmware on the XIAO ESP32-C3
    prototype and were patched in-session:
    1. pattern_interp render task was pinned to core 1, but the C3 is
    Unicore — xTaskCreatePinnedToCore asserts on xCoreID < 1 and
    panics mid-init (after led_driver init, before button init).
    Fix: TASK_CORE 1 -> 0. Comment notes that C3 + C6 are both
    single-core from FreeRTOS's POV (C6's low-power core isn't
    scheduled), so 0 is universally correct for our targets.
    2. state_bus_defaults.c::ll_state_defaults had led_count = 32
    hardcoded, which propagated through nvs.c's first-boot path and
    overrode c3_devkit.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
2026-04-29 Session 2 milestone: cross-client state broadcasts
    Closes Session 2 of the app demo mini-sprint. The full webapp/RN/
    wscat triangle now stays in sync: any client can change state, every
    other client sees the new state within ~70ms. Foundation for the
    demo-day cross-client requirement (webapp + phone open simultaneously,
    change from one, the other UI updates within 200ms).
    Two surface additions to core/transport/transport.c:
    - broadcast_state(): builds {op:"state", ts, state:{...}} envelope per
    control-protocol-spec.md §3.3, enumerates open sockets via
    httpd_get_client_list, filters to WebSocket clients via
    httpd_ws_get_fd_info, pushes via httpd_ws_send_frame_async. Failed
    sends pe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
2026-04-29 Session 4 milestone: all 5 webapp capabilities + bundle gate green
    Brightness (continuous 0-100, commit-on-release with smooth-thumb local
    state), pattern (7 builtin IDs in a select), on/off (brightness 0 vs.
    restore-last-active), factory reset (UI mockup; wire op deferred to
    later in the sprint per scope call). WS client gained reconnect with
    exponential backoff. Bundle: 9.87KB gzipped, ~12% of the 80KB budget.
    Documented gap: transient socket-closed errors under rapid user load.
    Likely esp_http_server single-task backpressure; reconnect handles the
    symptom. Real fix is post-demo.
2026-04-29 Open post-mini-sprint bug backlog with #1: transient socket closes
    Captures the WS reliability issue surfaced during Session 4's brightness
    slider work as a tracked bug rather than just an inline sprint_log note.
    Triage queue for after the May 5 advisor demo. Includes severity,
    hypothesized root cause (esp_http_server single-task backpressure), repro
    steps, and ranked candidate fixes.
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2026-04-29 Session 5 sub-2: spike confirms mDNS-over-hotspot for webapp demo path
    Hardcoded-creds spike (RAM-only, never committed) put the device on
    Bill's Pixel 9 hotspot to test whether the mDNS hostname resolves
    across the hotspot's network. Verdict: yes for PC + browser, exactly
    the May 5 demo topology. Phone-side mDNS deferred to Sessions 6-8
    when react-native-zeroconf is in play.
    Two surprises caught + fixed during the spike: (1) chat-typo'd SSID
    ("Bils" vs "Bills") that produced NO_AP_FOUND, (2) Windows' aggregate
    wifi scan only showed the 5GHz BSSID for the dual-band hotspot — the
    C3's own scan found a 2.4GHz BSSID on channel 11 once the SSID
    matched. Lesson: trust the C3's scan, not netsh'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
2026-04-29 Session 5 sub-3: captive-portal DNS hijack + HTTP 404 redirect
    New core/captive_dns/ component runs a tiny UDP DNS responder on :53
    that answers every A query with 192.168.4.1, gated to AP mode via
    esp_wifi_get_mode() so it doesn't intercept real DNS when the device
    is on a real network. webapp_assets gains an httpd 404 err handler
    that 302-redirects every unknown URI to /, catching the OS-specific
    captive-portal probe URLs (Android /generate_204, iOS
    /hotspot-detect.html, Windows /connecttest.txt) without us having to
    enumerate them.
    Verified on silicon: arbitrary DNS queries return 192.168.4.1; all
    three OS probe shapes get redirected to /; embedded webapp still
    serves cleanly on /.
    Bug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
    [main.c]
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2026-04-30 Session 5 sub-4: setup screen, fallback timer, control coupling fixes
    Closes Session 5's DoD: webapp end-to-end demo flow works on real
    hardware. Real Pixel-9 hotspot creds verified — submit via /setup,
    device joins, mDNS resolves on the new netif, all 5 capabilities work
    on http://layered-logic-mirror-b2332c.local/ from the laptop. Garbage
    creds verified too — 15s firmware-side fallback wipes them and
    restarts the SoftAP automatically, so a typo'd password no longer
    strands the device.
    Firmware:
    - on_wifi_apply_creds handler in core/provisioning/ does the async
    SoftAP -> STA handoff with a 250ms response-flush delay so the JSON
    ok=true reaches the webapp before the AP dies
    - 15s g_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
2026-04-30 Session 6-8 collapsed: bare RN app + 5 controls live against silicon
    What was scheduled as three sessions (Fri-Sun May 1-3) landed in one
    ~2.5h morning. RN scaffold at App/v1/, protocol.ts + ws-client.ts
    ported from webapp verbatim (the framework-free design call from
    Session 3 paid off), single-screen UI with on/off + color (9 swatches)
    + brightness (4 steps) + pattern (7 IDs) + factory reset, all driving
    the XIAO ESP32-C3 mirror over Bill's Pixel 9 hotspot from a Pixel 9
    Pro AVD. Demo-day RN gate satisfied 5 days ahead of May 5.
    Three Windows-specific build wedges fixed in succession before APK
    #4 went green in 44s:
    - gradlew.bat needs PowerShell, not git-bash, for current-dir batch
    res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
2026-04-30 RN app: provisioning, Find Mirror, brand pass, first physical install
    Builds on this morning's RN scaffold to close the May 5 demo's RN
    side. Mirror is reachable, controllable, and re-provisionable from
    the LLogic app on a Pixel 9 — full factory-reset → re-provision →
    control round-trip verified end-to-end on real silicon over a
    real (second-phone) hotspot.
    Provisioning UI:
    - Setup screen at App.tsx auto-renders when state.provisioning_active
    is true. SSID + password form with show/hide toggle and WPA2-length
    validation. Submits via the existing setWifiCreds wire op (landed
    Session 5 sub-4); device tears down SoftAP within ~100ms of ack.
    - 15s post-submit countdown matches firmw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
2026-04-30 HCDE: repair portfolio rationale (3 docs) + brand §1 lock
    Closes the Week 4 carryover for the HCDE portfolio's repair story
    and locks the last open piece of the brand-positioning worksheet.
    Three new docs in docs/ that turn the existing right-to-repair
    philosophy + failure-mode inventory into a portfolio-ready artifact
    set:
    - repair-design-decisions.md — 20-row decision matrix mapping
    specific design choices to five repair values (Reopenable,
    Commodity, Self-recovery, Long-life, OTA-fixable) and the
    failure modes each pre-empts. Format forces every row to
    terminate at a specific failure-mode link and a specific spec
    doc, not at narrative.
    - repairability-scorecard.md — quan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
2026-04-30 firmware: welcome sequence + OTA module + start_ota op (V1)
    Welcome sequence in pattern_interp.c — 4-tick additive fill at boot,
    synchronous between led_driver_init and the render task spinning up.
    Bright white at 100% brightness, deliberately distinct from any
    normal pattern so it's unambiguous as a boot animation. Doubles as
    the OTA-success canary (next OTA bumps the welcome color so the swap
    is visually self-verifying). Breakpoints derived from led_count so
    the sequence scales — c3_devkit (66 LEDs) hits [15,32,49,66],
    prod_v1_pro (32 LEDs) would hit [8,16,24,32].
    OTA module at core/ota/ — minimal HTTP-pull dev-test path. Wraps
    esp_https_ota with a single ll_ota_start(url) entry poi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
2026-04-30 OTA cycle V1→V2 verified + LLogic Settings page
    V2 firmware:
    - Welcome sequence color bumped white → cyan as the OTA-success
    visual canary. V1 ships white, V2 cyan; the visible difference
    is the proof the OTA actually replaced the running code.
    - sdkconfig.defaults: CONFIG_ESP_HTTPS_OTA_ALLOW_HTTP=y. Plain HTTP
    URLs are rejected by esp_https_ota with ESP_ERR_INVALID_ARG
    unless this is set. Production OTA flips it back off and uses
    HTTPS exclusively per firmware-architecture-scoping §5.4.
    LLogic app — Update firmware UI:
    - New MirrorClient.startOta(url) method. Treats socket-closed /
    timeout from start_ota as the success signal (the device reboots
    before any response sen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
2026-05-01 RN+firmware: cleartext fix, native mDNS, ip in DeviceState, multi-net spec (#6)
    Three architectural fixes that took the RN release APK from "unable to load
    script" to standalone-installable end-to-end on the C3 prototype:
    - Cleartext-traffic block on release builds. RN's gradle plugin was forcing
    usesCleartextTraffic=false via finalizeDsl, clobbering any build.gradle
    override. Hardcoded the manifest entry to "true" so the placeholder
    substitution becomes a no-op. Mirror is local-network http/ws only; NSC
    doesn't accept CIDR ranges so the global flag is the right pattern here.
    - mDNS-based mirror discovery via Android's NsdManager (new MdnsModule.kt)
    replaces the prior 254-paralle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
2026-05-06 tasks: introduce stable LL-NNN registry + append-only event log (#7)
    Replaces slug-based task identity (which produced false-close cascades in
    the downstream collector when titles were renamed or tasks slipped sprints)
    with a structured registry of stable, immutable IDs.
    - docs/task-format-v2.md — design spec covering ID scheme, file layout,
    schema per file, migration plan, examples, and downstream composite
    format. Captures all locked decisions: dash-separated hierarchy
    (LL-NNN-M-K — dots avoided for anchor-renderer safety), [x]/[ ] as the
    completion signal, four date fields (added/first_engaged/last_engaged/
    resolved), sprint field tied to started-in sprint, ne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
2026-05-08 LL-046 multi-network firmware + LL-050 supply-chain map + LL-073 RN app polish (#9)
    * firmware: drive STA from ll_wifi multi-network store (LL-046 steps 1+2)
    Implements the first 2 of 6 steps from docs/multi-network-design.md.
    core/ll_wifi/ is a new NVS-backed credential store (logic-vs-target
    split mirrors core/nvs/) and core/provisioning now drives STA from
    it instead of esp_wifi's single saved cred — esp_wifi's NVS becomes
    vestigial via WIFI_STORAGE_RAM after a one-time migration of any
    legacy cred into ll_wifi[0] per design-doc §5.3.
    set_wifi_creds writes to ll_wifi first then drives the existing
    SoftAP→STA handoff; the apply-creds fallback now removes the failed
    entry from ll_wif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
    [main.c]
2026-05-11 Assembly_docs: add Basic Infinity Mirror PCB housing (matplotlib + Fusion) (#10)
    Initial design for the snap-fit 3D-printed enclosure around the STM8 basic
    mirror PCB. Tight 34.8 x 25.7 x 13.0 mm housing with USB-C and button cap on
    the +Y face, JST plug pull-out through the lid, two split-column snap pegs
    through the PCB mounting holes, and lid snap tabs on the short walls.
    Includes the matplotlib layout sign-off (sketch_housing_layout.py +
    housing_layout_v1.png) and the parametric Fusion 360 script (basic_housing.py,
    plus the wrapped basic_housing/basic_housing.py for the Fusion script picker).
2026-05-11 basic_housing v2: raise button to USB cap height + move snaps inside (#11)
    - Button cap Z now anchored to USB-C cutout center so the two features sit
    at the same height on the +Y face (was sitting near the floor in v1).
    - Add a built-in retainer block joined to the tray that wraps the suspended
    button body on top/bottom/±X. Open on -Y for insertion from the housing
    interior; +Y face meets the inner wall where the cap hole goes through.
    - Lid snap tabs moved from outside the ±X walls to INSIDE, with barbs
    projecting outward into the through-slots. Tabs lengthened (4→6 mm) and
    barb projection reduced (0.8→0.5 mm) to keep insertion force reasonable
    given inside cantilevers are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
2026-05-11 basic_housing: fix _cyl_y Z axis on Fusion's xZ sketch plane (#12)
    * basic_housing v2: raise button to USB cap height + move snaps inside
    barb projection reduced (0.8→0.5 mm) t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
2026-05-11 basic_housing: mirror snap peg X positions (#13)
    barb projection reduced (0.8→0.5 mm) to keep insertion f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
2026-05-12 basic_housing: X-mirror the entire layout instead of just the pegs (#14)
    Mirroring just the pegs (PR #13) put the pegs in the right place but left
    the button at the BACK of the frame (low world X). Bill wants the button at
    the FRONT.
    Revert the peg X-mirror and instead flip the whole PCB-to-world X mapping
    in pcb_to_world (PCB +X -> world -X) plus relocate the button extension
    from the low-X end of the housing to the high-X end. Net result:
    - PCB hole values back to Bill's originals (22.15, 17.5) and (3.25, 9.5)
    - Pegs land at world (3.68, 4.2) and (22.58, 12.2) — same as PR #13
    - Button cap moves from world X=-3 to X=28.83 (now at FRONT of frame)
    - Components mirror in X: SW1 swaps to hi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
2026-05-12 basic_housing: 6x6 button cavity + Y-split snap pegs (#15)
    * basic_housing: X-mirror the entire layout instead of just the pegs
    - Button cap moves from world X=-3 to X=28.83 (now at F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
2026-05-15 Firmware: LL-055 resilience hardening + LL-057/LL-075 telemetry + state polish (#20)
    * LL-055: Wi-Fi/WS resilience hardening + test harness
    Three firmware fixes (provisioning.c + transport.c) and a five-script
    test harness that closes bug-doc #1 (transient socket-closed under
    user load) end-to-end. All four fixes the bug doc proposed are in:
    - WIFI_PS_NONE on the STA path. New ll_wifi_disable_ps() called
    after each esp_wifi_start. First-response RTT 155 -> 84 ms.
    - Broadcast fanout on a dedicated FreeRTOS task with a depth-2
    queue. Slow-client TCP backpressure no longer reaches the
    esp_timer task or the httpd inbound path. Verified by
    ll_slow_client_test.py: 20/20 respo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
    [main.c]
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2026-05-21 Week 8: proto SoftAP fallback + single-button factory reset (LL-079, LL-080)
    Two demo-blocker firmware fixes for the recessed-button-less C3 proto:
    - LL-079: provisioning.c brings up an APSTA SoftAP after the STA
    connection state machine fails ~2 backoff cycles, so the mirror stays
    reachable at 192.168.4.1 when no saved network is in range. The STA
    side keeps scanning and reconnects if a network reappears. Proto-only
    override of the RF-minimal stance; V2 gates it behind a gesture.
    - LL-080: new factory_combo_step() recognizer -- 5s hold / short press /
    5s hold on the primary button posts LL_EV_FACTORY_RESET, reusing the
    existing red/green confirmation cue. 8 new host tests.
    Bui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
    [button.c, button_logic.h]
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2026-05-21 Week 8: proto SoftAP fallback + factory-reset combo + LED-count fix (#24)
    * LL-069: close tax-filing setup, spawn quarterly-return children
    WA DOR welcome letter (May 15, 2026) confirmed Layered Logic LLC is on
    quarterly excise filing (not annual as initially assumed when the account
    was added to the My DOR portal May 14). First return is Q1 2026, due
    Jun 15, 2026 under a one-time extension; standard cadence after that is
    Apr 30 / Jul 31 / Oct 31 / Jan 31. Zero-activity returns are required
    even with no sales.
    Closes LL-069 (setup complete: portal access live, schedule known,
    e-file requirement understood) and spawns LL-069-1 through LL-069-4 as
    the recurring quarterly filing obligations.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
    [button.c, button_logic.h]
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2026-08-18 STM8 firmware: fix the LED data pin, add CC sense, UART debug and IR
    Targets the reworked Infinity_Mirror_STM8 board (its REWORK_SPEC.md "Pass 2").
    THE IMPORTANT ONE: LED data was PC7 (physical pin 17) in both the firmware
    and its spec. The PCB has routed /LED_SIG from PC6 (pin 16) since the
    5bc9107 baseline -- verified across all three board revisions -- so as
    written this drove a pin that goes nowhere and the strip stayed dark. One
    define, but nothing else in here matters until it is right.
    CC sense: both CC lines read once a second through the new 22k series
    resistors on PD2 (AIN3) and PD3 (AIN4); the higher reading is the mated
    orientation. Decoded to a source tier and turned into a ha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
    [stm8_150mm.ino]
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2026-08-24 STM8 firmware: bare-metal SDCC rewrite for the rev-2 board (flashed, running)
    Replaces the sduino sketch for the 25x47 rev-2 controller. Same product
    contract -- 13 colours, 7 patterns, single/double/triple/long, white
    auto-dim, EEPROM state across off->on but not a power cycle. Flashed with
    an ST-LINK/V2 through ST Visual Programmer and confirmed on hardware.
    Off Arduino because SDCC only emits an interrupt vector-table entry for
    handlers declared in the translation unit holding main(). Under sduino
    main() is the core's, and its stm8s_it.h has TIM2_CAP_COM commented out
    for the STM8S003 -- so the pass-2 sketch's IR ISR was dead code by
    construction. build.sh now fails if the vector is miss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
    [button_logic.h, main.c]
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2026-08-26 Firmware v1: prod_v1_pro board header from real hardware, and a release build
    prod_v1_pro.h: filled in from the shipped Y11 netlist and CONFIRMED on board #1
    during first-article bring-up. LED_DATA=10 (NOT GPIO2 - stock WLED's C3 default
    is a strap tied to +3V3 here), BUTTON_PRIMARY=9 shared with the boot strap,
    BUTTON_RESET=-1 because SW1 is wired to hardware EN and firmware cannot read it,
    LED_POWER_EN=-1 (no rail gate on rev 1 - a rev-2 candidate). Plus I2C/VBUS-sense/
    PG extras, the reserved-pin list, and a note that GPIO0/1 are the two free pins.
    The #error is removed; the target builds and runs.
    Release build: the project was compiling at -Og with full assertions, INFO
    logging, the es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
    [prod_v1_pro.h]
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
